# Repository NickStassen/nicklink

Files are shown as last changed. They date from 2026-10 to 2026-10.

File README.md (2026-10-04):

# NickLink v1.3

NickLink is a compact STM32F103C8T6 development and breakout board. Version 1.3 is a **34.0 × 25.5 mm, two-layer PCB** with an on-board **6-axis IMU (ST LSM6DSV)** for motion tracking, robotics and tap-to-wake projects. It also has two **2×10, 2.54 mm headers**, **four M2 mounting holes**, USB-C, RESET and BOOT buttons, a user LED, and **every header pin labelled on the front silkscreen**.

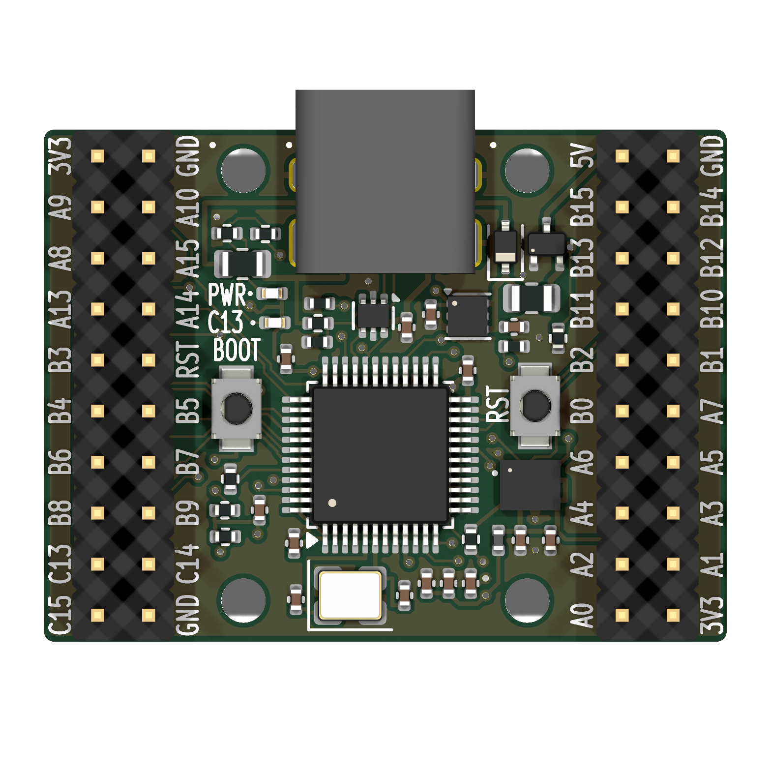
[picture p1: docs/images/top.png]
NickLink v1.3 — component side


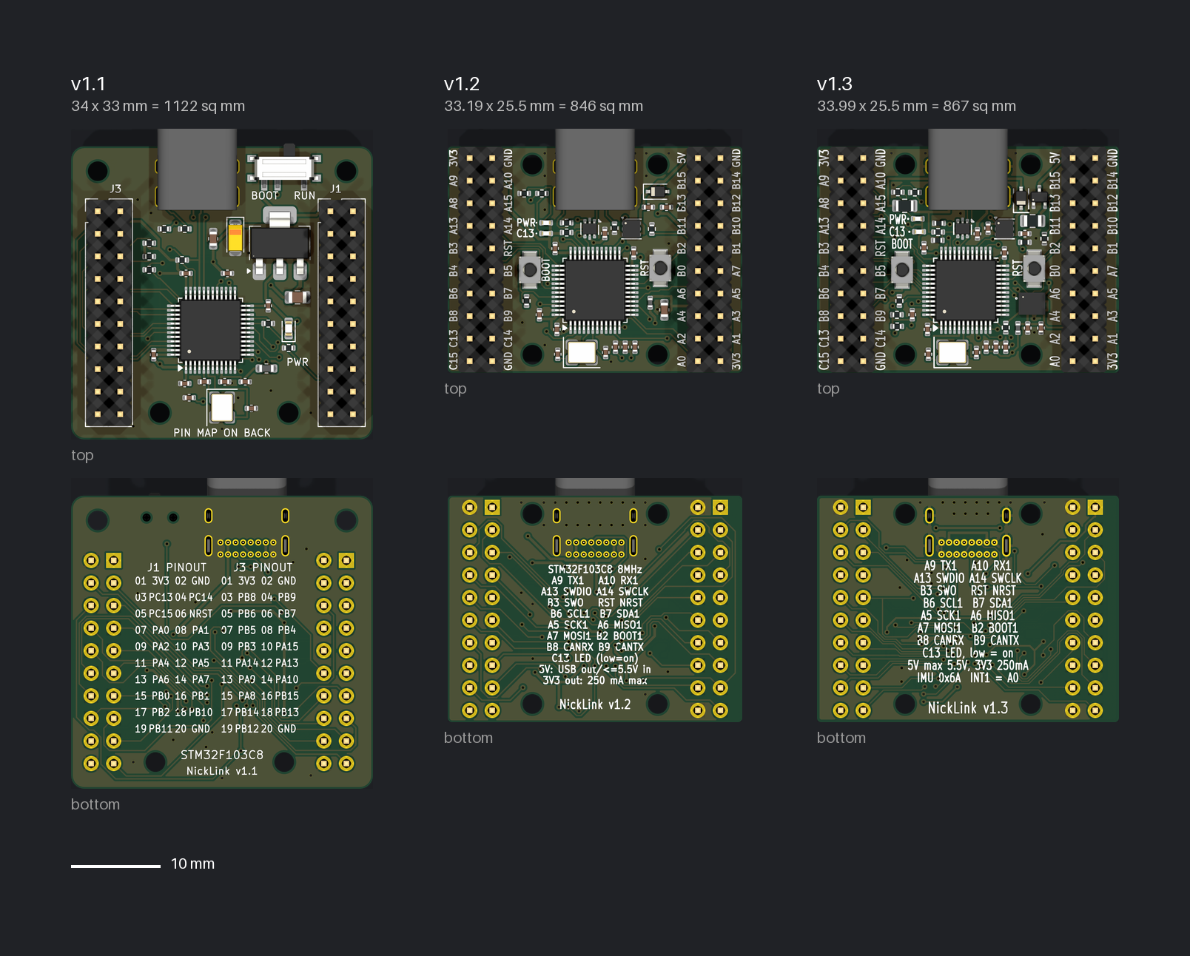
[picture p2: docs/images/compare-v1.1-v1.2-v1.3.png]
v1.1, v1.2 and v1.3 at the same scale


<details><summary>True size on a 27-inch 1440p monitor (view at 100% zoom)</summary>

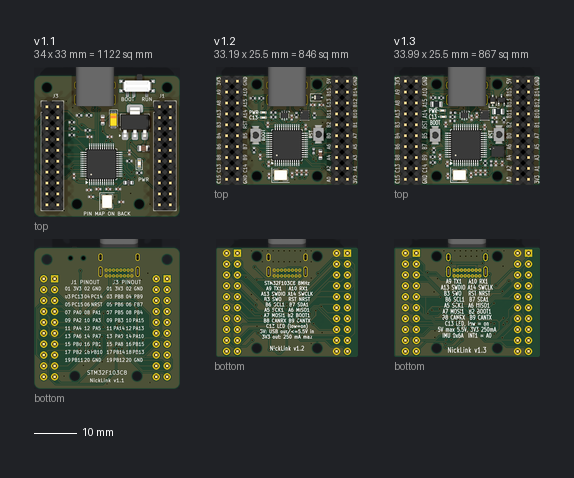
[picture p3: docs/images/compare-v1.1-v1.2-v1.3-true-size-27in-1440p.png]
v1.1, v1.2 and v1.3 at true size on a 27-inch 1440p monitor


</details>

**New board?** Follow the [bring-up guide](docs/BRINGUP.md): wiring for an STLINK-V3MINIE, a prebuilt test firmware and a checklist for every part.

## What changed

**v1.3** adds the IMU on I2C1. It fits into existing gaps beside the MCU, on the top side with single-sided assembly. The board is 0.8 mm wider than v1.2 only because the pin labels grew to JLC's 1.0 mm minimum text height (see [JLCPCB design rules](#jlcpcb-design-rules)). PB6/PB7 get 4.7 kΩ pull-ups again, because the bus now has an on-board device. The IMU's INT1 drives PA0. The 3V3 budget drops by about 1 mA for the IMU. Everything else is as in v1.2.

**v1.3 reliability pass** (from a five-reviewer audit, the SPICE benches in [`sim/`](sim/) and ST's AN2586/AN4879 checklists):

- **Hot-plug damping:** R12, 1 Ω in series with VBUS, holds the USB hot-plug peak to 5.38 V and inrush under 50 µC. A ring on the 5V pin can still go higher. The regulator survives that because it is the 18 V TLV76733, not because every peak stays under 6 V.
- **Protected 5V pin:** J1.1 now has a 0.5 A polyfuse (F1) and a reverse-polarity P-MOSFET (Q1), so a short or a reversed supply no longer reaches VSYS unprotected.
- **D+ pull-up from VBUS** (AN4879 §3.1.1): it is present only while USB is plugged in. Powering from J1.1 no longer back-feeds the host.
- **Decoupling:** C4 at VDD3 is now 4.7 µF, as DS5319 requires. C12 (LDO input) is 4.7 µF, to keep inrush down.
- **User LED:** R6 is 330 Ω: about 1.3 mA instead of 0.4 mA, still within PC13's 3 mA sink limit.
- **Routing:** locked tracks for the USB-C orientation ties and the IMU's 3V3 feed. Every GND pad and pour island is checked for connection.

**Revision comparison:**

| | v1.1 | v1.2 | v1.3 |
|---|---|---|---|
| Outline | 34 × 33 mm (1122 mm²) | **33.19 × 25.5 mm** (846 mm², −25%) | **33.99 × 25.5 mm** (867 mm², −23%) |
| Pin labels | Numbered table on the back | **Name beside every pin on the front**; cheat sheet on the back | Same; 1.0 mm text (JLC minimum) |
| 5 V on the headers | None | **J1.1 = 5 V** (USB VBUS through a Schottky; also a 5 V input) | Same, plus a **0.5 A polyfuse and reverse-polarity protection** |
| USB power path | VBUS straight to the regulator | Schottky | **1 Ω hot-plug damping** + Schottky |
| Regulator | AMS1117-3.3 (SOT-223) + 22 µF tantalum | **TLV75533** (2×2 mm WSON) + ceramics | **TLV76733**, same package, input rated to 18 V |
| Reset | Header pin only | **RESET button** + NRST on J3 next to SWD | Same |
| Boot | BOOT0 slide switch | **BOOT button** (hold BOOT, tap RESET) | Same |
| SWD | Split across J1 and J3 | **All on J3**: 3V3, GND, SWDIO, SWCLK, SWO, NRST | Same |
| HSE crystal | 16 MHz | **8 MHz** (matches Blue Pill / STM32duino / CubeMX defaults) | Same |
| USB D+ pull-up | 1.5 kΩ to 3V3 | 1.5 kΩ to 3V3 | **From VBUS** (2.2k/4.7k), so no back-feed when powered from J1.1 |
| USB ESD | None | **USBLC6-2P6** on D+/D− and VBUS | Same |
| I2C pull-ups | 1.5 kΩ fitted on PB6/PB7 | Removed | **4.7 kΩ** (needed by the on-board IMU) |
| LEDs | Power | Power + **user LED on PC13** (low = on) | Same, brighter (330 Ω, about 1.3 mA) |
| IMU | — | — | **LSM6DSV** 6-axis accel + gyro with on-chip sensor fusion |
| Verification | — | DRC/ERC | DRC/ERC, SPICE benches ([`sim/`](sim/)), emulated test firmware ([`firmware/`](firmware/)) |

## Hardware

- STM32F103C8T6 (LQFP-48) with an 8 MHz crystal (12 pF load, 15 pF C0G caps): PLL ×9 = 72 MHz, USB clock 72 / 1.5 = 48 MHz.
- USB-C (GCT USB4085, through-hole) for power and USB full speed; 5.1 kΩ CC pull-downs for either orientation; D+ pull-up from VBUS (2.2 kΩ / 4.7 kΩ divider, 1.5 kΩ to 3.4 V, so it is present only while USB is plugged in); USBLC6-2P6 ESD array.
- Power path: USB VBUS → R12 1 Ω (hot-plug damping) → 1N5819WS Schottky → **VSYS** → TLV76733 LDO → **3V3** (J3.1, J1.20). VSYS also reaches the **5V pin** (J1.1) through a 0.5 A polyfuse (F1) and a reverse-polarity P-MOSFET (Q1). The Schottky stops a supply on the 5V pin from back-feeding the USB host.
- RESET button (NRST to GND, 100 nF), BOOT button (BOOT0 to 3V3, 10 kΩ pull-down), 10 kΩ pull-down on PB2/BOOT1.
- Red power LED, green user LED on PC13 (active low).
- **IMU:** ST LSM6DSV 6-axis accelerometer and gyroscope on I2C1 (PB6 SCL / PB7 SDA, address **0x6A**), INT1 to PA0.
- 33 GPIO + NRST on the headers. Only PA11/PA12 (USB) and PD0/PD1 (crystal) are not broken out.
- GND pours on both layers, stitched with vias.

## Header pinout

**Top view, USB at the top: J3 is left, J1 is right.** Pin 1 is the square pad at the upper left of each header; odd pins are the left column. The front silkscreen prints each pin's name right beside it (`A9` = PA9, `B12` = PB12, `RST` = NRST).

| Pin | J3 (left) | J1 (right) |
|---:|---|---|
| 1 | `3V3` 3V3 regulated output | `5V` 5 V (USB VBUS through Schottky + 0.5 A polyfuse; 4.5–5.5 V input, reverse-polarity protected) |
| 2 | `GND` | `GND` |
| 3 | `A9` PA9 / UART1 TX | `B15` PB15 / SPI2 MOSI |
| 4 | `A10` PA10 / UART1 RX | `B14` PB14 / SPI2 MISO |
| 5 | `A8` PA8 | `B13` PB13 / SPI2 SCK |
| 6 | `A15` PA15 | `B12` PB12 |
| 7 | `A13` PA13 / SWDIO | `B11` PB11 / I2C2 SDA / UART3 RX |
| 8 | `A14` PA14 / SWCLK | `B10` PB10 / I2C2 SCL / UART3 TX |
| 9 | `B3` PB3 / SWO | `B2` PB2 / BOOT1, 10k pull-down |
| 10 | `RST` NRST (reset, active low; 3.3 V only) | `B1` PB1 (3.3 V only) |
| 11 | `B4` PB4 | `B0` PB0 (3.3 V only) |
| 12 | `B5` PB5 (3.3 V only) | `A7` PA7 / SPI1 MOSI (3.3 V only) |
| 13 | `B6` PB6 / I2C1 SCL (4.7k pull-up, IMU; 3.3 V only) | `A6` PA6 / SPI1 MISO (3.3 V only) |
| 14 | `B7` PB7 / I2C1 SDA (4.7k pull-up, IMU; 3.3 V only) | `A5` PA5 / SPI1 SCK (3.3 V only) |
| 15 | `B8` PB8 / CAN RX (remap) | `A4` PA4 (3.3 V only) |
| 16 | `B9` PB9 / CAN TX (remap) | `A3` PA3 / UART2 RX (3.3 V only) |
| 17 | `C13` PC13 / user LED (3.3 V only) | `A2` PA2 / UART2 TX (3.3 V only) |
| 18 | `C14` PC14 (3.3 V only) | `A1` PA1 (3.3 V only) |
| 19 | `C15` PC15 (3.3 V only) | `A0` PA0 / WKUP / IMU INT1 via 10k (3.3 V only) |
| 20 | `GND` | `3V3` 3V3 regulated output |

Pins not marked "3.3 V only" are 5 V tolerant (FT) while the board is powered. B6/B7 are FT on the MCU but not at board level, because the IMU on that bus is limited to 3.6 V. PA1–PA7, PB0 and PB1 are also ADC inputs. PA0 is too, but it has the IMU interrupt on it (below). [`docs/pinout.csv`](docs/pinout.csv) has the same table in machine-readable form.

- **SWD:** J3.1 3V3 (target voltage sense), J3.2 GND, J3.7 SWDIO, J3.8 SWCLK, J3.10 NRST, optional J3.9 SWO.
- **Serial bootloader:** hold BOOT, tap RESET, release BOOT, then use USART1 on J3.3 (TX) / J3.4 (RX). This is ST's factory USART bootloader; the F103 has no factory USB DFU bootloader.
- **I2C1 / IMU:** I2C1 has on-board 4.7 kΩ pull-ups. External I2C modules can share the bus as long as they avoid address 0x6A and **pull up to 3.3 V only**. A 5 V module needs a level shifter, because the IMU's SCL/SDA limit is 3.6 V. If modules bring their own pull-ups, keep the combined value above about 1.5 kΩ. The 4.7 kΩ pull-ups meet the 400 kHz rise-time limit up to about 75 pF of bus capacitance (roughly 30 cm of wiring plus a few modules); for longer runs, use 100 kHz.
- **A0 has the IMU's INT1 on it through 10 kΩ.** INT1 drives low whenever no interrupt is asserted, so A0 always sees a 10 kΩ pull-down (also with INT1 set to open-drain, which only releases the pin while active-high). The interrupt is active high, matching WKUP's rising edge. You can still drive A0 from outside, or use it as an ADC input from a low-impedance source. Making A0 truly high-impedance needs INT1 set active-low open-drain (`H_LACTIVE` + `PP_OD`, IF_CFG 03h), which inverts the interrupt and stops it from waking the MCU through WKUP.
- **J3.6/J3.9/J3.11 (PA15/PB3/PB4) are JTAG pins at reset:** PA15 and PB4 have internal pull-ups and PB3 (JTDO/SWO) has none, until firmware frees them (`__HAL_AFIO_REMAP_SWJ_NOJTAG()` keeps SWD and releases them). PA13/PA14 stay SWD unless you disable SWJ completely, after which the debugger has to connect under reset (NRST is on J3.10).
- **User LED:** PC13 low turns it on. PC13–PC15 are low-drive pins (≤2 MHz) and must not source current. Their 3 mA sink limit is shared by all three pins (DS5319 Table 5), and the LED already takes about 1.3–1.8 mA of it. J3.17 carries the LED load, so an undriven PC13 floats around 1–1.5 V.

## IMU

The LSM6DSV is a 6-axis IMU: accelerometer up to ±16 g, gyroscope up to ±4000 dps.
- **Address:** I2C1 at 0x6A (SA0 tied low); CS is tied high for I2C mode.
- **Interrupt:** INT1 goes to PA0. PA0 is also the STM32's WKUP pin, so a tap or motion interrupt (rising edge) can wake the MCU from Standby.

Features useful here:
- **On-chip sensor fusion (SFLP):** outputs a game rotation vector (quaternion) at 15–480 Hz through the FIFO. The F103 has no hardware floating point, so this saves it doing the orientation math.
- **Hardware event detection:** tap, double-tap, wake-up, free-fall and 6D-orientation events, routable to INT1 (MD1_CFG 5Eh, with INTERRUPTS_ENABLE set in FUNCTIONS_ENABLE 50h). This covers tap-activated projects without polling.

Firmware starting points: ST's LSM6DSV platform-independent C driver, or the LSM6DSV16X one (`lsm6dsv16x-pid`) restricted to features the LSM6DSV has. Bring-up check: WHO_AM_I (0Fh) should read **0x70**.

**Why the LSM6DSV and not the LSM6DSV16X:** v1.3 was designed around the LSM6DSV16X (C5267406), but JLC lists that part as "Standard PCBA only" (X-ray inspection), and NickLink is an Economic PCBA board. The LSM6DSV (C41785564, which JLC lists as "LSM6DSVETR" and allows on Economic PCBA) is its sibling in the same LGA-14 package, with the same pinout, I2C-mode wiring, register map, WHO_AM_I and SFLP fusion. It lacks the LSM6DSV16X's machine-learning core, Qvar electrostatic sensing and analog hub. None of these is used here: Qvar and the analog hub need pins 2/3, which are tied to GND. The board and the test firmware are unchanged. ST's own store lists the part as LSM6DSV/LSM6DSVTR, so the "LSM6DSVETR" code is JLC's/LCSC's; confirm WHO_AM_I and SFLP output on the first boards.

Placement follows ST's LGA guidance: the IMU sits on the top side, with no ground pour or vias under the package, and only short pad-to-pad links at its edges. The local wiring is pre-routed; see docs/REVIEW.md. It sits in the right channel beside the MCU, below the RESET button, away from the regulator's heat and USB cable strain. ST's guidance of about 10 mm from screws (in its MEMS layout notes) can't be met on a board this small; H4 is about 2.4 mm from the IMU body. Mount on standoffs without over-tightening, since board flex shows up as accelerometer offset.

## Power

- **5V pin (J1.1), as an output:** VSYS through F1 (0.5 A hold, 1 A trip) and Q1. On USB that is VBUS minus the drop across R12, D2, F1 and Q1:
  - About 4.7 V at light load.
  - 4.2–4.4 V with 200 mA drawn from J1.1, from a 5.0 V port. From a 4.75 V port it is 4.0–4.1 V, so 5 V modules that need at least 4.5 V may not run.
  - A short from J1.1 to the adjacent GND pin trips F1 in about 0.1 s. VSYS collapses meanwhile, so the MCU resets once; the board recovers when the short is removed.
  - F1's hold current falls to about 0.33 A at 60 °C.
- **5V pin (J1.1), as an input:** apply 4.5–5.5 V and **do not exceed 5.5 V** in steady state. The parts behind it are rated higher (regulator 18 V, C12 and F1 16 V, Q1 gate ±12 V), so plug-in overshoot is survivable with normal leads. Q1 blocks a reversed supply, and F1 limits the current. D2 keeps J1.1 from back-feeding the USB host. With USB unplugged, the D+ pull-up is unpowered, so the host sees no device until USB is connected. Don't connect a battery to J1.1 while USB is plugged in: USB would charge it through F1 and Q1.
- **3V3 pins (J3.1, J1.20):** LDO outputs. Budget about **250 mA total including the MCU** when powered from USB. That figure is an estimate for this two-layer board (with two thermal vias under the LDO), not a measured limit. From a 5.5 V input on J1.1, keep below about 200 mA. **Do not feed 3V3 in from outside**: the regulator isn't specified for reverse current.
- **Hot-plug:** cables ring when plugged into a live supply. SPICE (`sim/` benches 11 and 12):
  - **USB:** with R12 fitted, the worst-case regulator input peak is 5.38 V for cables up to 1 µH (6.1–11.4 V without R12), and 7.3 V for an unusually long 3 µH cable. Inrush is 33 µC (USB limit 50 µC). R12 costs about 0.25 V of headroom at 250 mA.
  - **J1.1:** this path has no R12, so plugging a live supply onto J1.1 rings VSYS to about 5.4–9 V. That is why the regulator is the 18 V TLV76733.
  - **Bench leads over about 1 µH:** with these on J1.1, connect first and then switch the supply on. The most pessimistic capacitor model puts the ring past Q1's 12 V gate rating.

## Mounting

Four 2.2 mm holes for M2 screws. The keep-out is sized for **button-head (ISO 7380, 3.5 mm head)** screws and standoffs up to 4 mm across. Coordinates are measured from the board's upper-left corner, top view, X right, Y down.

| Hole | X (mm) | Y (mm) |
|---|---:|---:|
| H1 | 9.93 | 2.05 |
| H2 | 24.06 | 2.05 |
| H3 | 9.93 | 23.45 |
| H4 | 24.06 | 23.45 |

The USB-C receptacle overhangs the top edge by about 2 mm, as in v1.1.

## Open and edit

Open [`nicklink.kicad_pro`](nicklink.kicad_pro) in **KiCad 10**. The schematic, PCB, rules and project-local footprints (`nicklink.pretty/`) are included.

NickLink is generated by scripts in [`tools/`](tools/README.md). [`tools/spec.py`](tools/spec.py) is the single source of truth for parts, nets and header pinout, and [`tools/placement.py`](tools/placement.py) holds component positions. `tools/build_all.sh` regenerates the schematic, places parts, autoroutes with Freerouting, stitches the GND pours and runs DRC. It writes `nicklink.kicad_pcb` only if everything is clean. Everything runs in Docker (`kicad/kicad:10.0`); no local KiCad install is needed.

| Location | Contents |
|---|---|
| `nicklink.kicad_sch` / `.kicad_pcb` / `.kicad_pro` | Generated schematic, routed board, design rules |
| `nicklink.pretty/` | Project footprints: USB4085, plus header and button copies without silkscreen (the board draws its own labels) |
| `tools/` | Build pipeline, see [tools/README.md](tools/README.md) |
| `docs/` | [Design review](docs/REVIEW.md), pinout CSV, schematic, assembly and copper PDFs, renders |
| `fabrication/v1.3/` | Gerbers, drills, JLC BOM and CPL |
| `fabrication/v1.1/`, `v1.2/` | Previous revisions' outputs, kept for reference |
| `checks/` | Saved DRC/ERC reports for v1.3 |

## JLCPCB design rules

The board is checked against JLCPCB's published 2-layer and assembly limits ([PCB capabilities](https://jlcpcb.com/capabilities/pcb-capabilities), [assembly capabilities](https://jlcpcb.com/capabilities/pcb-assembly-capabilities), checked 2026-10-01). The limits are encoded in the board setup and `nicklink.kicad_dru`, so every DRC run enforces them.

| JLC limit | NickLink |
|---|---|
| Trace / space ≥ 0.10 / 0.10 mm | ≥ 0.10 mm tracks (0.127 mm signals, 0.2 mm GND and 3V3, 0.3 mm VBUS/5 V), 0.127 mm clearance |
| Via ≥ 0.15 mm drill / 0.25 mm diameter | 0.3 / 0.6 mm |
| Component PTH annular ring ≥ 0.18 mm | ≥ 0.18 mm. The USB4085 pads change from GCT's 0.40/0.65 mm (0.125 mm ring) to a 0.38 mm hole in a 0.74 mm pad, which stays within GCT's 0.40 ± 0.05 mm hole spec for the 0.22 × 0.15 mm pins. The pad gap is 0.11 mm, above JLC's 0.10 mm. The LDO's two thermal vias are 0.3 mm in 0.66 mm pads. |
| Pad hole-to-hole ≥ 0.45 mm; plated slot ≥ 0.5 mm | ≥ 0.47 mm (USB4085 0.85 mm pitch, 0.38 mm holes); 0.6 mm shield slots |
| SMD pad to pad ≥ 0.15 mm | ≥ 0.15 mm (the IMU's LGA is the tightest) |
| Copper to routed edge ≥ 0.2 mm (≥ 0.3 mm for Economic assembly) | 0.3 mm |
| Solder-mask web ≥ 0.10 mm | 0.10 mm minimum checked |
| Silkscreen line ≥ 0.15 mm, text ≥ 1.0 mm, silk to pad ≥ 0.15 mm | All silk ≥ 0.15 mm wide; labels 1.0 mm tall; labels 0.15 mm from pads and the edge. The library 0402 footprints' own silk sits about 0.09 mm from their pads; JLC clips it. |
| Component bodies ≥ 0.3 mm apart, IPC-7351B medium density | KiCad library courtyards (IPC nominal), none overlapping |
| Economic assembly: components ≥ 0.3 mm from edge, pitch ≥ 0.4 mm, passives ≥ 0201 | SMD bodies ≥ 1 mm from the edge; finest pitch 0.5 mm; 0402 passives |

**Ordering:**
- Under 70 × 70 mm, so order **Economic PCBA**. Economic needs no on-board fiducials or rails. JLC can add edge rails and fiducials if you choose Standard or panelize; on-board fiducials would need 3.85 mm from the edge.
- Choose an **ENIG** finish: the 0.5 mm-pitch LGA and LQFP solder more reliably on a flat pad than on HASL. On Economic PCBA, 1.6 mm ENIG comes only with **green** solder mask. Avoid black or white anyway: JLC only keeps a mask bridge between pads 0.13 mm or more apart on those colours (0.10 mm on green), and the USB-C pads are 0.11 mm apart.
- The CPL is in Gerber coordinates, so JLC aligns it to the board without an "offset" prompt. Its rotations and positions are corrected per LCSC part for JLC's own footprints (`JLC_ROT`/`JLC_OFS` in `tools/fab.sh`: LQFP-48 −90°; SOT-666 and SOT-323 +180°; the 2×10 headers −90° and centred; USB4085 origin offset). Still check the pin-1 marks in JLC's placement preview.
- JLC also assembles the through-hole parts (USB-C, headers; wave soldered), so the BOM has one line per LCSC part, THT included. The USB-C GND pins use thermal reliefs, which also helps if you ever hand-solder a replacement.
- Signal tracks, and VBUS_D (USB power) under H1, pass under the M2 screw heads (under solder mask, vias tented). Use plastic standoffs or washers if you clamp with metal hardware.

## Validation and fabrication

KiCad 10.0.6: **0 DRC violations, 0 unconnected items, 0 schematic-parity issues, 0 ERC errors or warnings** (reports in [`checks/`](checks/)). Every pin in the schematic netlist is checked against `tools/spec.py`. These checks cover connectivity and geometry. This revision has not been built yet; it needs a prototype and bench testing (see [`docs/BRINGUP.md`](docs/BRINGUP.md)).

The BOM carries verified LCSC part numbers for every part, through-hole included. To order, upload `fabrication/v1.3/nicklink_gerbers.zip`, then for assembly `nicklink_BOM_JLC.csv` and `nicklink_CPL.csv`. Several parts are JLC "Extended" parts, which add a per-part loading fee; see [`tools/parts_research.md`](tools/parts_research.md).

**Bring-up and board test:** [`docs/BRINGUP.md`](docs/BRINGUP.md) walks through the first power-up of a new board, wiring an STLINK-V3MINIE to J3, flashing the prebuilt test firmware ([`firmware/prebuilt/`](firmware/prebuilt/)) and a 14-step checklist. The checklist covers power, crystal, LEDs, buttons, IMU, every header GPIO, ADC and Standby wake.

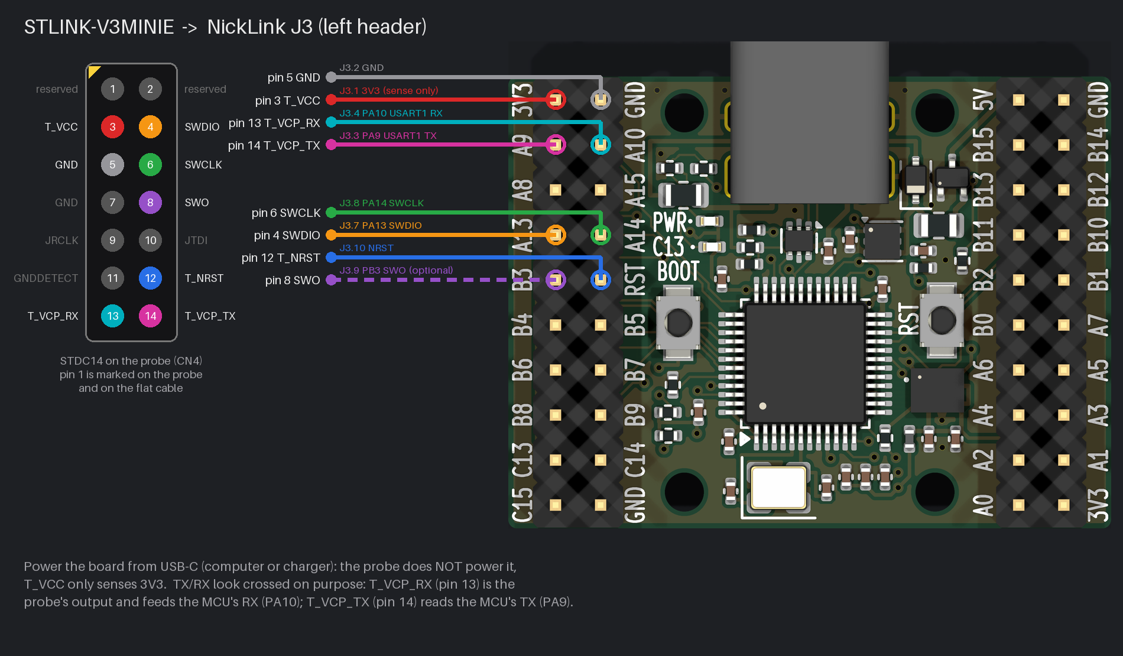
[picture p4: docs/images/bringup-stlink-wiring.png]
STLINK-V3MINIE to NickLink wiring


**Interface limits:**

- USB and CAN cannot run at the same time on the F103 (they share packet RAM).
- **I2C1 is always in use by the IMU (PB6/PB7).**
  - Remapping SPI1 to PA15/PB3/PB4/PB5 while I2C1 is clocked breaks MOSI on PB5 (erratum ES096). Gate the I2C1 clock off while SPI1 is remapped.
  - Using PB6/PB7 for USART1-remap or TIM4 disturbs the IMU's bus.
  - Remapping I2C1 to PB8/PB9 disconnects the IMU and takes the CAN pins.
- **Never set the IMU's `IF_CFG.I2C_I3C_disable` bit.** With CS tied high and no power switch on the IMU, only a full power cycle recovers it.
- CAN uses PB8/PB9 through the remap and needs an external transceiver.
- USB impedance and compliance are not qualified.

**Firmware notes for reliability:**

- The F103 has power-on/power-down reset but **no brown-out reset**. Enable the PVD (for example at 2.9 V) and stop flash writes when it trips.
- Enable the clock security system (CSS). If the HSE fails, the MCU falls back to HSI. USB cannot run from HSI, so treat that as a fault.
- Do not drive header pins while the board is unpowered. Keep injected current within ±5 mA per pin; PA4, PA5 and PC13–PC15 tolerate none.
- Set unused pins to analog input (the lowest-power, defined state) and free JTAG with `NOJTAG` if PA15/PB3/PB4 are used as GPIO.

**Simulation and test firmware:** [`sim/`](sim/) holds ngspice benches for hot-plug, LDO, brown-out, reset, LEDs, I2C, VDDA and the crystal, with results in `sim/results/summary.md`. [`firmware/`](firmware/) is a bring-up firmware for this pinout. It exercises the user LED, RESET, every header GPIO, the IMU (including tap wake on A0), USART1 and the HSE/PLL with HSI fallback, and runs under Renode emulation (`firmware/test.sh`) before you flash the real board.

## References

- [ST STM32F103x8/xB datasheet](https://www.st.com/resource/en/datasheet/stm32f103c8.pdf)
- [ST AN2586 — hardware design](https://www.st.com/resource/en/application_note/an2586-getting-started-with-stm32f10xxx-hardware-development-stmicroelectronics.pdf)
- [ST AN2867 — oscillator design](https://www.st.com/resource/en/application_note/an2867-guidelines-for-oscillator-design-on-stm8afals-and-stm32-mcusmpus-stmicroelectronics.pdf)
- [TI TLV767 datasheet](https://www.ti.com/lit/ds/symlink/tlv767.pdf) (U2 from v1.3); [TLV755P](https://www.ti.com/lit/ds/symlink/tlv755p.pdf) (v1.2)
- [ST LSM6DSV datasheet](https://www.st.com/resource/en/datasheet/lsm6dsv.pdf)
- [ST USBLC6-2 datasheet](https://www.st.com/resource/en/datasheet/usblc6-2.pdf)

Licensed under the [MIT License](LICENSE).

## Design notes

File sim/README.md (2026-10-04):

# NickLink v1.3 power and analog SPICE suite

ngspice testbenches for the power and analog parts of the board: USB hot-plug, the LDO, brown-out, NRST, the LEDs, I2C edges, the HSE crystal and the VDDA filter. Part values come from `tools/spec.py`.

## Run

```sh
sim/run.sh               # all testbenches, then plots + results/summary.md (~1 min)
sim/run.sh hotplug i2c   # only testbenches whose name contains one of the words
python3 sim/analyze.py   # rebuild plots/summary from existing results/*.dat
python3 sim/xtal.py      # crystal numbers only (with a self-check)
```

ngspice runs in a throwaway Docker image (`nicklink-ngspice`, Ubuntu 24.04 + ngspice 42). `run.sh` builds it from `sim/Dockerfile` the first time, so nothing is installed on the host. Plotting uses the host's python3 + numpy + matplotlib. `sim/.spiceinit` turns on PSpice compatibility (`ngbehavior=psa`), which the TI model needs.

Outputs go to `sim/results/`: `summary.md` (the full report, generated), `*.png` plots, and raw `*.dat` / `*.log` (ignored by git).

| File | |
|---|---|
| `tb/01_hotplug.cir` … `tb/12_j11_hotplug.cir` | Testbenches. Each header says what it checks and what counts as pass. |
| `models/TLV75533P_TRANS.lib` | **TI vendor model**, SBVM831 "TLV75533P Unencrypted PSpice Transient Model" (ti.com/lit/zip/SBVM831), unmodified |
| `models/parts.lib` | Fitted models: 1N5819WS, USBLC6 VBUS Zener, SMF5.0A, BLM15AG121 ferrite, Everlight LEDs, switch, DMP2165UW (Q1, gate at GND) |
| `models/caps.lib` | MLCCs with DC-bias derating |
| `models/board.lib` | The +5V → 3V3 / VDDA rail as one subcircuit (U2, C8, C5, C1–C4, C14, C15, FB1, C6, C7, D1+R3) |
| `analyze.py` | Metrics, verdicts, plots, `results/summary.md` |
| `xtal.py` | Test 7, AN2867 calculation |

## Models and assumptions

- **TLV75533P:** the TI transient model runs in ngspice unchanged. Testbenches add `.ic v(…u1_n08530)=0`, because ngspice ignores the soft-start capacitor's `IC=0` without UIC. Checked against datasheet Fig. 5-8 (1→500 mA, 1 µF): the model gives −64 / +41 mV, the datasheet shows about −60 / +70 mV. Limits of the model:
  - **No small-signal loop.** The output is a behavioural source behind 36 mΩ, so phase margin cannot be simulated. Its load-step dip also barely depends on COUT, so the step results are conservative for this board's 6.6 µF.
  - Dropout is a fixed 150 mV at any load. The datasheet gives 0.30 Ω typ / 0.43 Ω max at 500 mA. Test 3 reports both.
  - No VIN absolute-maximum behaviour. Test 1 compares the +5V peak against 6.0 V instead.
  - It has UVLO (1.3 V), foldback current limit and the 120 Ω discharge.
- **USBLC6-2P6:** ST's model could not be downloaded (st.com blocks scripted access). The VBUS–GND Zener is behavioural: BV ≥ 6 V (datasheet minimum only) with 1.25 Ω dynamic resistance, from VCL 12 V @ 1 A / 17 V @ 5 A. BV is swept over 6 V and 9 V (9 V is an assumed weak sample).
- **MLCC derating:** C(V) = C0 / (1 + (V/V0)²), roughly fitted to published Samsung/Murata DC-bias curves (±15 %, 25 °C, no ageing):

  | Part | At 3.3 V | At 5 V |
  |---|---:|---:|
  | 10 µF 0603 X5R 10 V | 55 % | 35 % |
  | 1 µF 0402 X5R 25 V | 60 % | 40 % |
  | 100 nF 0402 X7R 16 V | 80 % | 64 % |

  C12 and C13 use a voltage-dependent C in the hot-plug test. Everything else uses the linear value at its rail voltage, because ngspice's behavioural capacitor stalls when a node sits still next to the TI model.
- **DMP2165UW (Q1):** body diode drain → source (0.7 V at 1 A) plus a two-way channel switch, on while V(5V_F) > 1.2 V, 90 mΩ (the gate is tied to GND).
- **1N5819WS:** fitted to the Hottech typical curve (0.30 V @ 100 mA, 0.37 V @ 500 mA).
- **LEDs:** fitted through VF at 20 mA (datasheet min/typ/max bins) and the typical IV curve near 1 mA. The low-current end of the min/max bins is assumed.
- **Ferrite (BLM15AG121SN1D):** 0.10 Ω + (0.45 µH ∥ 150 Ω ∥ 1 pF), about 120 Ω at 100 MHz. This is approximate; Murata's netlist was not used.
- **STM32F103 limits** (DS5319):
  - VDD minimum 2.0 V.
  - PDR 1.80 / 1.88 / 1.96 V, tRSTTEMPO 1–4.5 ms.
  - NRST: RPU 30/40/50 kΩ, VIL 0.8 V, VIH 2.0 V, a pulse ≥ 300 ns is always recognised.
  - PC13 sinks ≤ 3 mA.
  - HSE gm ≥ 25 mA/V.
- **Hot-plug source:** an ideal 5.5 V step (USB-C vSafe5V maximum) with a 10 ns contact closure. This is the worst case: a real host adds its own bulk capacitance, ESR and contact bounce.

## What each test checks

1. **USB hot-plug.** Cable L 0.5/1 µH × R 0.1/0.3 Ω, USBLC6 BV 6/9 V, 8 circuit variants. Pass if the +5V peak is ≤ 5.75 V; 5.75–6.0 V is MARGIN; above 6.0 V (TLV755 VIN absolute maximum) is FAIL. Inrush charge must be ≤ 50 µC (USB 2.0 §7.2.4.1, equal to 10 µF at 5 V).
2. **LDO.** Start-up (monotonic, overshoot < 3 %) and load steps 0→50→250→50→0 mA with 1 µs edges, fed from VBUS = 5.0 V and 4.40 V through R12 and D2 (so each load step is also a line step on VSYS). Pass if 3V3 stays within 3.3 V ±3 % and settles within 10 mV in < 100 µs. Stability is checked against TI's capacitor condition, because the model has no loop.
3. **Brown-out.** VSYS (LDO IN) ramps down at 50 and 250 mA constant-current loads. Records the VSYS level (and the VBUS equivalent, VSYS + VF + I·R12) at which 3V3 crosses 3.2 V, 3.0 V, 2.0 V and PDR, plus the D2 drop at 100/250/500 mA.
4. **NRST.** Power-on RC delay over the RPU range, RESET press and release, the internal 20 µs reset pulse against 100 nF, and the BOOT0 levels.
5. **LEDs.** D1 and D3 current over the VF bins at the as-built R6 = 330 Ω, plus an R6 sweep, with ≤ 3 mA at the minimum-VF bin.
6. **I2C.** Rise and fall times with 4.7 kΩ and 20/40/100 pF at 400 kHz (tr ≤ 300 ns) and 100 kHz (tr ≤ 1000 ns).
7. **Crystal (analytic, `xtal.py`).** AN2867 gm_crit and gain margin, load capacitance and frequency pulling, drive level against the 100 µW rating.
8. **VDDA filter.** AC transfer from 3V3 to VDDA, as built and with a damping resistor.
9. **Hot-plug fix candidates** (`tb/09_hotplug_fixes.cir`). The power reviewer's topology and its variants (A–D), plus follow-up candidates E–E'', all at the same corners as test 1. Pass needs all three: LDO IN peak ≤ 5.8 V, inrush ≤ 50 µC (full-bias estimate), and 3V3 still regulating at 500 mA with USB at 4.40 V.
10. **C12 as an RC snubber** (`tb/10_snubber_hotplug.cir`, `tb/10_snubber_loadstep.cir`). Topology A with no series R in the main path; instead C12 4.7 µF 0402 sits behind Rs (0.5 / 1.0 / 2.2 Ω), optionally with a 100 nF or 1 µF 0402 directly on VSYS. Reports hot-plug peak, inrush, Rs pulse power and energy, and load steps through a 1 µH cable. Pass: VSYS peak ≤ 5.8 V and inrush ≤ 50 µC.
11. **Hot-plug, current spec.py power path** (`tb/11_hotplug_v13.cir`, `NL_RAIL_V13` in `models/board.lib`). R12 swept over 1.0 (as built) / 1.5 / 2.2 Ω, same 8 corners. Also reports the drop and LDO IN at 250 / 500 mA from 4.40 V and 4.75 V, and R12 power.
12. **Hot-plug into J1.1, and long USB cables** (`tb/12_j11_hotplug.cir`). R12 is not in the J1.1 path: J1.1 → Q1 → F1 → VSYS. A stiff 5.0 / 5.5 V supply is stepped onto J1.1 through 0.1 µH / 30 mΩ (short stiff link) to 2 µH / 0.1 Ω (long bench leads), with F1 at 0.1 Ω (minimum) and 0.3 Ω (typical), and C12 both bias-dependent and linear 1.3 µF. The same bench steps USB through 1.5 / 2 / 3 µH cables at 5.25 / 5.5 V. U2 is passive (Iq only), so one run was scored two ways and was not re-run. The 6.0 V rows are the old TLV755 VIN/EN limit (not fitted). The fitted part is the TLV76733DRVR (18 V abs max); the limit used for that score is Q1's ±12 V VGS, with C12 and F1 at 16 V. Those fitted-part rows are "U2 -> TLV76733" in `results/summary.md` (J1.1 hot-plug MARGIN, long-cable USB PASS). Do not read a 6.0 V FAIL as the current board.

## Results (`results/summary.md` is regenerated on every run)

The table below shows the **as-built v1.3 rail** (R12, C12 4.7 µF 0402, R6 330 Ω, from `tools/spec.py`). `analyze.py` regenerates it between the markers. Bench 12 rows that compare VSYS with 6.0 V are the **old TLV755** limit, not the fitted TLV76733DRVR. The fitted-part scores are the "U2 -> TLV76733" rows in `results/summary.md` (J1.1 MARGIN, long USB cables PASS). The peaks were not re-simulated.
- Benches 2–4 and 11 use the current rail: R12 1 Ω, C12 4.7 µF 0402, C4 4.7 µF 0402 at VDD3, no C5.
- Bench 5 reports R6 = 330 Ω.
- Benches 6–8 are unchanged parts.
- The v1.3-original rows (C12 10 µF, C5 10 µF, no R12) are kept only where they explain why R12 was added.
- Fix studies (benches 1, 9 and 10 variants, the VDDA damping option, other R6 values) are in the second table of `results/summary.md`.

<!-- results:start -->
| Test | Check | Result | Verdict |
|---|---|---|---|
| 1 Hot-plug | As built (bench 11): R12 1 ohm, C12 4.7u 0402, C4 4.7u; LDO IN peak <= 5.8 V, inrush <= 50 uC | LDO IN pk 5.38 V, VBUS pk 6.17 V, inrush 33 uC, LDO IN @4.40 V/500 mA 3.53 V | **PASS** |
| 1 Hot-plug | As built: 3V3 at 500 mA from USB 4.40 V (above the 250 mA thermal budget) | LDO IN 3.53 V vs 3.538 V needed (max dropout); 3V3 ~3.29 V | **MARGIN** |
| 1 Hot-plug | v1.3 original (no R12, C12 10u, C5 10u) - why R12 was added: peak +5V vs 6.0 V abs max | 6.13..11.42 V | **FAIL** |
| 1 Hot-plug | v1.3 original - inrush charge vs USB 50 uC | 63 uC (C12 + 3V3 caps via soft-start) | **FAIL** |
| 12 J1.1 hot-plug | Old TLV755 limit, not fitted: 5.0 / 5.5 V supply plugged onto J1.1 (leads 0.1-2 uH, F1 0.1 / 0.3 ohm); VSYS <= 6.0 V. Fitted part is the TLV76733 row in the second table (MARGIN) | VSYS pk 5.42..9.17 V (linear C12), up to 19.3 V (bias C12); 2 of 20 corners <= 6.0 V | **FAIL (against 6.0 V only)** |
| 12 J1.1 hot-plug | Old TLV755 limit, not fitted: USB hot-plug, 1.5-3 uH cables (2-4 m), 5.25 / 5.5 V; LDO IN <= 6.0 V. Fitted TLV76733 score for this peak is PASS (<= 12 V) | <= 2 uH at 5.25 V: 5.92 V; worst (3 uH, 5.5 V): 7.34 V | **MARGIN (against 6.0 V only)** |
| 2 LDO | Start-up: monotonic, overshoot < 3 % | 367 us to 90 %, overshoot 0.02 % | **PASS** |
| 2 LDO | Load steps 0/50/250 mA, 1 us edges: within 3.3 V +-3 %, settle < 100 us | worst deviation 31 mV, settle 28 us | **PASS** |
| 2 LDO | Stability: TI condition COUT_eff >= 0.47 uF, nominal 1..200 uF, ceramic ESR (vendor model has no loop, no phase margin) | COUT_eff 3.2 uF; C8 alone 0.60 uF | **PASS** |
| 3 Brown-out | Min VBUS for regulation at 250 mA (USB min 4.75 V, 4.40 V at a bus-powered hub) | VBUS >= 4.01 V (datasheet-max dropout + VF + 250 mA x R12) | **PASS** |
| 3 Brown-out | Window VDD < 2.0 V (spec min) before PDR (1.80..1.96 V) resets the MCU | VSYS 2.16 -> 1.96 V (200 mV of input sag, unprotected) | **MARGIN** |
| 3 Brown-out | Schottky D2 drop at 100 / 250 / 500 mA | 0.30 V / 0.34 V / 0.37 V | **PASS** |
| 4 NRST | Power-on: NRST to VIH 2.0 V after VDD = 2.0 V (RPU 30..50 k, C9 100 nF), budget 20 ms | <= 3.7 ms (on top of the chip's own 1..4.5 ms POR delay) | **PASS** |
| 4 NRST | RESET button: NRST < 0.8 V in < 1 us, held >= 300 ns; release time | release 3.7 ms | **PASS** |
| 4 NRST | Internal 20 us reset pulse pulls 100 nF below VIL (assumed 50 ohm driver) | yes | **PASS** |
| 4 NRST | BOOT0: 10 k pull-down, button to 3V3 | pressed 3.3 V / released 0 V, 0.33 mA while pressed | **PASS** |
| 5 LEDs | Red D1 with R3 1k5, all VF bins | 0.84..1.12 mA | **PASS** |
| 5 LEDs | Green D3 with R6 330 (as built): typ >= 1 mA, PC13 sink <= 3 mA at min VF | typ 1.32 mA, 0.95..1.79 mA over VF bins | **PASS** |
| 6 I2C | 400 kHz, 4.7 k, 20 pF: tr <= 300 ns | tr 80 ns, tf 1 ns | **PASS** |
| 6 I2C | 400 kHz, 4.7 k, 40 pF: tr <= 300 ns | tr 160 ns, tf 2 ns | **PASS** |
| 6 I2C | 400 kHz, 4.7 k, 100 pF: tr <= 300 ns | tr 398 ns, tf 4 ns | **FAIL** |
| 6 I2C | 100 kHz, 4.7 k, 20 pF: tr <= 1000 ns | tr 80 ns, tf 1 ns | **PASS** |
| 6 I2C | 100 kHz, 4.7 k, 40 pF: tr <= 1000 ns | tr 160 ns, tf 2 ns | **PASS** |
| 6 I2C | 100 kHz, 4.7 k, 100 pF: tr <= 1000 ns | tr 398 ns, tf 5 ns | **PASS** |
| 7 Crystal | AN2867 gain margin >= 5 | 73 (gm_crit 0.34 mA/V) | **PASS** |
| 7 Crystal | Load capacitance / pulling | CL 10.5..12.5 pF, -5..+19 ppm | **PASS** |
| 7 Crystal | Drive level <= 100 uW (worst-case ESR, swing unknown) | 55 uW at 2 Vpp, 149 uW at 3.3 Vpp; limit at 2.7 Vpp | **MARGIN** |
| 8 VDDA filter | Attenuation above 10 MHz; LC resonance peak | -67 dB @10 MHz, -64 dB @100 MHz; peak +17.1 dB @ 288 kHz | **MARGIN** |
<!-- results:end -->

Plots:

| Plot | Shows |
|---|---|
| `results/hotplug_variants.png` | +5V at each variant's worst corner |
| `results/hotplug_base.png` | As-built VBUS, +5V, 3V3 and cable current |
| `results/ldo_steps.png` | LDO start-up and load steps |
| `results/brownout.png` | Brown-out ramp |
| `results/nrst.png` | NRST waveforms |
| `results/led_r6.png` | Green LED current vs R6 |
| `results/i2c.png` | I2C rise times |
| `results/vdda.png` | VDDA filter response |
| `results/hotplug_fixes.png` | Worst-case LDO IN peak for each test-9 candidate |
| `results/snubber.png` | Test 10: worst VSYS peak per snubber variant, and VSYS after the 250 mA step |

`results/summary.md` has the full numbers, including every hot-plug corner.

## Hot-plug fix candidates (test 9, run 2026-10-02)

Topology A: VBUS → U3/C13 → D2 → VSYS (C12 4.7 µF 0402, LDO IN) → F1 PTC → Q1 → J1.1 (open). VSYS and LDO IN are the same net.

- The inrush column adds the charge the fixed-value 3V3 capacitors undercount (+10.5 µC with C5 = 10 µF, +5.9 µC with 4.7 µF).
- The drop column is D2's typical VF plus I × R.
- Regulation at 500 mA needs LDO IN ≥ 3.3 V + 238 mV (TLV755 maximum dropout).

| Option | LDO IN peak (worst corner) | Inrush | Drop 250 / 500 mA | LDO IN at 500 mA, USB 4.40 V | Verdict |
|---|---:|---:|---:|---|---|
| A: C12 4.7 µF 0402, F1 on header side (F1 R makes no difference with the header open) | 12.71 V | 53 µC | 0.34 / 0.37 V | 4.03 V, regulates | FAIL |
| B: F1 between VBUS and D2, R = 0.1 / 0.3 / 0.6 Ω | 11.38 / 9.27 / 6.65 V | 52 / 51 / 50 µC | 0.36–0.49 / 0.42–0.67 V | 3.98–3.73 V, regulates | FAIL |
| C: A + 0.5 Ω in series | 7.35 V | 50 µC | 0.46 / 0.62 V | 3.78 V, regulates | FAIL |
| C: A + 1.0 Ω in series | 5.38 V | 48 µC | 0.59 / 0.87 V | 3.53 V, **dropout** (8 mV short) | FAIL |
| D: A with C12 2.2 µF 0402 | 11.76 V | 45 µC | 0.34 / 0.37 V | 4.03 V, regulates | FAIL |
| **E: C12 4.7 µF 0603 + 0.75 Ω (1206) in series + C5 4.7 µF 0603** | **5.45 V** | **37 µC** | 0.52 / 0.75 V | 3.65 V, regulates | **PASS** |
| E': as E, but C12 4.7 µF 0402 | 5.95 V | 35 µC | 0.52 / 0.75 V | 3.65 V, regulates | FAIL |
| E'': C12 10 µF 0603 + 0.5 Ω in series + C5 4.7 µF | 5.49 V | 54 µC | 0.46 / 0.62 V | 3.78 V, regulates | FAIL |

Shrinking C12 without adding resistance makes the ring worse, not better. A smaller C raises the cable/C12 impedance, so a larger series resistance is needed to damp it. The PTC's 0.1–0.6 Ω spread is not a dependable damper.

**Not the fitted board.** This study recommended option E. v1.3 is built with R12 = 1 Ω 0805 and C12 = 4.7 µF 16 V **0402** (Samsung CL05A475MO5NUNC, C318563), not a 0603 and not an extra 0.75 Ω. The study's suggestion, left here as history, was:
- a 4.7 µF **0603** for C12 (it holds about 2 µF at 5 V, where a 0402 holds about 1.3 µF);
- a 0.75 Ω 1206 resistor between VBUS (after U3/C13) and D2 (188 mW at 500 mA);
- C5 reduced to 4.7 µF 0603. Effective COUT would have been about 3.7 µF, still well above TI's 0.47 µF minimum.

Minimum package rating at 500 mA for each series resistor:

| Resistor | Power at 500 mA | Minimum package |
|---|---:|---|
| 0.5 Ω | 125 mW | 0805 (no margin; 1206 preferred) |
| 0.75 Ω | 188 mW | 1206 |
| 1.0 Ω | 250 mW | 1206 at its rating (1210/2010 preferred) |

The pass depends on the 0603 4.7 µF derating, which is an assumed curve (43 % at 5 V). Check the chosen part's DC-bias curve: it needs about 2 µF or more at 5.3 V.

500 mA is an electrical check only. At 500 mA the LDO dissipates about 0.18 W at USB 4.40 V, 0.47 W at 5.0 V and 0.72 W at 5.5 V, so most of that range is beyond the 250 mA thermal budget in the main README.

## C12 as an RC snubber (test 10, run 2026-10-02)

Topology A: VBUS → U3/C13 → D2 → VSYS (= LDO IN), with J1.1 open and no series R in the main path. C12 4.7 µF 0402 sits behind Rs; Cd is an optional extra cap directly on VSYS. The peak is the worst of the 8 corners from test 1. Inrush includes the charge the fixed-value 3V3 capacitors undercount. Rs energy is per plug-in; steady-state Rs power is about zero because no DC flows.

| Rs | Cd on VSYS | VSYS peak | Inrush | Rs peak power / energy | Verdict |
|---:|---|---:|---:|---|---|
| 0.5 Ω | none / 100 nF / 1 µF | 7.59 / 7.65 / 8.15 V | 50 / 51 / 54 µC | 17–22 W / 36–39 µJ | FAIL |
| 1.0 Ω | none | 5.74 V | 48 µC | 15 W / 41 µJ | PASS (no local CIN) |
| 1.0 Ω | 100 nF | 5.75 V | 49 µC | 17 W / 42 µJ | PASS |
| 1.0 Ω | 1 µF | 6.21 V | 53 µC | 27 W / 47 µJ | FAIL |
| 2.2 Ω | none | 5.67 V | 48 µC | 14 W / 45 µJ | PASS (no local CIN) |
| 2.2 Ω | 100 nF / 1 µF | 6.39 / 8.36 V | 49 / 53 µC | 17–28 W / 46–52 µJ | FAIL |
| **1.0 Ω** | **100 nF, plus C5 → 4.7 µF** | **5.75 V** | **35 µC** | 17 W / 42 µJ (≈2.5 µs equivalent pulse) | **PASS** |

**Load steps (0/50/250 mA through a 1 µH cable).** 3V3 stays at 3.287–3.330 V in every variant, the same as with C12 directly on VSYS: the vendor model's line rejection hides input-side differences. VSYS rings 103–122 mV peak-to-peak with the snubber, against 143 mV with C12 4.7 µF directly on VSYS. The snubber damps the cable/CIN resonance (`results/snubber.png`). Phase margin still can't be simulated, because the vendor model has no loop.

**CIN rule.** TI asks for ≥ 1 µF nominal (≥ 0.47 µF effective) at IN. The snubbed C12 holds 1.31 µF at 5 V, but it only acts as a capacitor below about 1/(2π·Rs·C) = 120 kHz at 1 Ω; above that the LDO sees Rs. So it meets the rule at DC and low frequency, not at high frequency. Directly at the pin there is only Cd: 100 nF gives about 0.06 µF effective, and 1 µF gives about 0.39 µF. **None of the passing snubber variants meets TI's rule with a capacitor directly at the pin.** A 1 µF there would, but it undoes the damping (6.21 V peak).

**Best snubber: Rs = 1.0 Ω, C12 4.7 µF 0402, 100 nF 0402 directly at LDO IN, and C5 reduced to 4.7 µF.** That gives 5.75 V and 35 µC. Keeping C5 at 10 µF works too, at 49 µC.
- The peak margin is thin, only 50 mV under 5.8 V. Rs = 2.2 Ω with the 100 nF fails.
- Rs carries no DC, so the 0402's 62.5 mW continuous rating doesn't apply. What matters is about 42 µJ in a pulse of a few µs (17 W peak) on every plug-in. Use a pulse-rated (anti-surge) 0603 or 0805 thick-film resistor, or check the 0402's single-pulse curve.

**Compared with option E** (test 9, 0.75 Ω in series in the main path):

| | Snubber | Option E |
|---|---|---|
| Peak margin | 50 mV | 0.35 V (5.45 V peak) |
| DC drop | none (LDO IN 4.03 V at 500 mA, USB 4.40 V) | 0.37 V more |
| C12 | behind Rs | directly at the LDO pin |

**Option E was this study's recommendation, and it is not what was built.** The fitted path is R12 = 1 Ω with C12 4.7 µF 16 V 0402 (test 11), not the 0603 in option E.

## Hot-plug, current spec.py power path (test 11, run 2026-10-02)

Path: VBUS (C13, U3, R2 + R11 bleed) → R12 → D2 → VSYS = LDO IN (C12 4.7 µF 0402, F1 → Q1 → J1.1 open). The 3V3 bank is C4 4.7 µF 0402, C8 1 µF and five 100 nF, with no C5. Effective COUT is about 3.2 µF, still above TI's 0.47 µF minimum.

- Peaks are the worst of the 8 corners from test 1.
- Inrush includes the 6.5 µC the fixed-value 3V3 capacitors undercount.
- The drop is I·R12 plus D2's typical VF.
- "Regulates" means LDO IN ≥ 3.3 V + 0.476 Ω × I (TLV755 maximum dropout).

| R12 | LDO IN peak | VBUS peak | Inrush | Drop 250 / 500 mA | LDO IN from 4.40 V, 250 / 500 mA | LDO IN from 4.75 V, 250 / 500 mA | R12 power at 300 / 500 mA |
|---:|---:|---:|---:|---:|---|---|---|
| **1.0 Ω (as built)** | **5.38 V** | 6.17 V | **33 µC** | 0.59 / 0.87 V | 3.81 / 3.53 V (8 mV into dropout) | 4.16 / 3.88 V | 90 / 250 mW |
| 1.5 Ω | 5.26 V | 5.74 V | 33 µC | 0.71 / 1.12 V | 3.69 / 3.28 V, dropout | 4.04 / 3.63 V | 135 / 375 mW |
| 2.2 Ω | 5.25 V | 6.21 V | 33 µC | 0.89 / 1.47 V | 3.51 / 2.93 V, dropout | 3.86 / 3.28 V, dropout | 198 / 550 mW |

**Keep R12 = 1.0 Ω.** It passes hot-plug with 0.42 V margin under 5.8 V, and inrush is 33 µC against the 50 µC limit. Going to 1.5 Ω or 2.2 Ω buys only 0.12–0.13 V of peak, but costs 0.25–0.6 V of headroom at 500 mA.

At 500 mA from 4.40 V, the 1 Ω case is 8 mV into worst-case dropout, so 3V3 sits at about 3.29 V instead of 3.30 V. That is harmless, and 500 mA is beyond the 250 mA thermal budget anyway. At ≤ 250 mA every option regulates from 4.40 V.

R12 dissipates 250 mW at 500 mA, half the 500 mW stated in spec.py's note. Check that rating in the Yageo SR0805 datasheet: a standard 0805 is 125 mW. The hot-plug pulse it absorbs is a few µs at about 4 A.

## Design recommendations

1. **Hot-plug: done in spec.py.** R12 = 1 Ω was added (test 11: 5.38 V peak, 33 µC). The rest of this item is the original analysis of the v1.3 original power path. A ceramic-only input rings. 10 µF ceramic (about 3.5 µF at 5 V) with 0.5–1 µH of cable gives Z0 ≈ 0.4–0.5 Ω, and with only 0.1–0.3 Ω of damping, D2 then latches the ring peak onto C12. The +5V rail reaches 6.1–11.4 V, above the then-fitted TLV755's 6 V absolute maximum and above that original C12's 10 V rating. The fitted regulator is the 18 V TLV76733, and C12 is the 16 V 4.7 µF 0402.
   - A TVS does not fix it: VBR ≥ 6.4 V plus the clamp slope is still above 6 V on +5V.
   - Bulk capacitance only works at ≥ 47 µF with ESR, which breaks the USB inrush limit.
   - **Recommended:** add a 1 Ω resistor (0805, ≥ 0.125 W) in series between VBUS (after U3/C13) and D2. Peak becomes 5.26 V and peak current falls from 14 A to 4 A. The cost is about 0.25 V more drop at 250 mA. Regulation still holds down to VBUS ≈ 4.0 V, inside USB's 4.40 V minimum.
   - 0.5 Ω also passes (5.51 V), with less margin.
   - A PTC with its own hold resistance would also add a fuse. Use one only if its minimum resistance is ≥ 0.5 Ω.
2. **Inrush: done in spec.py.** As built it is 33 µC. Original analysis (63–70 µC vs 50 µC): The charge comes from C12 plus the 3V3 bank, which soft-start fills within 0.4 ms. Reduce **C12 and C5 to 4.7 µF**: that gives 30 µC simulated (about 36 µC with full bias dependence), and with the series resistor the peak is still 5.26 V. COUT stays above TI's minimum (about 4 µF effective). This matters only for strict USB-IF compliance; hosts tolerate it in practice.
3. **Green LED: done in spec.py**, with R6 = 330 Ω (1.32 mA typical, 0.95–1.79 mA). The original suggestion was 220 Ω: 1.67 mA typical, 2.36 mA at the minimum-VF bin (PC13 sink ≤ 3 mA). No single value holds 1.5–2 mA across the whole 2.7–3.7 V VF bin range from 3.3 V. The maximum-VF bin gets 1.17 mA.
4. **I2C (FAIL at 100 pF).** 4.7 kΩ is fine up to about 75 pF at 400 kHz. If off-board modules push the bus near 100 pF, use 400 kHz only with ≤ 3.3 kΩ total pull-up (limit 3.54 kΩ at 100 pF), or run at 100 kHz. Document this beside the "keep combined pull-up above 1.5 kΩ" note in the README. The driver model's fall time (≈5 ns) is faster than UM10204's 12 ns Fm minimum; on the real part, select the slower GPIO speed setting.
5. **Brown-out (MARGIN).** The F103 has no BOR, only a PDR at 1.8–1.96 V. Between VDD = 2.0 V and PDR the MCU runs out of spec without being reset. Enable the **PVD** (for example 2.9 V) in firmware if flash writes or a sagging 5V-pin supply are possible.
6. **Crystal drive level (MARGIN).** Gain margin is ample. Drive level exceeds 100 µW only if OSC_IN swings more than 2.7 Vpp with a worst-case-ESR crystal. Measure OSC_IN at bring-up with a ≤ 1 pF probe. If it is above about 2.7 Vpp, add Rext (start at about 1.3 kΩ, then re-check the gain margin).
7. **VDDA (MARGIN).** FB1 resonates with C6/C7 at about 290 kHz (+17 dB). There is no known source on 3V3 at that frequency, so this is informational. A 1 Ω resistor in series with C7 (or a 1 µF part with higher ESR) damps the peak to +2.8 dB.

## Limitations

These benches cover the circuit, not the layout: there is no trace inductance, no thermal model and no temperature corners. MLCC derating, the USBLC6 breakdown voltage and the LED low-current bins are estimates. A first article should confirm the hot-plug result with a scope on +5V while plugging in a short cable from a stiff 5 V supply.

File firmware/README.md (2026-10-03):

# NickLink v1.3 board-test firmware

Bare-metal bring-up firmware for the STM32F103C8 on NickLink, plus a Renode model of the board that runs it headlessly. There are no vendor libraries: `src/regs.h` defines the registers it uses, and newlib-nano supplies `printf`. It builds to about 19 KB of flash.

`build/pins.h` is generated from `../tools/spec.py` by `gen_pins.py` on every build, so the `pins` table and the GPIO walk always match the hardware. `gen_pins.py` also checks every GPIO net in spec.py against the STM32F103 LQFP-48 datasheet pinout, so the build fails if spec.py has a wrong pin.

## Build

```sh
make            # uses a host arm-none-eabi-gcc if there is one, otherwise docker
make DOCKER=1   # always build in docker (image nicklink-fw-build from ./Dockerfile: Ubuntu 24.04 gcc-arm-none-eabi 13.2)
```

The outputs are `build/nicklink-test.elf`, `.bin` and `.map`. The first docker build needs network access for apt. After that, builds work offline.

## Flash

`prebuilt/nicklink-test.hex` / `.bin` is this firmware prebuilt (refresh it with `make` and copy from `build/` after changing the source). [`docs/BRINGUP.md`](../docs/BRINGUP.md) has the STLINK-V3MINIE wiring and a step-by-step board test using it.

**SWD (ST-Link):** connect J3.1 3V3 (target sense), J3.2 GND, J3.7 SWDIO, J3.8 SWCLK and J3.10 NRST.

```sh
make flash                                   # st-flash --reset write build/nicklink-test.bin 0x08000000
openocd -f interface/stlink.cfg -f target/stm32f1x.cfg -c "program build/nicklink-test.elf verify reset exit"
```

Many "STM32F103C8" parts report a 128 KB flash or are clones with a different IDCODE. If OpenOCD refuses the chip, add `-c "set CPUTAPID 0"` before the target `-f`.

**USART1 ROM bootloader:** use a 3.3 V USB-serial adapter. Connect its RX to J3.3 (PA9, TX) and its TX to J3.4 (PA10, RX). Hold **BOOT**, tap **RESET**, then release BOOT.

```sh
make flash-uart PORT=/dev/ttyUSB0            # stm32flash -w build/nicklink-test.bin -v -g 0x08000000 /dev/ttyUSB0
```

The F103 has no USB DFU bootloader. USB is not used by this firmware (see below).

## Console

USART1 at 115200 8N1 on J3.3/J3.4, the same adapter as the bootloader. At boot the firmware prints a banner: clock source, reset cause, boot mode and IMU status. Then it gives a `>` prompt.

| Command | What it does |
|---|---|
| `info` | Prints the banner again: SYSCLK, clock source (HSE+PLL 72 MHz, or HSI fallback 64 MHz if the crystal doesn't start), reset cause from RCC_CSR, boot mode, PB2/BOOT1 level, flash-size register and UID. |
| `pins` | Lists all 48 MCU pins: function, net, header position, alias and on-board loads. Generated from spec.py. |
| `walk [ms] [all]` | Walks the header GPIOs one at a time. Each pin is driven high, then low, for `ms` per level (default 500), while the other header pins are pulled down. Probe each one with a meter or LED as it goes. It also checks that the pin reads back and that no other header pin follows it (solder bridge), and prints `FAIL ...` lines and a fault count. PA9/PA10 (console) are always skipped. PA13/PA14 (SWD) are skipped unless you add `all`, which turns SWD off until the next reset. Any key aborts. |
| `mon` | Loopback/monitor. All header GPIOs become pulled-down inputs, and every level change is printed. Jumper a pin to 3V3, or to another pin you drive, to test it. PB6/PB7 read 1 because of their 4.7k pull-ups. Any key exits. |
| `imu` | Reads accel (mg), gyro (dps) and temperature once. |
| `i2cscan` | Scans I2C1. Expect `0x6A`. |
| `mco [hse\|pll\|hsi\|off]` | Clock output on PA8 (J3.5). Default HSE (expect 8.000 MHz). `pll` = PLL/2 = 36 MHz. Use it to check the crystal frequency without loading the crystal with a probe (README bring-up step 3). |
| `clock` | Same as `info`. |
| `adc` | ADC1 single conversions (ADC clock 12 MHz, 239.5-cycle sample, calibrated first): PA0-PA7 (ch0-7), PB0/PB1 (ch8/9) in raw counts and mV, plus VREFINT (ch17) to estimate VDDA (VREFINT 1.20 V typ, so +-3 % at best). The pins are analog only while the command runs and are restored afterwards. |
| `standby` | Enters Standby (PWR_CR PDDS, SLEEPDEEP, WFI) with PA0/WKUP armed. It first reads the IMU's ALL_INT_SRC so INT1 is low, and PA0 is a floating input (A0 already has 10k to INT1). A rising edge on PA0 (a tap/wake event from the IMU, or a jumper to 3V3) wakes the MCU, which resets; the banner then says `woke from Standby` (PWR_CSR.SBF, cleared with CSBF). RESET also wakes it. |
| `reset` | Software reset (SYSRESETREQ). |

The firmware also does these at boot:

- **Vector table:** `Reset_Handler` writes SCB->VTOR = 0x08000000 first. After a USART bootloader GO (`stm32flash -g`) VTOR still points at the ROM, and without this the first SysTick interrupt hangs.
- **Clocks:** `clock_init` does not assume a fresh reset: it switches SYSCLK to HSI, turns the PLL (and CSS) off, then sets HSE 8 MHz → PLL ×9 = 72 MHz, APB1 36 MHz, ADC /6 = 12 MHz (limit 14), USB prescaler /1.5 = 48 MHz, 2 flash wait states. The banner prints RCC_CFGR (expect `0x001D840A` on the HSE path).
- **Clock Security System:** CSSON is set once HSE is ready. If the crystal fails later, hardware drops SYSCLK to HSI and raises NMI; `NMI_Handler` clears CSSF, retunes SysTick and the UART baud for 8 MHz, and records the failure (`info`/`clock` then says `HSE FAILED at runtime`). The MCU keeps running on HSI.
- **PVD:** enabled at 2.9 V (PWR_CR PLS=111). It is polled, not interrupt driven: the banner shows `VDD ok` or `VDD BELOW threshold` (PWR_CSR.PVDO) as of boot, and `info` re-reads it. If HSERDY doesn't come up within about 100 ms, it falls back to HSI/2 ×16 = 64 MHz and says so. USB cannot run on HSI. Every wait has a timeout, so a dead crystal never hangs the board.
- **Reset cause:** the RCC_CSR flags are read and then cleared with RMVF. Power-on shows as `power-on`. Pressing **RESET** shows as `NRST pin (RESET button)`, which is how you check that the button works.
- **BOOT0** is not a GPIO on the F103, and it is only sampled at reset. The firmware infers it instead. If the word at 0x0 equals the flash vector table, flash was aliased, so BOOT0 was low. If you see `0x0 is NOT flash`, the chip started from the bootloader (for example via `stm32flash -g`). PB2/BOOT1 is a normal GPIO, so its 10k pull-down is read directly and should read 0.
- **User LED:** PC13, push-pull, low = on. It blinks at 1 Hz from SysTick. If the board hard-faults, the LED stays solid on.
- **JTAG:** AFIO SWJ_CFG is set to "SWD only". This frees PA15, PB3 and PB4, which are JTDI, JTDO and NJTRST at reset and can't be used as GPIO until this is done.
- **USB:** no stack. PA12 (D+) is held low, so the host sees nothing attached rather than a device that never answers. A USB build should release PA12 at least 10 ms after boot; that forces re-enumeration against the fixed D+ pull-up (R2 2k2 from VBUS with R11 4k7 to GND).
- **IMU (LSM6DSV @ 0x6A):** the firmware runs I2C bus recovery (9 SCL clocks if SDA is stuck low, then a STOP), sets I2C1 to 100 kHz, and checks that WHO_AM_I = 0x70. It then does SW_RESET and configures the IMU:
  - INT1 push-pull, active high (IF_CFG PP_OD = 0, H_LACTIVE = 0).
  - Accel 480 Hz ±2 g; gyro 120 Hz ±2000 dps.
  - Tap on X/Y/Z, latched; single and double tap enabled.
  - Wake-up threshold 0.25 g.
  - FUNCTIONS_ENABLE.INTERRUPTS_ENABLE set; MD1_CFG = single tap | double tap | wake-up → INT1.
  - MD1_CFG is read back to confirm the write.
  - PA0 is a pulled-down input on EXTI0 (rising edge). Each event prints `tap`, `double-tap` or `wake`. The firmware reads WAKE_UP_SRC/TAP_SRC, then ALL_INT_SRC to release the latch.
  - The thresholds (`TAP_THS`, `WAKE_THS`, `TAP_DUR`) are `#define`s at the top of `main.c` and need tuning on real hardware.

Not included: USB CDC, which needs a USB device stack of about 1–2 KB plus descriptors, and which Renode can't model on the F1 anyway. SFLP game-rotation-vector FIFO output is also left out; it needs embedded-function-bank access and half-float decoding. Add either when a project needs it.

## Emulation (Renode)

```sh
./test.sh       # make, then renode-test in the antmicro/renode docker image; prints PASS/FAIL per test
```

The first run downloads the STM32F103 SVD that Renode's platform file references. It is cached in `build/home`. The test results go to `build/robot/` (`log.html`, `console.txt`, and snapshots and logs of failed tests). For interactive use, run `cd renode && renode nicklink.resc`, then `start`.

`renode/nicklink.repl` is Renode's `platforms/cpus/stm32f103.repl` plus:

- `rcc` (`NickLinkRCC.cs`): the stock platform has no RCC, only an SVD tag. In this minimal model, the RDY bits follow their ON bits and SWS follows SW. RCC_CSR reset flags start as POR+PIN at power-on, become PIN after each machine reset, and are cleared by RMVF. Setting `HseBroken true` makes the crystal fail.
- `imu` (`LSM6DSV16X.cs`): Renode has no LSM6DSV-family model, so this is a minimal one. It was written from the LSM6DSV16X datasheet; every register it models has the same address and bits on the board's LSM6DSV:
  - WHO_AM_I = 0x70, a register file, SW_RESET (IF_CFG survives it), IF_INC.
  - The output registers come from settable `AccX/Y/Z`, `GyroX/Y/Z` and `Temp`.
  - `Tap`, `DoubleTap` and `WakeUp` drive INT1 → PA0 **only if the firmware routed the event**, i.e. INTERRUPTS_ENABLE and the matching MD1_CFG bit are set. They honour H_LACTIVE and LIR, and the ALL_INT_SRC read releases the latch.
- `led`: a Renode LED on PC13, inverted (active low).

Tests in `renode/test.robot`:

| Test | Checks |
|---|---|
| Banner Reports 72 MHz From HSE And Power-On Reset | SYSCLK 72 MHz, RCC_CFGR readback 0x001D840A (PLL x9 from HSE, APB1 /2, ADC /6), HSE→PLL message, `power-on` reset cause, BOOT0-low detection, PB2 = 0 |
| HSE Failure Falls Back To HSI | With `HseBroken`, the firmware reports the HSE failure and runs at 64 MHz without hanging |
| User LED Blinks At 1 Hz | LED model state toggles at 0.5 s on / 0.5 s off |
| IMU WHO_AM_I And Sample | WHO_AM_I = 0x70, config readback OK, `imu` scales the values the model was set to (−1 g, 1 g, 70 dps, 25.0 C), `i2cscan` finds only 0x6A |
| Tap Double-Tap And Wake On INT1 | Each event arrives through INT1 → PA0 → EXTI0 and prints `tap` / `double-tap` / `wake`; PA0 is low again afterwards (latch released) |
| Pins Command Lists Generated Map | `pins` output matches spec.py rows |
| GPIO Walk Drives Each Header Pin Alone | For every walked header pin (list parsed from the generated `pins.h`): the pin is high in the GPIO model, it is the **only** pin set on ports A/B/C, then it goes low; `0 faults` |
| Monitor Mode Sees Header Inputs | Driving PB12 and PC15 inputs from the test prints their level changes |
| NRST Reset Reports Pin Reset | After `machine Reset`, the reset cause is `NRST pin (RESET button)` |
| Software Reset Command Reboots | `reset` reboots the firmware to the prompt |

**What the emulation does not verify:**

- **Real clock behaviour:** the RCC is my own model, which makes PLL/HSE ready instantly. FLASH_ACR is not modelled, and SysTick runs at a fixed 72 MHz in Renode even in HSI fallback. Check the clocks on hardware with `mco`.
- **I2C electrical/timing and the exact F1 receive sequence:** Renode 1.16's `STM32F4_I2C` (reused for the F1) ignores ACK/NACK and fetches one byte per address phase, so the IMU model returns 16-byte bursts. The firmware's N-byte read follows the usual "NACK+STOP after byte N−2" pattern, but the RM0008 errata-safe sequences can only be proven on hardware. Pull-ups are not modelled: SDA reads 0 in recovery, so the 9-clock recovery always runs (harmless).
- **AFIO:** SWJ_CFG and EXTICR are not modelled, because Renode wires every port's pin 0 to EXTI0 directly. So JTAG release of PA15/PB3/PB4 and the "PA0 not PB0" EXTI selection are untested.
- **Pull resistors:** pull-up/pull-down and the ODR-before-mode-switch latching on inputs are not modelled. Renode ignores ODR writes to input pins. The short/bridge detection in `walk` therefore only ran fault-free; in emulation a real short can't be injected.
- **Reset types:** software reset reports `NRST pin` in Renode. Real F1 silicon reports `software` (SFTRSTF, with PINRSTF also set).
- **ADC, PWR, Standby, CSS/PVD:** Renode's ADC does not convert (the `adc` command prints `timeout` per channel and returns, so it is untested), PWR is unmapped (PVD reads ok, SBF reads 0, `standby` is not testable), and the RCC model never raises CSSF/NMI. The new clock sequence needed no RCC model change: ready bits already follow HSION/HSEON/PLLON, so HSI switch and PLL off work as is, and a written CSSON bit simply reads back.
- **Not modelled at all:** USB, MCO, real tap detection from accelerometer data, the IMU FIFO/SFLP.
- **Peripherals only used as GPIO:** USART2/3, SPI1/2 and I2C2 are not exercised as peripherals; the `walk` only drives their pins as plain GPIO.

## Hardware notes found while writing this

1. **Open-drain INT1 doesn't make A0 high-Z by itself.** The main README suggests setting INT1 to open-drain (`PP_OD`) for a high-impedance A0. With the default active-high polarity, the idle (inactive) level is logic 0, which an open-drain output still drives low, so A0 keeps its 10k pull-down. To release A0 when idle you also need `H_LACTIVE = 1` (active low). The interrupt then becomes a falling edge that needs the PA0 internal pull-up, and it can no longer wake the MCU from Standby, because the WKUP pin is rising-edge only. The datasheet (DS13510 Table 30) doesn't spell out the OD + active-high combination, so this needs checking on hardware.
2. **PA0 is never a free input once the IMU is configured.** Push-pull INT1 drives A0 through 10k both ways (low idle, high on events). An external driver on A0 fights it with about 0.33 mA, which is harmless but corrupts ADC readings and lets taps glitch an external signal. The firmware disables EXTI0 during `walk`/`mon` for this reason.
3. **PA15, PB3 and PB4 are JTAG pins at reset:** JTDI (pull-up), JTDO/SWO and NJTRST (pull-up). Firmware must set AFIO SWJ_CFG = 010 before using them, and until then they are not GPIO. The header table lists them as plain GPIO, so a note there would help.
4. **PB2/BOOT1 has a 10k pull-down,** so as an input it reads 0 unless driven, and driving it high costs 0.33 mA. If something external pulls PB2 high while BOOT is held, the chip boots from SRAM instead of the bootloader.
5. **USB with no firmware stack:** the fixed D+ pull-up (R2 2k2 from VBUS, R11 4k7 to GND) means a host sees a device attach whenever the board is powered, including in the bootloader or under a non-USB firmware. The host then logs enumeration errors. This firmware avoids that by holding PA12 low. A USB application must release PA12 (drive it low for ≥10 ms first) to force re-enumeration.
6. **PB6/PB7 are shared between header and IMU:** driving them as GPIO (`walk`) can generate START/STOP conditions on the IMU's bus. Firmware that reuses them must re-run bus recovery before using I2C again; this firmware does.
7. **The green user LED is modest** (R6 is 330 ohm, about 1.3 mA, brighter than the original 1.5k, but still modest). It is visible next to the red power LED.
8. **MCO on PA8 (J3.5)** is the right way to check the 8 MHz crystal (bring-up step 3), but it is limited to 50 MHz. Use HSE or PLL/2, never SYSCLK at 72 MHz.

There are no pin conflicts: `gen_pins.py` confirms spec.py matches the LQFP-48 pinout, and all 33 header GPIOs are distinct.

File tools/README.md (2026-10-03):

# NickLink build tools

NickLink is generated, not hand-edited. Change the inputs below, then rebuild. Everything runs in the `kicad/kicad:10.0` Docker image, so no local KiCad install is needed. Freerouting runs in `eclipse-temurin:25-jre`.

## Inputs

| File | What it holds |
|---|---|
| `spec.py` | Parts, values, footprints, pin→net map, header pinout, LCSC numbers. Single source of truth. |
| `placement.py` | Board size, label-strip geometry, every part's position/rotation, front part labels. |
| `board_template.kicad_pcb` | Board setup only (stackup, solder-mask web, plot settings) for `build_pcb.py`. |
| `gen_sch.py` | Schematic layout (block positions in its `LAYOUT` table). |

## Pipeline

```sh
tools/build_all.sh   # sch -> place -> autoroute -> stitch -> DRC -> nicklink.kicad_pcb
tools/fab.sh         # gerbers, drills, BOM/CPL, PDFs, renders, checks/
```

| Script | Step |
|---|---|
| `sch.sh` | Runs `gen_sch.py`, ERC (must be 0/0), exports the netlist and checks it against `spec.py` (`check_netlist.py`); refreshes `docs/schematic.pdf` and `docs/images/schematic.png`. |
| `place.sh` | Runs `build_pcb.py`: footprints, nets and symbol links from the netlist, outline, GND pours, silkscreen (front pin labels, back cheat sheet). Also writes `_work/placed.png`, a placement preview with courtyard-overlap check and ratsnest length (`preview.py`). |
| `autoroute.sh` | Exports a Specctra DSN, runs Freerouting headless, imports the SES and refills the pours. Existing tracks are kept as fixed. With `RIPUP=1`, only locked pre-routes stay fixed, so a second pass may rip up and redo the first pass's tracks. |
| `stitch.py` | Adds GND stitching vias wherever both pours have room, then drops any via that ends up on isolated copper. |
| `drc.sh` | `kicad-cli pcb drc` with schematic parity; exits nonzero on any violation. JLCPCB limits come from the board setup plus `nicklink.kicad_dru`. |
| `route_try.sh` | One placement variant end to end (place, route, stitch, DRC) for the seed search. |
| `render.sh` | 3D top/bottom renders plus 2D layer plots (`svg2png.py`). |
| `compare.py` | Any number of boards side by side at a fixed physical scale (px/mm), e.g. `docs/images/compare-v1.1-v1.2-v1.3.png`. Outline-only entries are allowed for boards without files. |
| `pinout.py` | Writes `docs/pinout.csv` from `spec.py` and prints the README pinout table. |
| `netreport.py` | Per-net length per layer and via count (check USB/HSE routing). |
| `build_pcb.py --resilk` | Redraws only the silkscreen on an already-routed board. Use it for label tweaks without re-routing. |
| `fixroute.sh` | Finishes a connection Freerouting left open: a small two-layer grid router (`fixroute.py`) joins the copper cluster holding one pad to the cluster holding another, e.g. `tools/fixroute.sh in.kicad_pcb out.kicad_pcb GND R5.1 U1.23 0.25`. Run `drc.sh` afterwards. |
| `gndnet.py` | GND connectivity per pour island (KiCad treats a whole zone as one item), so floating island pairs show up. `stitch.py` uses the same idea. |
| `swapfp.py` | Swaps a placed footprint for a same-pad variant (e.g. NoSilk) on a routed board, keeping nets and the symbol link. |
| `bringup_img.sh` | Renders the board and draws the bring-up pictures (`docs/images/bringup-*.png`: ST-Link wiring, check points) from the real pad positions (`bringup_img.py`). |
| `nosilk.py` | Copies a library footprint into `nicklink.pretty` without its silkscreen. |
| `kdock` | Runs a command in the KiCad container with the repo and 3D models mounted. |

`_work/`, `3dmodels/` and the Freerouting jar are local caches, ignored by git. `get3d.sh` and `autoroute.sh` download them on first use.

## Routing notes

- `placement.py` `PREROUTE` holds locked tracks laid before autorouting (currently the crystal nets), so the critical nets don't depend on Freerouting.
- Freerouting's result is very sensitive to placement. If a placement change leaves nets unrouted, run a few `tools/route_try.sh s<n> "" <n>` in parallel (at most about 4, since each Freerouting JVM needs a few GB of RAM). Each one nudges small parts by up to ±0.1 mm (`NICKLINK_SEED`), then routes, stitches and runs DRC. Bake the offsets of a clean seed into `PLACE`. The current layout uses seed 3 (second review wave), which Freerouting routes fully on its own. If a seed leaves one or two items, `fixroute.sh` is usually faster than more seeds. Hand-routed nets live in `PREROUTE`, `PREROUTE_B` and `PREVIAS`: crystal, IMU fan-out and GND returns, the power path, the USB-C orientation ties, and GND vias for boxed-in pads.
- `build_all.sh` retries the route, stitch and DRC step (`TRIES`, default 3) because Freerouting's optimizer is time-limited.

## Typical edits

- **Swap a part or value:** edit `spec.py`, run `build_all.sh`.
- **Change only silkscreen text or labels:** edit `build_pcb.py` / `placement.py`, then run `tools/kdock python3 tools/build_pcb.py --resilk nicklink.kicad_pcb` and `tools/drc.sh nicklink.kicad_pcb`.
- **Move a part:** edit `placement.py`, run `place.sh` and look at `_work/placed.png` until there are no overlaps, then run `build_all.sh`.
- **Change the header pinout:** edit the `J1`/`J3` maps in `spec.py`. Labels, the schematic, `pinout.csv` and the routing all follow. Run `pinout.py` and update the README table.

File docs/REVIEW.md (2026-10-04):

# NickLink v1.3 design review — 2026-10-01

v1.3 adds an on-board 6-axis IMU for motion tracking, robotics and tap-activated projects. Everything else matches v1.2 (section below), apart from the items listed here. **Pinout is unchanged from v1.2.**

| | v1.2 | v1.3 |
|---|---:|---:|
| Outline | 33.19 × 25.5 mm (846 mm²) | **33.99 × 25.5 mm (867 mm²)** |
| vs v1.1 (1122 mm²) | −25% | **−23%** |
| Parts | 33 | 42 |

**IMU circuit** (designed as ST LSM6DSV16X, LCSC C5267406; built as the pin- and register-compatible **LSM6DSV, C41785564**, see [JLC order round](#jlc-order-round-2026-10-02); LGA-14 2.5 × 3 mm):

| Pin | Connection | Why |
|---|---|---|
| SCL / SDA | PB6 / PB7 (I2C1) | 4.7 kΩ pull-ups R7/R9 back on the bus |
| SDO/SA0 | GND | I2C address 0x6A |
| CS | 3V3 | I2C mode |
| INT1 | PA0 through R10 10 kΩ | WKUP pin: tap or motion can wake the MCU from Standby; R10 limits INT1's power-up low state to a weak pull-down |
| VDD, VDDIO | 3V3, each with its own 100 nF | datasheet recommendation |
| SDx, SCx | GND | datasheet: "connect to Vdd_IO or GND" (must not float) |
| INT2 | not connected | drives low by default; every interrupt source can route to INT1 |
| OCS_Aux, SDO_Aux | 3V3 | datasheet allows tying them to VDDIO; gives CS a short path to VDD |

The connections were checked against datasheet DS13510 (see `tools/imu_research.md`). The schematic uses a project symbol (`nicklink.kicad_sym`) with the LSM6DSM pinout, which is identical, and pin types set for I2C use.

**Placement and routing**
- The IMU sits on the top side, in the right channel between the MCU and J1, below the RESET button. Its caps and the ferrite go in a row underneath. R10 (INT1) sits in the MCU's bottom-right courtyard notch, and the I2C pull-ups sit beside PB6/PB7. An earlier draft added a 3.3 mm bottom row for the IMU; this layout fits it into existing gaps instead, so the board stays at v1.2's height.
- The position is away from the LDO's heat (gyro bias drift) and from USB cable strain.
- Orientation: pin 1 (SA0) is top-left. The VDDIO/GND row faces its caps below, and all SMD bodies stay ≥ 1 mm from the board edge.
- A top-copper keep-out covers the area inside the IMU's pad ring, per ST's LGA guidance: no tracks, vias or pour under the package.
- **Deviation:** ST suggests about 10 mm from screws. Here the H4 screw keep-out is 2.4 mm from the IMU body (5.7 mm centre to centre), because the board is only 25.5 mm tall. Mount without over-tightening.
- **Crystal nets are now pre-routed** as locked top-layer tracks (HSE_IN 8.1 mm, HSE_OUT 5.1 mm, no vias), so autoroute variation can't push them onto vias.
- **ESD channels swapped:** USB D+ uses the USBLC6's I/O2 channel and D− uses I/O1. The two channels are identical, and this order means D+ and D− no longer cross at the MCU. USB D+ is 11.8 mm with no vias and D− is 10.9 mm with one via, including the A/B row ties and the pull-up branch (second-wave layout).
- **Minimum track width lowered from 0.13 mm to 0.10 mm.** This covers Freerouting's 0.112 mm neck-downs at fine-pitch pads, which are within JLC's standard 2-layer capability. The default 0.15 mm signal width is unchanged.
- Sixteen small parts (passives near USB, the I2C pull-ups, the IMU, its caps and RESET) carry ≤ 0.1 mm offsets, found by a seeded search (`NICKLINK_SEED=13`; the post-review layout uses seed 3). Freerouting's result is very sensitive to placement, and these offsets give 100% routing with short crystal and USB nets.

**JLCPCB rules** (README, "JLCPCB design rules"): v1.3 is checked against JLC's published limits via the board setup and `nicklink.kicad_dru`. Changes made to comply:
- USB4085 pads enlarged to a 0.18 mm annular ring.
- Edge clearance raised to 0.3 mm (Economic PCBA).
- Silkscreen text 1.0 mm tall and lines 0.15 mm wide. The label strips grew from 1.2 to 1.4 mm, which adds 0.8 mm of board width.
- Silk-to-pad clearance 0.15 mm and a 0.10 mm minimum solder-mask web.

## Five-reviewer audit (2026-10-01) and fixes

Five independent reviewers checked v1.3 at commit a913740, one area each. They checked against datasheets, the GCT drawing, JLC's own EasyEDA footprints and the board data. I re-verified the key claims (INT1 default state in DS13510; the EasyEDA pin-1 positions) before changing anything.

| Area | Grade | Must-fix findings |
|---|---|---|
| Power / protection | C | U3 CPL rotation would short VBUS; LDO output cap 19 mm from OUT |
| MCU core / clock | B | U1 CPL rotation 90° off; weak VDD/VDDA decoupling layout |
| USB-C / data | B | 0.36 mm holes too tight for the receptacle tails |
| IMU / headers / labels | B | INT1 holds A0 low from power-up; PB6/PB7 and NRST mislabelled 5 V tolerant |
| Fab / BOM / CPL / mechanics | C+ | CPL rotations for U1/U3/U4 wrong vs JLC's footprints; USB hole fit |

**Fixed:**
- **CPL rotations:** `tools/fab.sh` adds per-footprint JLC corrections (LQFP-48 −90°, SOT-666 +180°, LGA-14 +180°), checked against JLC's EasyEDA footprints. U1 = 0, U3 = 90, U4 = 180.
- **LDO:** output cap C8 sits next to U2 OUT (0.95 mm, top layer). C12 becomes 10 µF 0603 for input decoupling and USB hot-plug damping. *(Superseded: the reliability pass changed C12 to 4.7 µF, and the second wave fitted the 16 V 0402 Samsung CL05A475MO5NUNC, C318563. Not 10 µF 0603.)* Two 0.3 mm thermal vias go under the exposed pad (project footprint `WSON-6-…_ThermalVias03`).
- **IMU INT1:** goes to A0 through a new 10 kΩ resistor, R10. INT1's power-up "forced to ground" state is now only a weak pull-down on A0.
- **USB4085:** 0.38 mm holes in 0.74 mm pads. That is inside GCT's 0.40 ± 0.05 mm spec and keeps JLC's 0.18 mm ring. The 0.11 mm pad gap is covered by a footprint-scoped DRC rule; JLC's minimum is 0.10 mm. The GND pins use thermal reliefs for hand soldering.
- **IMU layout:**
  - No pour under the package body; the GND pads are reached by traces (TN0018).
  - The local fan-out is pre-routed: GND vias above and below the package, a 3V3 rail under it joining VDDIO, VDD and the 3V3 pads of FB1, C14 and C15. The bottom-layer GND link runs in under the MCU.
  - OCS_Aux/SDO_Aux are tied to VDDIO (the datasheet allows this) to give CS a short path to VDD.
- **VDDA:** C6 and C7 are next to the VDDA pin; C9 (NRST) is after them.
- **Stitching:** vias now respect the long axis of the USB shell slots.
- **Docs:** PB6/PB7 (IMU 3.6 V limit) and NRST are marked 3.3 V only. I2C pull-ups must go to 3.3 V only. Also added: ENIG finish, plastic hardware under the screw heads, and the D+ back-feed behaviour when powered from J1.1.
- **Layout:** the MCU and its clock/decoupling group sit 0.25 mm left of centre, so fan-out vias fit between the MCU's right pads and the IMU/RESET column.

**Known limitations, not changed:**
- C13 (the USBLC6 VBUS decoupler) can't sit at U3's VBUS pin, because D+/D− box that pin in. The internal Zener still clamps.
- The C2 (VDD pin 24) ground return is long.
- No reverse-polarity protection or fuse on J1.1.
- The green user LED (InGaN at about 0.4 mA) is dim; R6 could drop to about 680 Ω.

**Verification** (KiCad 10.0.6): ERC 0 errors / 0 warnings; DRC 0 violations, 0 unconnected, 0 schematic-parity issues (`checks/`).

**Bring-up additions:** scan I2C1 (expect 0x6A); read WHO_AM_I (0Fh) and expect 0x70; enable tap detection on INT1 and check that A0 pulses; confirm that A0 is not driven from outside while INT1 is push-pull.

**Cost:** the LSM6DSV16X is a JLC Extended part, about $3.44 each or $2.47 each at 100, plus a loading fee. The other new parts are Basic: 4.7 kΩ (C25900), 100 nF (C1525).

## Reliability pass (2026-10-02)

This pass follows up the audit's known limitations and an STM32 best-practice audit (AN2586, AN4879, AN2867, DS5319; `tools/_work/audit_stm32/`). It adds a SPICE suite (`sim/`) and an emulated test firmware (`firmware/`).

**Power path**, now VBUS → R12 → D2 → VSYS → LDO, plus VSYS → F1 → Q1 → J1.1:

| Change | Why | Evidence |
|---|---|---|
| **R12 1 Ω 0805 anti-surge** (Yageo SR0805, 0.5 W) in series with VBUS | USB hot-plug ringing reached 6.1–11.4 V at LDO IN without it (abs max 6.0 V on the TLV755 then fitted) | SPICE bench 11: 5.38 V worst case over 8 cable/clamp corners; R12 pulse 13 W / 44 µJ, about 100 W rated. *(The fitted regulator is the TLV76733, 18 V; see the second review wave.)* |
| **C12 10 µF → 4.7 µF**; the 10 µF 3V3 bulk (C5) removed | USB inrush ≤ 50 µC | 33 µC as built |
| **F1 0.5 A PPTC (16 V) + Q1 DMP2165UW** on the J1.1 branch only | 5V-pin short (J1.1 is next to GND) or reversed supply | A short trips F1 while the MCU keeps running; Q1 blocks a reversed supply. *(Superseded: VSYS collapses during the trip and the MCU resets once. See the second-wave notes and the README.)* |
| **C4 (VDD3) 100 nF → 4.7 µF** | DS5319 Fig. 14: the 4.7 µF must be on VDD3 | — |
| **D+ pull-up from VBUS**: R2 2.2 kΩ + R11 4.7 kΩ (1.5 kΩ Thevenin to 3.4 V) | AN4879 §3.1.1: the pull-up must only be present with VBUS. This removes the J1.1 back-feed into the host. | — |
| **R6 1k5 → 330 Ω** | The user LED was dim at 0.4 mA | 1.32 mA typical, 0.95–1.79 mA across bins, PC13 limit 3 mA |

R12 costs headroom: LDO IN is 3.81 V at 250 mA from a 4.40 V hub port. 500 mA from 4.40 V is 8 mV into worst-case dropout, but that is beyond the 250 mA thermal budget anyway.

**Layout and routing**

- **Locked tracks:**
  - C13 now faces J2, with VBUS locked from U3 pin 5 through C13 to J2.A4.
  - The USB-C orientation ties are locked: VBUS B4–A9 and B9–A4, plus a B.Cu cross-link above the B row; D+ B6–A6 on B.Cu; D− A7–B7 on F.Cu.
  - The D+ pull-up's VBUS feed is locked.
  - The C2/IMU 3V3 feed is locked: from the LDO output cap down to C2, then on to the IMU's VDD loop.
  - The IMU's bottom GND pads have a short return to its decoupling caps.
- **GND vias** for R3 and VSS_2 (pin 35), which the new parts had boxed in.
- **`tools/stitch.py`:** stitching vias are now checked per fill island, and a via survives only if it joins islands anchored to real GND copper. KiCad treats a zone as a single item, so its own connectivity can't see a floating island pair. `tools/gndnet.py` reports GND clusters the same way.

**STM32 checklist** (no hardware change needed, documented in the README):
- PVD in firmware, since there is no BOR. Bench 3 shows a 200 mV window where VDD is below 2.0 V but not yet reset.
- CSS/HSE fallback.
- JTAG reset state of PA15/PB3/PB4.
- Injection limits: none allowed on PA4/PA5/PC13–15.
- A0's permanent 10 kΩ pull-down from INT1.
- I2C at 400 kHz is good up to about 75 pF.

**Simulation** (`sim/`, ngspice): every check passes except:
- **Margin:** 500 mA from 4.40 V; the PVD window above; crystal drive level, which depends on the OSC_IN swing (measure at bring-up); and a +17 dB VDDA LC peak at 288 kHz (a 1 Ω in series with C7 would fix it, but it is left as is).
- **Fail:** I2C at 400 kHz with 100 pF of bus capacitance.

**Firmware** (`firmware/`): bare-metal bring-up firmware, with its pin table generated from `spec.py`. A Renode model of the board (custom RCC and LSM6DSV16X peripherals) runs 10 Robot Framework tests:
- 72 MHz from HSE, and the HSI fallback when the HSE fails;
- the user LED;
- IMU WHO_AM_I, samples, tap/double-tap, and wake on INT1 → PA0;
- the generated pin map;
- a walk of every header GPIO, driven one at a time;
- input monitoring;
- NRST and software reset.

All 10 pass. Emulation proves the firmware and the pin map, not the silicon.

**Superseded "known limitations":**
- C13 now sits on the locked VBUS path.
- J1.1 has a fuse and reverse protection.
- The user LED is brighter.
- The C2 GND return was shortened in the audit round.

## Second review wave (2026-10-02)

Five independent reviewers re-checked the reliability-pass board (commit d48be23), one area each. They used the datasheets, the GCT drawing, JLC/LCSC data, the board's copper (traced with the pcbnew API), new SPICE benches and the firmware emulation.

| Area | Grade | Must-fix |
|---|---|---|
| Power / protection / SPICE | C+ | A live supply plugged onto J1.1 rings VSYS past the TLV755's 6.0 V absolute maximum (R12 isn't in that path) |
| MCU core / firmware | B | Emulation suite failing on a stale pin-map expectation; no VTOR, so `stm32flash -g` hangs |
| USB-C / ESD | B | VBUS_D runs under the shell's GND standoff dimples |
| IMU / GPIO / full use | B+ | The stale pin-map test above; nothing else |
| Fab / DFM / CPL | B+ | None. CPL, BOM and JLC limits verified, gerbers reproduce. |

**Fixed:**
- **U2: TLV75533 → TLV76733DRVR** (C2848334). It uses the same DRV0006A land pattern, and the CPL correction stays 0.
  - VIN and EN are rated to 18 V.
  - SNS is tied to OUT and pin 5 to GND (TLV767 Table 5-1).
  - It still regulates at 250 mA from a 4.40 V port.
  - New SPICE bench 12 covers J1.1 hot-plug and 1.5–3 µH USB cables.
- **C12** is now a 16 V X5R part (CL05A475MO5NUNC, C318563).
- **VBUS_D** hops to B.Cu between the shell legs. An F.Cu keep-out covers the dimples, so nothing else routes there.
- **IMU:** the pour keep-out grows to 3.5 × 3.0 mm, so the pour stays clear of the GND pads. The bottom GND via moves outside the package body, and the 3V3 rail moves 0.07 mm.
- **Stitching and repair vias** now keep off SMD pads (`stitch.py`, `fixroute.py`). This removes the via found in Y1's pad.
- **The router keeps out of the screw-head areas** (r 2 mm) and straightens its paths.
- **Firmware:**
  - VTOR is set first in `Reset_Handler`.
  - The clock comes up from HSI with the PLL off, then the PLL, flash wait states and ADC /6.
  - CSS has an NMI fallback to HSI, and PVD is set to 2.9 V.
  - New `standby` (WKUP on A0) and `adc` commands.
  - Pin-map test fixed; 10/10 pass.
- **Re-route:**
  - Net classes: signals are 0.127 mm with 0.127 mm clearance, GND and the 3V3 rails 0.2 mm (3V3 was 0.3 mm), and VBUS/VSYS/5 V stay 0.3 mm.
  - Seed 3 then routes 100% with Freerouting alone, so no hand-finished copper remains.
  - DRC 0/0/0 and ERC 0/0. One GND cluster; no via within 0.1 mm of any SMD pad.
  - Crystal nets unchanged (top layer, no vias).
- **Docs:**
  - The 5V-pin output is 4.2–4.4 V at 200 mA, and a J1.1 short resets the MCU once.
  - No battery on J1.1 while USB is plugged in.
  - The PC13–15 3 mA limit is a shared total.
  - I2C1/SPI1-remap (ES096), TIM4/USART1-remap and I2C1-remap conflicts.
  - Never set the IMU's `I2C_I3C_disable` bit.
  - The OCS_Aux/SDO_Aux ties and H4 distance corrected; pinout.csv regenerated.

**Not changed (accepted):**
- **USBLC6 on stubs, not flow-through.** ST's Fig. 7 calls this layout unsuitable. The stubs are about 1.5–2 mm, which adds tens of volts at IEC 8 kV edges. Flow-through needs D+ to swap layers next to U3, and there is no room for that via.
- **VDDA caps:** C6/C7's copper path is 8–9 mm with two vias, and the FB1/C7 LC filter has a +17 dB peak at 288 kHz. Rotating the caps would force PA1/PA2 onto vias at the 0.5 mm pin pitch.
- **J1.1 hot-plug with leads over 1 µH:** the most pessimistic capacitor model puts the ring past Q1's ±12 V gate rating. Documented: connect first, then switch the supply on. An extra series resistor would clear every corner, but there is no room for it.
- **R12 in a J1.1 short while on USB:** 7–13 W for about 0.1 s until F1 trips. That is probably survivable once (Yageo's 5 s overload qualification), but not verified for the ½ W part. Test at first article.
- **D+ during hot-plug:** the VBUS-derived pull-up can briefly put up to 4.2 V on D+ while the MCU is still unpowered (FT limit 4.0 V at VDD = 0) for a few µs, in 2 of 8 corners.
- **VTERM:** 3.0–3.6 V holds only for VBUS 4.40–5.28 V; at 5.5 V it reaches 3.75 V (PA12 is FT).
- **Hard-wired D+ pull-up:** firmware that doesn't use USB still shows a device at the host. Drive PA12 low to hide it.

## JLC order round (2026-10-02)

Uploading the v1.3 files to a real JLCPCB Economic PCBA order turned up five problems that no DRC or review had caught. All are fixed in the fab outputs; the copper is unchanged.

| JLC said | Cause | Fix |
|---|---|---|
| U4 "Standard Only" (unselectable on Economic PCBA) | JLC flags the LSM6DSV16X, C5267406, as "PCBA Type: Standard Only, X-ray Inspection Required". Almost every ST IMU it stocks has the same flag. | U4 is now the **LSM6DSV, C41785564** ("Economic and Standard"). See below. |
| "Multiple lines in the BOM have been matched to the same part" on R1/R8/R10, R4/R5, R7/R9/R11, SW1/SW2 | `fab.sh` grouped the BOM by value + footprint, so one LCSC part ended up on two lines (`_NoSilk` footprint variants; RESET/BOOT0 values) and JLC unselected both | The BOM is grouped by LCSC number: 26 lines, one per part |
| Headers and USB-C not assembled | The BOM left THT parts out for hand soldering | JLC assembles them (Economic PCBA includes wave-soldered THT). J1/J3 are HanElectricity 2541WV-2x10P, C5383109. |
| "Component may be offset from the PCB" | The CPL used the board's lower-left corner as its origin, while the Gerbers use KiCad's page coordinates, so every part sat 100 / 125.5 mm off the board | The CPL is written in the Gerber frame (kicad pos coordinates as exported). `fab.sh` asserts that every part lands inside the outline. |
| (preview) THT parts misplaced | JLC's footprints for the header (drawn horizontal, origin at the pad-array centre) and USB4085 (origin 2.975 / 2.180 mm from A1) differ from KiCad's | Per-LCSC rotation and origin corrections (`JLC_ROT`, `JLC_OFS`), read from the EasyEDA footprints |

**IMU swap.** LCSC's datasheet for C41785564 is ST's DS13476 (LSM6DSV). Checked against the board and firmware:
- **Pins:** all 14 have the same functions and mode-1 (I2C) connections as the LSM6DSV16X. SDx/SCx go to Vdd_IO or GND (tied to GND), OCS_Aux/SDO_Aux to Vdd_IO or unconnected (Vdd_IO), CS is high and SA0 low.
- **Registers:** every register the test firmware touches has the same address and bits, and WHO_AM_I is 0x70. That covers IF_CFG, CTRL1/2/3/6/8, ALL_INT_SRC, WAKE_UP_SRC, TAP_SRC, FUNCTIONS_ENABLE, TAP_CFG0–2, TAP_THS_6D, TAP_DUR, WAKE_UP_THS/DUR and MD1_CFG. The tap and wake LSB scaling is identical too.
- **SFLP:** game rotation vector in the FIFO (tag 0x13), SFLP_GAME_EN in EMB_FUNC_EN_A (04h) and SFLP_ODR (5Eh). Same as the LSM6DSV16X.
- **Lost:** the machine-learning core, Qvar and the analog hub. None is used: Qvar and the analog hub need pins 2/3, which are grounded.
- **JLC footprint:** "LGA-14 ...-TL", pin 1 top-left like KiCad's, so its CPL correction is 0°. The LSM6DSV16X's was "-BR", +180°.
- **Unverified:** ST's store lists only LSM6DSV and LSM6DSVTR as order codes. "LSM6DSVETR" is the JLC/LCSC code, so confirm WHO_AM_I and SFLP output on the first boards.
- **Cost:** about $6.14 each at JLC for 5, against about $3 for the LSM6DSV16X.

**Order settings used:** 5 boards, all 5 assembled, Economic PCBA top side, 1.6 mm, **ENIG with green mask**.
- On Economic PCBA, 1.6 mm ENIG is offered only with green.
- Black and white mask need 0.13 mm between pads to keep a mask bridge (0.10 mm for green), and the USB-C pads are 0.11 mm apart.
- JLC's quote was $134.47 before shipping.

---

# NickLink v1.2 design review — 2026-10-01

v1.2 has two goals: a smaller board, and the quality-of-life fixes found when reviewing v1.1 (no 5 V pin, undocumented fixed I2C pull-ups, no reset button, SWD split across headers, a non-standard 16 MHz crystal, no user LED, no USB ESD protection). The pinout changes along the way, so v1.2 is **not** pin-compatible with v1.1.

## Result

| | v1.1 | v1.2 |
|---|---:|---:|
| Outline | 34 × 33 mm | **33.19 × 25.5 mm** |
| Area | 1122 mm² | **846 mm² (−24.6%)** |
| Headers | 2 × 2×10, 2.54 mm | same |
| M2 mounting holes | 4 | 4 |
| Front pin labels | none | all 40 pins |
| Parts (excl. holes) | 30 | 33 |

The board is now exactly as tall as the headers (25.4 mm body + edge clearance). Its width comes from the top row: hole, USB-C, hole, plus the two headers and their label strips.

## Changes and rationale

**Size**
- The board height equals the header length. Previously 6 mm sat above the headers for the USB connector, switch and holes. All four holes moved into the middle column: the top pair flank the USB connector, the bottom pair flank the crystal.
- Hole footprints use ISO 7380 button-head keep-outs (3.5 mm head, 4.1 mm courtyard) instead of the generic 5 mm.
- AMS1117 (SOT-223) plus a 22 µF tantalum became a TLV75533 (2×2 mm WSON) with 1 µF ceramics. This saves about 45 mm² and removes the open question about tantalum ESR.
- USBLC6 in SOT-666, LEDs in 0402, ferrite bead in 0402.
- The 3.0 × 2.5 mm Omron B3U buttons sit in the side channels between the MCU and the headers. Traces pass between their pads and underneath on the bottom layer.
- The project-local USB4085 courtyard is now the shield pads + 0.25 mm. Before, it was about 0.3 mm wider per side than the copper.

**Front labels** (requested): the header plastic covers its whole footprint, so labels sit in strips beside each pin column (v1.2: 1.2 mm strips, 0.8 mm text; v1.3: 1.4 mm strips, 1.0 mm text for JLC). The text is rotated, in short form (`A9`, `B12`, `RST`). This costs about 3.2 mm of width compared with a label-free layout and is the main reason v1.2 isn't narrower. The project copies of the header and button footprints have no silkscreen so the labels fit; their copper is unchanged from KiCad's library.

**Quality-of-life fixes**
- **5 V on J1.1:** USB VBUS → 1N5819WS → 5V rail. The diode lets the 5V pin act as an input without back-feeding the USB host. Input must stay ≤ 5.5 V (TLV755 maximum).
- **RESET button** on NRST. NRST now sits on J3.10, beside SWDIO/SWCLK/SWO, so a debugger connects to one header.
- **BOOT button** replaces the BOOT0 slide switch: hold BOOT, tap RESET. 10 kΩ pull-down on BOOT0; the 10 kΩ PB2/BOOT1 pull-down is kept.
- **8 MHz crystal** (YXC X32258MOB4SI, 12 pF load, 15 pF C0G caps). 16 MHz worked electrically, but 8 MHz matches the clock trees that Blue Pill, STM32duino and CubeMX assume, and sits mid-range of the 4–16 MHz HSE spec. Gain margin is about 73 by AN2867 (requirement ≥ 5).
- **I2C pull-ups removed** from PB6/PB7. They were fixed, undocumented and stiff (1.5 kΩ), and most I2C modules bring their own.
- **User LED** on PC13, active low (sink only).
- **ESD:** USBLC6-2P6 on D+/D− with 100 nF on its VBUS pin, per ST's layout guidance.

**Pinout:** header pins follow the MCU's package order, so the fanout is nearly planar. Function pairs share a row: UART1, SWDIO/SWCLK, SWO/NRST, I2C1, CAN, UART2, SPI2. Both headers have 3V3 and GND; J1 adds 5V.

## Routing

The board is autorouted with Freerouting after placement, on two layers with GND pours on both. Stitching vias are added afterwards and kept clear of silkscreen text. The design rules are unchanged from v1.1:

- Tracks: 0.15 mm signal, 0.30 mm power, 0.25 mm ground.
- Clearance: 0.13 mm.
- Vias: 0.6 / 0.3 mm.
- Copper to edge: 0.2 mm.

Critical nets, from `tools/netreport.py`:

| Net | Routing |
|---|---|
| HSE_IN / HSE_OUT | 6.0 / 4.2 mm, top layer only, no vias |
| USB_D+ / USB_D− | v1.2 numbers; see the v1.3 section for the current board. Fine for 12 Mbit/s full speed; not an impedance-controlled pair. |
| VDDA | through the 0402 ferrite to 100 nF + 1 µF (v1.3 moves both next to the VDDA pin) |

## Verification

KiCad 10.0.6 (Docker `kicad/kicad:10.0`):

- ERC: **0 errors, 0 warnings** (`checks/final-erc.rpt`). The v1.1 ignored-check set is unchanged.
- The netlist exported from the schematic is checked pin-by-pin against `tools/spec.py` (`tools/check_netlist.py`).
- DRC with schematic parity and all track errors: **0 violations, 0 unconnected, 0 parity issues** (`checks/final-drc.json`). No DRC exclusions.
- Front/back renders and copper plots inspected.

These checks establish connectivity and geometry. They do not establish signal integrity, ESD performance, regulator thermals or a working prototype.

## Open items / bring-up risks

1. **Regulator thermals.** The 250 mA 3V3 budget assumes about 150 °C/W on this two-layer board, an estimate scaled from TI's 100 °C/W four-layer figure. Measure the temperature at the intended load.
2. **Crystal load.** 15 pF assumes 3–5 pF stray. If the HSE measures fast, use 18 pF (LCSC C1549).
3. **JLC Extended parts** (each adds a loading fee): TLV75533, USBLC6-2P6 (genuine ST stock is limited; a TECH PUBLIC alternative exists), B3U buttons, the 8 MHz crystal, the 0402 ferrite, and possibly the LEDs. See `tools/parts_research.md`.
4. **The USB-C connector and headers are hand-soldered** (through-hole). *(Superseded: JLC assembles them since the 2026-10-02 order round.)*
5. **First article:** short check; current-limited 5 V; measure 5V/3V3/VDDA; SWD attach and RESET button; HSE startup; USB enumeration in both orientations; BOOT+RESET into the USART1 bootloader; user LED; then the peripherals you need.

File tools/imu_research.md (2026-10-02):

# LSM6DSV16X IMU: parts research for NickLink (STM32F103, 3.3 V, I2C1)

> **Update 2026-10-02, as built:** the board ships with the **LSM6DSV** (C41785564), not the LSM6DSV16X. JLC lists C5267406 as "Standard PCBA only", and NickLink is an Economic PCBA board. The LSM6DSV's datasheet (DS13476) gives the same 14-pin assignment and mode-1 connections as section 1 below, the same registers for everything in section 9, and WHO_AM_I 0x70. It lacks the MLC, Qvar and analog hub. Everything below still applies, except the C5267406 part number and its +180° JLC rotation (C41785564's JLC footprint needs 0°). See docs/REVIEW.md, "JLC order round".

Main source: ST datasheet **DS13510 Rev 4 (May 2023)**. I pulled it from LCSC's mirror because st.com timed out from this machine:
https://datasheet.lcsc.com/datasheet/pdf/7d66556bb254f99e058243c7371e051d.pdf?productCode=C5267406
(the canonical copy is https://www.st.com/resource/en/datasheet/lsm6dsv16x.pdf). Page numbers below refer to DS13510.

The datasheet gives the package as **2.5 x 3.0 x 0.86 mm** (Figure 33, p.172). That is 0.86 mm, not the 0.83 mm in the brief.

## 1. Pinout (Table 2, p.11; Figure 5, p.9)

| Pin | Name | Mode 1 function (no aux sensors) |
|---|---|---|
| 1 | SDO/SA0 | I2C address LSB (SA0) / SPI SDO |
| 2 | SDx/AH1/Qvar1 | "Connect to Vdd_IO or GND if the analog hub and Qvar are disabled." |
| 3 | SCx/AH2/Qvar2 | "Connect to Vdd_IO or GND if the analog hub and Qvar are disabled." |
| 4 | INT1 | Programmable interrupt |
| 5 | Vdd_IO | I/O supply, footnote: "Recommended 100 nF filter capacitor." |
| 6 | GND | 0 V |
| 7 | GND | 0 V |
| 8 | Vdd | Core supply, footnote: "Recommended 100 nF filter capacitor." |
| 9 | INT2 | Programmable interrupt 2 / DEN |
| 10 | OCS_Aux | "Connect to Vdd_IO or leave unconnected" (footnote: "Leave pin electrically unconnected and soldered to PCB.") |
| 11 | SDO_Aux | "Connect to Vdd_IO or leave unconnected" (same footnote) |
| 12 | CS | "1: SPI idle mode / I2C / MIPI I3C communication enabled; 0: SPI communication mode / I2C / MIPI I3C disabled" |
| 13 | SCL | I2C SCL / SPI SPC |
| 14 | SDA | I2C SDA / SPI SDI / 3-wire SDO |

**The KiCad `Sensor_Motion:LSM6DSM` symbol can be reused.** I read its pins in the KiCad 10 docker image: 1 SDO/SA0, 2 SDX, 3 SCX, 4 INT1, 5 VDDIO, 6 GND, 7 GND, 8 VDD, 9 INT2, 10 OCS_Aux, 11 SDO_Aux, 12 CS, 13 SCL, 14 SDA. Every number matches Table 2 above. The names differ only cosmetically (SDX for SDx/AH1/Qvar1, SCX for SCx/AH2/Qvar2). Its default footprint is `Package_LGA:LGA-14_3x2.5mm_P0.5mm_LayoutBorder3x4y`.

One electrical difference: the LSM6DSM symbol types pin 7 GND as `passive`, while pin 6 is `power_in`. This only affects ERC.

## 2. I2C-mode connections

- **CS (pin 12): tie to Vdd_IO (+3.3V).** CS = 1 enables I2C. CS does have a default internal pull-up (Table 23, p.50: "Default: input with pull-up", which is disabled only when I2C_I3C_disable = 1). I still recommend a hard tie, because a floating CS could drop the part into SPI mode. Figure 28 (p.47) shows the mode-1 I2C hookup.
- **SDO/SA0 (pin 1): address select.** Confirmed (sec. 5.1.2, p.22): "If the SDO/SA0 pin is connected to the supply voltage, LSb is 1 (address 1101011b); else if the SDO/SA0 pin is connected to ground, the LSb value is 0 (address 1101010b)."
  - SA0 = GND gives **0x6A**; SA0 = Vdd_IO gives **0x6B**. In 8-bit form these are D4h/D5h and D6h/D7h (Table 12).
  - SA0 has **no** pull-up by default (SDO_PU_EN = 0), so it must be strapped. **Recommendation: SA0 to GND (0x6A).**
- **SDx / SCx (pins 2, 3): tie to GND or Vdd_IO. Do not leave them floating.** This differs from the LSM6DSM/DSOX habit of floating them. **Recommendation: GND.** This also suits the LSM6DSOX, whose datasheet says "Connect to VDDIO or GND".
- **OCS_Aux / SDO_Aux (pins 10, 11): leave unconnected (pads soldered).** In modes 1 and 2 both have internal pull-ups by default. Table 23 note: "Pull-up is disabled if bit OIS_PU_DIS = 1 in register PIN_CTRL (02h)". Figure 28 draws them as NC.
- **INT2 (pin 9): leave unconnected.** It is an output that is "forced to ground" by default (Table 23), so it never floats. Optionally route it to a spare GPIO or test pad.

## 3. Decoupling and supply

- Datasheet (p.47): "Power supply decoupling capacitors (C1, C2 = 100 nF ceramic) should be placed as near as possible to the supply pin of the device."
  - Fit **one 100 nF on Vdd (pin 8) and one 100 nF on Vdd_IO (pin 5)**.
  - Place each right at its pin and return it to pins 6/7 GND by the shortest path.
  - Part: JLC Basic **C1525** (Samsung CL05B104KO5NNNC, 100 nF 16 V X7R 0402), https://jlcpcb.com/partdetail/C1525
- **Sharing one 3.3 V rail is fine.** Table 4 (p.14) gives Vdd 1.71 to 3.6 V and Vdd_IO 1.08 to 3.6 V. Searching the datasheet turned up no sequencing or "Vdd_IO ≤ Vdd" rule. Keep the two separate 100 nF caps anyway.
- Optional: many boards add 1 µF bulk on the shared rail. ST does not require it. This is my suggestion only.

## 4. I2C pull-ups

- Datasheet (p.21): "Both the lines must be connected to Vdd_IO through external pull-up resistors."
  - Figure 28 shows "Pull-up to be added, Rpu=10kOhm".
  - The I2C interface supports fast mode (400 kHz) and fast mode plus (1 MHz).
- **4.7 kΩ is confirmed as a good choice.** My arithmetic, not from ST:
  - Fast-mode rise time is ≤ 300 ns, and t_r ≈ 0.85·R·C. With 4.7 kΩ that allows about **75 pF** of bus capacitance.
  - A short on-board bus is about 10 to 30 pF, so there is room for 1 or 2 short-lead modules.
  - Minimum R for 3 mA at V_OL 0.4 V: (3.3 − 0.4)/3 mA ≈ **1 kΩ**.
  - Most breakout modules carry their own 4.7k or 10k pull-ups, which sit in parallel and lower the total. Check that the parallel total stays ≥ about 1.5 kΩ.
  - Drop to 2.2 kΩ only if the bus capacitance exceeds about 75 pF, for example long cables.
- Part: JLC **Basic C25900** (UNI-ROYAL 0402WGF4701TCE, 4.7 kΩ ±1%, 0402, 62.5 mW). LCSC shows 10.1 M in stock at about $0.002 each. https://jlcpcb.com/partdetail/C25900
- **Internal pull-ups on the IMU** (Table 23 p.50, Tables 28/30 p.57-58; internal value 30 to 50 kΩ):

  | Pin | Default | Control |
  |---|---|---|
  | SDA | off | SDA_PU_EN, IF_CFG (03h) bit 7, default 0 |
  | SCL | none | not configurable |
  | SA0 | off | SDO_PU_EN, PIN_CTRL (02h), default 0 |
  | CS | on | removed only by I2C_I3C_disable = 1 |
  | OCS_Aux, SDO_Aux | on | OIS_PU_DIS = 1 in PIN_CTRL (02h) disables them |
  | SDx, SCx | off | SHUB_PU_EN, IF_CFG |

  Nothing needs changing for this design.

## 5. INT1 output

- From IF_CFG (03h), Table 30 p.58:
  - **PP_OD (bit 3): 0 = push-pull (default), 1 = open-drain.** Applies to INT1 and INT2.
  - **H_LACTIVE (bit 4): 0 = active high (default), 1 = active low.**
- Before configuration INT1 is "output forced to ground" (Table 23).
- So the default is **push-pull, active-high**: no pull-up needed, and the MCU uses a rising-edge EXTI.
- IF_CFG is not reset by a software reset.
- PA0 is also the STM32F103 WKUP pin (rising edge). It pairs naturally with an active-high INT1 for wake from Standby.

## 6. PCB layout (ST TN0018 and the ST community article)

I could not download TN0018 itself: st.com timed out and Mouser served a bot-check page. The rules below come from TN0018 excerpts quoted in search results and from ST's article https://community.st.com/t5/mems-and-sensors/how-to-optimize-your-pcb-design-for-mems-sensors/ta-p/605083. TN0018 links: https://www.st.com/resource/en/technical_note/tn0018-surface-mounting-guidelines-for-mems-sensors-in-an-lga-package-stmicroelectronics.pdf (Mouser mirror: https://www.mouser.com/pdfDocs/tn0018-surface-mounting-guidelines-for-mems-sensors-in-an-lga-package-stmicroelectronics.pdf).

Actionable rules:
- **Keep traces, vias and copper pours off the top layer under the package** (ST article: "Never place any routing or via on the top side under the device"; TN0018: "no vias or traces below the sensor footprint"). For accelerometers and gyros, ST allows a power plane or signal routing on the bottom side.
- **Route symmetrically.** Traces should leave each pad outward, parallel to the pad's long edge, all at the same width. Connect GND pads with normal traces, not by flooding pour into the pad.
- **All lands the same size.** TN0018 rule when the gap between pins is > 200 µm: land = package pin + 0.1 mm in each dimension. Package pins are 0.475 x 0.25 mm (Figure 33), so the target land is **0.575 x 0.35 mm**.
  - The KiCad footprint pads are 0.625 x 0.35 mm, 0.05 mm longer than the TN0018 figure. Fine for JLC; trim them if you want an exact TN0018 match.
- **Soldermask: NSMD.** The mask opening is the land + 0.1 mm, and ST recommends opening the mask outside the land. KiCad's default mask expansion is close to this; at JLC a 0.5 mm pitch can lose the web between pads, which is acceptable.
- **Keep away from mechanical stress and heat:**
  - Avoid screws, mounting holes, standoffs, connectors and push-buttons, and keep away from board protrusions and flex points. ST article: keep "at least 10 mm away from the source of the external force", and place the sensor between fasteners.
  - Keep away from heat sources: the LDO, MCU hot spots, any battery.
- **Do not let anything touch the package.** No epoxy, potting, heat sink or shield in contact. Side solder fillets are not allowed: LGA packages have metal traces on their sides.
- **Unverified, quoted from memory of TN0018 rather than read:** stencil about 100 to 127 µm with apertures 1:1 to the lands; no specific board-edge distance in mm. Get TN0018 manually if you need exact figures.

## 7. JLCPCB / LCSC

LCSC API figures were queried on 2026-10-01 (https://wmsc.lcsc.com/ftps/wm/product/detail?productCode=...). Library type comes from the jlcpcb.com part pages.

| Part | C-number | Package | LCSC stock | Price (1 / 10 / 100) | JLC type |
|---|---|---|---|---|---|
| **LSM6DSV16XTR** | **C5267406** | LGA-14 (2.5x3) | 6,187 | $3.44 / $2.99 / $2.47 | **Extended** (verified) |
| LSM6DSOXTR (fallback) | C481766 | LGA-14 (2.5x3) | 4,456 | $3.92 / $3.41 / $2.79 | page did not state the type; **Extended assumed (unverified)** |
| LSM6DSOTR (fallback) | C2655100 | LGA-14 (2.5x3) | 4,761 | $3.92 / $3.38 / $2.52 | **Extended** (verified) |
| 4.7 kΩ 1% 0402 | C25900 | 0402 | 10.1 M | about $0.002 | **Basic** (verified) |
| 100 nF X7R 0402 | C1525 | 0402 | (not shown) | | **Basic** (verified) |

The JLC pages for C481766 and C2655100 note MSL 3 and X-ray inspection. Extended parts add the usual per-unique-part setup fee.

Links: https://jlcpcb.com/partdetail/STMicroelectronics-LSM6DSV16XTR/C5267406 · https://www.lcsc.com/product-detail/C5267406.html · https://jlcpcb.com/partdetail/STMicroelectronics-LSM6DSOXTR/C481766 · https://jlcpcb.com/partdetail/STMicroelectronics-LSM6DSOTR/C2655100

**The fallbacks drop in with no netlist change.** I checked the LSM6DSOX datasheet (DS12814 Rev 3, from LCSC): it has the same 14-pin assignment, SDx/SCx "Connect to VDDIO or GND", and OCS_Aux "Leave unconnected". The DSOX/DSO register maps differ, though; for example their INT pin config bits live in CTRL3_C, not IF_CFG. They are therefore not a firmware drop-in.

## 8. KiCad 10 library

Checked in the `kicad/kicad:10.0` docker image.

- **There is no LSM6DSV16X symbol.** `Sensor_Motion` holds only LSM6DS3, LSM6DSL and LSM6DSM.
  - **Use `Sensor_Motion:LSM6DSM` with Value = LSM6DSV16X** (pin numbers verified in section 1).
  - Change its Datasheet field to the DS13510 URL.
- **Footprint: `Package_LGA:LGA-14_3x2.5mm_P0.5mm_LayoutBorder3x4y`**, the symbol's default.
  - Its 14 pads run 1–4 down the left (3 mm side), 5–7 along the bottom, 8–11 up the right, and 12–14 along the top, matching ST's numbering.
  - Do not use `Bosch_LGA-14_3x2.5mm_P0.5mm`, which has a different pin arrangement.
- A JLC 3D model or rotation check is still needed at CPL time. Not verified.

## 9. Firmware notes

- **SFLP game rotation vector:**
  - The on-chip sensor fusion low-power (SFLP) block produces a 6-axis game rotation vector (quaternion), plus gravity vector and gyro bias.
  - Enable it with SFLP_GAME_EN in EMB_FUNC_EN_A (04h, embedded-function bank).
  - Set the rate in SFLP_ODR (5Eh, embedded bank): 15/30/60/**120 (default)**/240/**480 Hz max** (Table 324).
  - The quaternion is delivered **only through the FIFO** ("The X, Y, Z quaternion components are stored in FIFO", p.2; FIFO tag 0x13). Enable SFLP_GAME_FIFO_EN, read X/Y/Z as half-floats, and compute W from them.
  - 480 Hz of FIFO words is easy at 400 kHz I2C.
- **Tap and wake-up on INT1:**
  - Single-tap, double-tap, wake-up, free-fall, 6D and activity/inactivity all route to INT1 through MD1_CFG (5Eh, main bank): INT1_SINGLE_TAP, INT1_DOUBLE_TAP, INT1_WU, INT1_FF, INT1_6D, INT1_SLEEP_CHANGE.
  - They require **INTERRUPTS_ENABLE = 1 in FUNCTIONS_ENABLE (50h)**.
  - INT1_CTRL (0Dh) covers data-ready and FIFO interrupts.
- **Driver:** ST's `lsm6dsv16x-pid` C driver (STMicroelectronics GitHub `STMems_Standard_C_drivers`) covers all of this. I am citing it from knowledge; I did not fetch it.
- **STM32F103 I2C:** the I2C peripheral has known errata (BUSY-flag lock-up after a reset mid-transfer). Add a bus-recovery routine that toggles SCL 9 times as GPIO.

## Recommended connection list

| Pin | Name | Net |
|---|---|---|
| 1 | SDO/SA0 | GND (address 0x6A) |
| 2 | SDx | GND |
| 3 | SCx | GND |
| 4 | INT1 | IMU_INT1 to PA0 (push-pull, active-high default; no pull-up) |
| 5 | Vdd_IO | +3.3V, with its own 100 nF (C1525) at the pin |
| 6 | GND | GND |
| 7 | GND | GND |
| 8 | Vdd | +3.3V, with its own 100 nF (C1525) at the pin |
| 9 | INT2 | NC (optional test pad or spare GPIO) |
| 10 | OCS_Aux | NC (pad soldered) |
| 11 | SDO_Aux | NC (pad soldered) |
| 12 | CS | +3.3V (hard tie, selects I2C) |
| 13 | SCL | I2C1_SCL to PB6, 4.7 kΩ (C25900) to +3.3V |
| 14 | SDA | I2C1_SDA to PB7, 4.7 kΩ (C25900) to +3.3V |

Fit one pull-up pair per bus, not per device.

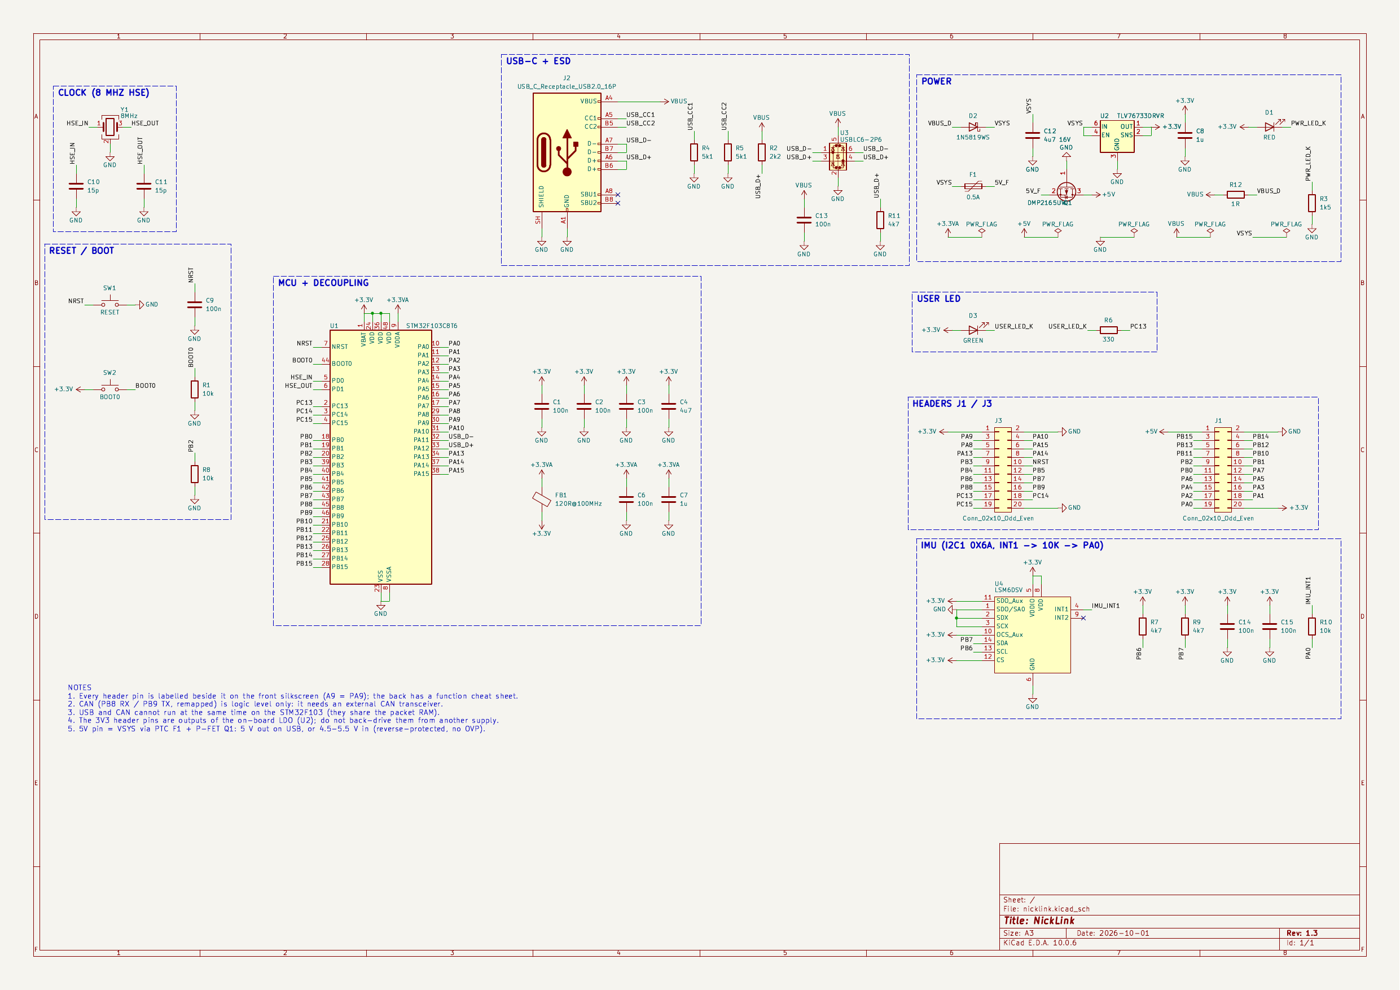
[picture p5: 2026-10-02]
docs/images/schematic.png

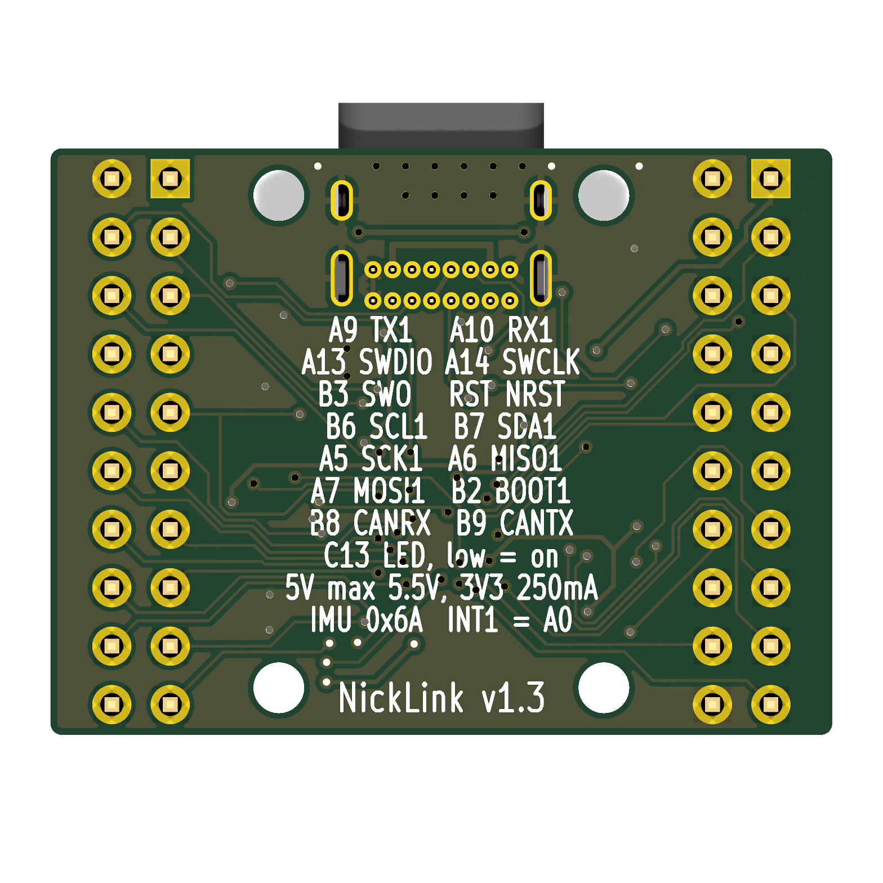
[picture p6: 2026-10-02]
docs/images/bottom.png

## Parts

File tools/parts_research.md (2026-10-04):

> **As built (v1.3). Order from `fabrication/v1.3/nicklink_BOM_JLC.csv`, not from the v1.2 study below.**
>
> - **U2:** TI TLV76733DRVR, LCSC **C2848334**. Same WSON-6 land as the TLV755 in section 1, but pin 2 is SNS (tied to OUT) and pin 5 is GND, not NC. VIN/EN absolute maximum is **18 V**, not 6.0 V. Do not order TLV75533PDRVR C2861750.
> - **C12:** 4.7 µF 16 V 0402, Samsung CL05A475MO5NUNC, LCSC **C318563**. Not 10 µF 0603 C19702.
> - **R6:** 330 Ω (C25104), about 1.3 mA. Not 1.5 kΩ and not 1 kΩ. The green LED is brighter than the 0.4 mA note this file used to give.
> - **U4:** ST LSM6DSV, C41785564, on I2C1 (PB6/PB7), address 0x6A. Not the LSM6DSV16X.
> - **J1, J3:** HanElectricity 2541WV-2x10P, C5383109. **J2:** GCT USB4085, C7095263. All three are in the CPL. JLC assembles them. Do not plan to hand-solder them.
> - **LEDs:** Everlight 16-213 red C264407 and green C74338, both 0402. The 0603 KENTO notes below are the v1.2 study.

# NickLink parts research

Researched 2026-10-01 for v1.2. The body still records that study. Where it names TLV75533PDRVR, a 10 µF 0603 input cap, or a 1.5 kΩ user-LED resistor as the part to fit, that choice was superseded by the list above.

**How LCSC numbers were checked:** each C-number was looked up in JLCPCB's own parts-search backend (the `selectSmtComponentList` API behind jlcpcb.com/parts). That lookup returns the MPN, manufacturer, package, library type (`base` = Basic, `expand` = Extended), the "preferred" flag and stock. Stock figures are from 2026-10-01. Spot checks on lcsc.com product pages (C51118, C82942, C7519, C191023, C231329) agreed. Datasheets came from LCSC's datasheet links or from the manufacturers.

Per-part pages: `https://jlcpcb.com/partdetail/<C-number>` and `https://www.lcsc.com/product-detail/<C-number>.html`.

**v1.2 change from the lead (superseded for the LDO):** v1.2 used **TI TLV75533PDRVR (WSON-6 2x2)**. The fitted v1.3 regulator is **TI TLV76733DRVR, C2848334** (see the banner). The ESD part **ST USBLC6-2P6 (SOT-666)** is still fitted. AP2112K and USBLC6-2SC6 were fallbacks only.

## Summary table

| # | Function | Chosen MPN | LCSC | JLC lib | Verified | Key datasheet facts |
|---|---|---|---|---|---|---|
| 1 | 3V3 LDO, as built | TI **TLV76733DRVR** (WSON-6-EP 2x2) | **C2848334** | Extended | Pinout checked on the v1.3 schematic | Pins: 1 OUT, 2 SNS (tied to OUT), 3 GND, 4 EN, 5 GND, 6 IN, pad = GND. VIN/EN absolute max **18 V**. Replaces TLV75533PDRVR C2861750 (6.0 V abs max), which section 1 studied for v1.2. Do not order C2861750. |
| 1b | LDO fallback | Diodes AP2112K-3.3TRG1 (SOT-25) | C51118 | Extended | Yes | Pins 1 VIN, 2 GND, 3 EN, 4 NC, 5 VOUT. 1 µF ceramic X5R/X7R in and out. Dropout at 600 mA: 250 typ / 400 max mV. θJA 184 °C/W. VIN up to 6.0 V recommended, 6.5 V absolute max. |
| 2 | USB ESD | ST **USBLC6-2P6** (SOT-666) | **C15999** (genuine ST, 2.9k stock). C2827693 is the TECH PUBLIC second source (46k stock). | Extended | Yes | Pins: 1 I/O1, 2 GND, 3 I/O2, 4 I/O2, 5 VBUS, 6 I/O1. Same pinout as SC6. 3.5 pF max line capacitance, VRM 5.25 V. |
| 2b | ESD fallback | ST USBLC6-2SC6 (SOT-23-6L) | C7519 | Extended | Yes | Same die and pinout. |
| 3 | VBUS→+5V Schottky | Hottech **1N5819WS** (SOD-323) | **C191023** | **Basic** | Yes (4.9M stock) | 40 V, 1 A rated. VF ≈ 0.30 V at 100 mA and ≈ 0.37 V at 500 mA (typ curve, 25 °C), 0.60 V max at 1 A. Pd 250 mW at 25 °C, derated to 0 at 125 °C. IR 0.5 mA max at 40 V. |
| 4 | Reset/boot switch | Omron **B3U-1000P** | **C231329** | Extended | Yes (142k stock, $0.19) | Omron PCB pads at ±1.7 mm centres, 0.8 x 1.7 mm. KiCad `SW_SPST_B3U-1000P` uses ±1.7 mm, 0.9 x 1.7 mm, so it matches. |
| 4b | Cheaper switch | hanxia HX-B3U-1000P-1.6N | C49234121 | Extended | MPN/stock yes; **footprint not verified (no datasheet on JLC/LCSC)** | $0.08 vs $0.19. Also extended, so it saves no setup fee. Not recommended. |
| 5 | 8 MHz crystal | YXC **X32258MOB4SI** (YSX321SL, SMD3225-4P) | **C2682775** | Extended | Yes (83k stock) | CL 12 pF, ESR 150 Ω max (datasheet; the JLC listing says 180 Ω), C0 ≤3 pF, C1 ≤5 fF, ±10/±20 ppm, drive level 100 µW. Crystal sits on pads 1–3, pads 2 and 4 are GND. |
| 5c | Crystal load caps | FH 0402CG150J500NT, **15 pF** C0G 50 V 0402 | **C1548** | **Basic** | Yes | Alternative: 18 pF C1549 (Basic). |
| 6r | Red LED, as built | Everlight 16-213/R6C-AQ2R2B/3T (0402) | **C264407** | Extended | On the v1.3 BOM | Power LED, with R3 1.5 kΩ. The KENTO 0603 C2286 notes in section 6 are the v1.2 study. |
| 6g | Green LED, as built | Everlight 16-213/GHC-YR1S1/3T (0402) | **C74338** | Extended | On the v1.3 BOM | User LED on PC13. R6 is **330 Ω (C25104)**, about 1.3 mA, not 1.5 kΩ or 1 kΩ. The KENTO 0603 C12624 notes in section 6 are the v1.2 study. |
| 7 | Ferrite bead | Murata **BLM15AG121SN1D** (0402) | **C85812** | Extended (no 0402 bead exists in JLC Basic) | Yes | 120 Ω ±25% at 100 MHz, 550 mA rated, 0.19 Ω max DCR. The Basic option is 0603 BLM18PG121SN1D **C14709** (120 Ω, 2 A, 0.05 Ω). |
| 8 | 100 nF 0402 X7R 16 V | Samsung CL05B104KO5NNNC | **C1525** | **Basic** | Yes | |
| 8 | 1 µF 0402 | Samsung CL05A105KA5NQNC (X5R **25 V**) | **C52923** | **Basic** | Yes | The 10 V version (CL05A105KP5NNNC, C14445) is Extended. 25 V is the better choice anyway. |
| 8 | 10 µF 0603 X5R 10 V | Samsung CL10A106KP8NNNC | **C19702** | **Basic** | Yes | **Not fitted.** v1.2 study only. C12 is 4.7 µF 16 V 0402, Samsung CL05A475MO5NUNC, **C318563**. |
| 8 | 10 kΩ 0402 1% | UNI-ROYAL 0402WGF1002TCE | **C25744** | **Basic** | Yes | |
| 8 | 5.1 kΩ 0402 1% | UNI-ROYAL 0402WGF5101TCE | **C25905** | **Basic** | Yes | |
| 8 | 1.5 kΩ 0402 1% | UNI-ROYAL 0402WGF1501TCE | **C25867** | **Basic** | Yes | |
| 9 | MCU | ST STM32F103C8T6 (LQFP-48) | C8734 | Extended, **Preferred** (no loading fee) | Yes (150k stock) | See section 9. |
| 10 | USB-C | GCT **USB4085-GF-A** | **C7095263** | Extended (JLC lists it as "Plugin", i.e. THT) | Yes (3.6k stock, $1.40) | Through-hole, right-angle USB 2.0 Type-C receptacle, 16 pins. JLC assembles it (Economic PCBA, wave soldered). Its EasyEDA footprint origin is 2.975 / 2.180 mm from pad A1 (`JLC_OFS` in `tools/fab.sh`). |
| 11 | 2x10 headers (J1, J3) | HanElectricity **2541WV-2x10P** | **C5383109** | Extended ("Plugin") | Yes (4.6k stock, $0.07) | Male, vertical, 2.54 mm, 6 mm pins, 3 mm tail, gold. JLC assembles them. Same EasyEDA footprint (horizontal, origin at the pad centre: -90° and a centring offset in the CPL) as hanxia HX PZ2.54-2x10P ZZ, C42372518 (10k stock), the second source. |
| 12 | IMU (U4), as built | ST **LSM6DSV** (JLC/LCSC code LSM6DSVETR) | **C41785564** | Extended, **Economic and Standard** | Yes (979 stock, ~$6.14 at qty 5) | Replaces the LSM6DSV16X C5267406, which JLC lists as Standard PCBA only. Same pinout, registers, WHO_AM_I and SFLP; see docs/REVIEW.md, JLC order round. EasyEDA footprint "-TL" (pin 1 top-left): CPL correction 0°. |

## Key numbers

- **3V3 load budget (v1.2 study of the TLV75533PDRVR, not the fitted TLV76733; 40 °C ambient, Tj ≤ 100 °C, so ΔT = 60 K):**
  - With TI's JEDEC 2s2p (4-layer) RθJA of 100.2 °C/W, the LDO can dissipate 0.60 W. That allows **428 mA at VIN = 4.7 V**, or 352 mA at VIN = 5.0 V (a hot VBUS).
  - A small 2-layer board will be worse. At an estimated ~150 °C/W (**my estimate, not verified**) the limits are 286 mA at 4.7 V and 235 mA at 5.0 V.
  - **Recommended continuous 3V3 budget: 250 mA total**, including the MCU (~50 mA at 72 MHz with peripherals on). Up to ~400 mA is reasonable if the EP has vias into solid GND copper on both layers.
  - The AP2112K fallback (184 °C/W) allows 233 mA at 4.7 V and 192 mA at 5.0 V, so its budget is **~200 mA**.
- **Crystal:** X32258MOB4SI (C2682775), CL = 12 pF.
  - C = 2·(12 − Cs) gives 18/16/14 pF for Cs = 3/4/5 pF. **Use 15 pF C0G (C1548, Basic).** That gives an effective CL of 10.5–12.5 pF. Pulling is about 11 ppm/pF (C1 = 5 fF), so the error is ≤ ~15 ppm. USB full speed tolerates ±2500 ppm.
  - Gain margin: gm_crit = 4·ESR·(2πf)²·(C0+CL)² = 4·150·(2π·8 MHz)²·(15 pF)² = **0.34 mA/V**. The F103 HSE gm is **25 mA/V min**, so the **gain margin is ≈73**, far above AN2867's minimum of 5. Using the JLC-listed 180 Ω ESR still gives 61.
  - A 20 pF crystal (X32258MSB4SI, C2682774) would need 30–34 pF caps and has a margin of ≈31. The 12 pF part is better.
  - Note: DS5319 suggests "10 pF … rough estimate of combined pin and board capacitance". Taken literally, that would mean ~4 pF caps. I followed your 3–5 pF stray (per-pin Cin(HSE) is 5 pF, so the lumped value across the crystal is ~3–4 pF). If a measured HSE runs fast, go to 18 pF (C1549).
- **LEDs at 1.5 kΩ from 3.3 V (v1.2 resistor value; fitted R6 is 330 Ω):**
  - Red: (3.3 − 1.85)/1.5k = **0.97 mA**, roughly 7–15 mcd.
  - Green: (3.3 − 2.4)/1.5k = **0.60 mA** (0.47 mA in the highest VF bin). Scaling the 210–430 mcd at 5 mA rating gives roughly 25–50 mcd. That is clearly visible, and in fact **brighter than the red**. No resistor change is needed for visibility.
  - If you want the two to look equally bright, use 5.1 kΩ on the green (≈0.2 mA, and it reuses an existing BOM line).
- **5 V-tolerant (FT) pins on LQFP-48 (DS5319 Rev 18, Table 5):**
  - **FT:** PA8, PA9, PA10, PA11, PA12, PA13, PA14, PA15, PB2, PB3, PB4, PB6, PB7, PB8, PB9, PB10, PB11, PB12, PB13, PB14, PB15.
  - **Not FT:** PA0–PA7, PB0, PB1, **PB5**, PC13, PC14, PC15.

## 1. LDO: TLV75533PDRVR (v1.2 study, not fitted)

**TLV75533PDRVR, C2861750** (TI, WSON-6-EP(2x2), Extended, 16,284 in stock, $0.28).
Source: https://www.ti.com/lit/ds/symlink/tlv755p.pdf (SBVS320D, Sept 2024)

- **Pinout (Table 4-1, DRV column):** OUT = 1, NC = 2 and 5, GND = 3, EN = 4, IN = 6, thermal pad internally connected to GND ("connect to a large-area ground plane"). This matches the lead's mapping.
  - The KiCad `Package_SON:WSON-6-1EP_2x2mm_P0.65mm_EP1x1.6mm` footprint numbers pads 1–3 down the left side, 4–6 up the right side, and pad 7 is the 1.0 x 1.6 mm EP. Its description references the same TI DRV package.
  - Watch out: the KiCad footprint also has two unnumbered paste-only pads on the EP. That is normal.
- **Capacitors:** CIN 1 µF min and COUT 1 µF min (Recommended Operating Conditions). The footnote requires >0.47 µF effective at the pin, assuming 50% derating. COUT max is 200 µF. Use X5R/X7R ceramic (7.1.1).
  - A 1 µF 0402 25 V X5R (C52923) at 3.3 V keeps roughly 0.5–0.7 µF after DC bias. That is borderline for this TLV755 study, which suggested **10 µF 0603 (C19702) or 2x 1 µF on OUT, and ≥1 µF on IN.** That 10 µF part is not on the v1.3 board. C12 is 4.7 µF 16 V 0402, C318563, and C8 (LDO output) is 1 µF, C52923.
- **Dropout (3.3 V ≤ VOUT < 5 V, 500 mA):** 150 typ / 215 max mV from −40 to 85 °C, 238 mV max from −40 to 125 °C. At 4.7 V in there is about 1.2 V of headroom.
- **Thermal (5.4):** DRV RθJA is **100.2 °C/W** (JEDEC high-K), RθJB 64.3, RθJC(bot) 34.7. Thermal shutdown trips at 165 °C. Recommended Tj is ≤125 °C.
- **Input voltage:** recommended **1.45–5.5 V**, absolute max **6.0 V**. EN has the same limits.
  - On USB VBUS (≤5.25 V, or ≤5.5 V for a USB-C source) behind the Schottky this is fine.
  - Anything fed to the 5 V header pin that bypasses the Schottky must stay ≤5.5 V. There is no margin for a 6 V wall-wart.
- **Other notes:**
  - EN high threshold is 1 V min, so tie EN to IN.
  - There is no reverse-current protection. VOUT > VIN + 0.3 V exceeds absolute max (7.1.4). Do not back-feed 3V3 from a header while 5 V is absent unless you add a diode.
  - Short-circuit limit is 355 mA (foldback).
- **Layout (7.4.1):** put the caps close to the part, use copper planes, add thermal vias around and under the EP, and the EP must be soldered.

**AP2112K-3.3TRG1, C51118** (Diodes, SOT-25, Extended, $0.17). Fallback only.
Source: https://www.diodes.com/assets/Datasheets/AP2112.pdf (DS39724 Rev 2-2)

- Pins 1 VIN, 2 GND, 3 EN, 4 NC, 5 VOUT. This matches your list.
- 1 µF in and out. Ceramic is fine and X5R/X7R is recommended (Note 4).
- Dropout at 600 mA: 250 typ / 400 max mV.
- θJA (SOT25) 184 °C/W, θJC 96 °C/W.
- VIN 2.5–6.0 V recommended, 6.5 V absolute max.
- The JLC stock under MPN "AP2112K-3.3TRG1" also includes TECH PUBLIC clones (C23380830, C3021085). **Use C51118** for the genuine Diodes part.

**SOT-23-5 alternatives** (all Extended at JLC; none of them is Basic):

| Part | LCSC | Iout | Thermal | Notes |
|---|---|---|---|---|
| TLV75533PDBVR (SOT-23-5) | C404027 | 500 mA | RθJA 231 °C/W JEDEC, 100.8 on TI EVM | Same die as the chosen part. The WSON is ~2.3x better. |
| ME6211C33M5G-N | C82942 | 500 mA | Pd 300 mW (no θJA given) | Cheapest ($0.06). Weakest thermals. |
| RT9013-33GB | C47773 | 500 mA | θJA 250 °C/W | 400 mV dropout at 500 mA. |
| XC6220B331MR-G (SOT-25) | C86534 | 1 A | 166.7 °C/W on Torex 40x40 mm 2-layer board | Best SOT-25 thermals, but $$ |

**Verdict (v1.2, superseded):** TLV75533PDRVR was the best of this set thermally (100 °C/W) and was in stock. Do not fit it on v1.3. The board uses TLV76733DRVR, C2848334.

## 2. ESD: USBLC6-2P6 (primary), with USBLC6-2SC6 as fallback

Source: ST USBLC6-2 datasheet, which covers both packages (Doc ID 11265; LCSC copy on the C7519 page). The current ST URL is https://www.st.com/resource/en/datasheet/usblc6-2.pdf.

- **Pinout (Fig. 1, identical for SOT23-6L "USBLC6-2SC6" and SOT-666 "USBLC6-2P6", top view):** 1 I/O1, 2 GND, 3 I/O2, 4 I/O2, 5 VBUS, 6 I/O1. This **matches** your list.
  - Pins 1 and 6 are the same internal node, and so are 3 and 4. The part is flow-through.
- **Layout:**
  - ST's Fig. 18 ("PCB layout considerations") shows **D+in on pin 1, GND on pin 2 and D−in on pin 3 on the connector side**. D+out (pin 6), VBUS (pin 5) and D−out (pin 4) are on the MCU side, with **CBUS = 100 nF at pin 5**.
  - The text says to "put the protection device as close as possible to the disturbance source (generally the connector)". Keep the I/O, VBUS and GND tracks as short as possible, because ~6 nH of track adds about 144 V of clamp overshoot in ST's example. Use a direct via to the GND plane at pin 2.
  - So: **pins 1–3 face the USB-C connector, pins 4–6 face the MCU, and put 100 nF from pin 5 to GND.**
- **Ratings:** VRM 5.25 V, Ci/o-GND 2.5 typ / 3.5 max pF, IEC 61000-4-2 ±8 kV contact / ±15 kV air.
- **LCSC:**
  - USBLC6-2P6 **C15999** is genuine ST, SOT-666-6, 2,924 in stock, $0.25. Low stock: check it before ordering.
  - C2827693 is a TECH PUBLIC "USBLC6-2P6" (SOT-666-6, 46k in stock, $0.15) and is a pin-compatible clone.
  - Several other "USBLC6-2P6" listings are actually **SOT-563** (e.g. C5199178, C21713974, C49451919). Do not pick those blindly. SOT-563 and SOT-666 are close but not the same land pattern.
  - SC6 fallback: C7519 (genuine ST).

## 3. Schottky: 1N5819WS, C191023 (Basic)

Source: Hottech datasheet via LCSC: https://www.lcsc.com/datasheet/lcsc_datasheet_2409300937_Guangdong-Hottech-1N5819WS_C191023.pdf

- 1N5819WS and B5819WS are the same device class (40 V / 1 A, SOD-323). B5819WS listings (C7420331, C64886) are Extended or Preferred. **C191023 is the only Basic one**, so it was chosen.
- **VF (typical curve, 25 °C):** ≈0.30 V at 100 mA, ≈0.37 V at 500 mA. The datasheet maximum is 0.60 V at 1 A.
- **Ratings:**
  - IF(AV) is 1 A on paper. In practice SOD-323 is thermally limited: Pd is 250 mW at 25 °C, derated linearly to 0 at 125 °C, which gives ~212 mW at 40 °C.
  - At 500 mA that is 0.37 × 0.5 = 0.185 W, which is marginal. **Keep the +5 V rail draw at ≤ ~400 mA through the diode.**
- **Leakage:** 0.5 mA max at 40 V and 25 °C (10 mA at 100 °C). At 5 V reverse it is roughly 5–10 µA (curve). That is fine for back-feed blocking. Expect VBUS to sit slightly above 0 V when the header supplies 5 V and no cable is attached.
- **Polarity:**
  - The datasheet outline shows the band on the "−" (cathode) end.
  - KiCad `Diode_SMD:D_SOD-323` puts pad 1 at x = −1.05, and the silkscreen bracket's closed end (x = −1.61) is on the pad 1 side. That follows the KiCad convention of **pad 1 = cathode = band**.
  - Symbol pin K → pad 1. Matches.

## 4. Tactile switch: B3U-1000P, C231329

Source: https://omronfs.omron.com/en_US/ecb/products/pdf/en-b3u.pdf

- B3U-1000P is the top-actuated version without a ground terminal or boss.
- **Omron PCB pad:** 4.2 mm outer and 2.6 mm inner, so 0.8 x 1.7 mm pads at ±1.7 mm.
- **KiCad `SW_SPST_B3U-1000P`:** pads 1/2 at ±1.7 mm, 0.9 x 1.7 mm. Its description is literally Omron's ("Ultra-small-sized Tactile Switch… without Ground Terminal, without Boss"). It matches.
- **LCSC/JLC:** C231329 is genuine Omron, SMD 3x2.5 mm, Extended, 142k in stock, $0.19. JLC has no Basic switch in this size.
- **Cheaper drop-ins:**
  - HX-B3U-1000P-1.6N (C49234121, hanxia, $0.08, 51k in stock) is named as a clone. **Its land pattern is unverified**, because neither JLC nor LCSC has a datasheet for it.
  - Other 3x2.5 mm parts (XKB TS-3025, Korean Hroparts K2-1822) are Extended too, and their footprints are unverified.
  - Since every candidate is Extended, the setup fee is the same. **Stay with genuine B3U-1000P.**

## 5. Crystal: X32258MOB4SI, C2682775

Source: https://www.lcsc.com/datasheet/lcsc_datasheet_2411121006_YXC-Crystal-Oscillators-X32258MOB4SI_C2682775.pdf

- YSX321SL, 8.000 MHz, fundamental AT-cut.
- **Specs:** CL 12 pF, ESR (R1) **150 Ω max**, C0 3 pF max, C1 5 fF max, ±10 ppm at 25 °C, ±20 ppm from −40 to 85 °C, drive level 100 µW.
- **Pads:** the YXC footprint diagram shows the crystal between **pads 1 and 3 (diagonal), with pads 2 and 4 = GND**. Numbering is counter-clockwise from the bottom-left in top view.
  - KiCad `Crystal_SMD_3225-4Pin_3.2x2.5mm` places pad 1 at (−1.1, +0.85) bottom-left, 2 bottom-right, 3 top-right, 4 top-left. It **matches**.
- **JLC Basic:** there is no 8 MHz 3225 crystal in JLC Basic. The Basic 8 MHz parts are C12674 (HC-49S-SMD) and C115962 (5032-2P), which are different footprints. Keep the Extended 3225.
- **gm check:**
  - DS5319 Table 22 gives HSE 4–16 MHz, RF = 200 kΩ, and **gm = 25 mA/V min** (startup).
  - The AN2867 criterion is gain margin = gm/gm_crit > 5, with gm_crit = 4·ESR·(2πF)²·(C0+CL)².
  - Result: 0.34 mA/V, so the **margin is 73. It passes easily.**
  - Sources: AN2867 Rev 15 copy at https://www.ecsxtal.com/store/pdf/stm32-microcontroller-application-note-092823.pdf, and https://ecsxtal.com/considerations-when-designing-crystals-into-stm32-microcontrollers/
- **Load caps: 15 pF C0G 0402, C1548 (Basic).**

## 6. LEDs

The 0603 KENTO parts in this section are the v1.2 study. The fitted LEDs are the 0402 Everlights in the banner (C264407, C74338), and the user-LED resistor is 330 Ω, not 1.5 kΩ.

- **Red:** KT-0603R **C2286** (Basic).
  - Datasheet: https://www.lcsc.com/datasheet/lcsc_datasheet_1810231112_Hubei-KENTO-Elec-KT-0603R_C2286.pdf
  - The I-V curve reaches ~1 mA at ≈1.85 V.
- **Green:** KT-0603G **C12624** (**Extended**). JLC Basic has 0603 red and white only, and green only in 0805: KT-0805G **C2297**, Basic.
  - Datasheet: https://www.lcsc.com/datasheet/lcsc_datasheet_1806151818_Hubei-KENTO-Elec-KT-0603G_C12624.pdf
  - It is InGaN emerald (λd 513–528 nm). The I-V curve starts at ~1 mA at ≈2.4 V, and VF bins at 5 mA run from 2.6 to 3.1 V.
- **At 1.5 kΩ (v1.2 study, not the fitted R6):** red ≈0.97 mA, green ≈0.47–0.60 mA. The green would be visibly bright (tens of mcd, brighter than the red). v1.3 fits R6 = 330 Ω instead. Do not change it to 1 kΩ or leave it at 1.5 kΩ.
- **v1.2 option, not done:** to avoid one Extended setup fee, the study suggested switching the green LED to 0805 (C2297). v1.3 keeps the 0402 Everlight.
- **MCU pin choice:** do not source LED current from PC13–PC15 (see section 9). Sinking ≤3 mA is allowed.

## 7. Ferrite bead

- JLC Basic has **no 0402 ferrite**. Its Basic beads are 0603 C1002 and C14709, and 0805 C1015 and C1017.
- **0402 choice:** Murata BLM15AG121SN1D **C85812** (Extended, $0.01, 387k in stock). It is 120 Ω ±25% at 100 MHz, **rated 550 mA**, with 0.19 Ω max DCR. That easily exceeds 50 mA, with a 10 mV drop at 50 mA.
  - Datasheet: https://www.lcsc.com/datasheet/lcsc_datasheet_2304140030_Murata-Electronics-BLM15AG121SN1D_C85812.pdf
- **If the layout can take 0603:** BLM18PG121SN1D **C14709** is Basic (120 Ω, 2 A, 0.05 Ω) and saves one Extended fee.
- Sunlord GZ1005 0402 parts are not Basic at JLC.

## 8. Passives (all Basic, all verified)

| Value | MPN | LCSC |
|---|---|---|
| 100 nF 0402 X7R 16 V | CL05B104KO5NNNC | C1525 |
| 1 µF 0402 X5R 25 V | CL05A105KA5NQNC | C52923 |
| 10 µF 0603 X5R 10 V (not fitted) | CL10A106KP8NNNC | C19702 |
| 10 kΩ 0402 1% | 0402WGF1002TCE | C25744 |
| 5.1 kΩ 0402 1% | 0402WGF5101TCE | C25905 |
| 1.5 kΩ 0402 1% | 0402WGF1501TCE | C25867 |
| 15 pF 0402 C0G 50 V (crystal) | 0402CG150J500NT | C1548 |
| 18 pF 0402 C0G 50 V (alt) | 0402CG180J500NT | C1549 |

There is no Basic 1 µF 0402 at 10 V (C14445 is Extended). The 25 V Basic part is better for DC bias anyway.

## 9. STM32F103C8 facts

Sources: DS5319 Rev 18 (https://www.st.com/resource/en/datasheet/stm32f103c8.pdf, LCSC copy on C8734), AN2606, RM0008.

- **FT pins (Table 5, LQFP48 column):**
  - **5 V tolerant:** PA8–PA15, PB2, PB3, PB4, PB6–PB15.
  - **Not tolerant:** PA0–PA7, PB0, PB1, PB5, PC13–PC15.
  - Caveats:
    - The FT absolute max is VDD + 4.0 V (Table 6). FT is not 5 V tolerant while VDD is unpowered: the limit is then 4.0 V.
    - The internal pull-up/pull-down must be disabled to hold more than VDD + 0.3 V (Table 35, note 3).
    - PA11/PA12 (USB) and PA9/PA10 (USART1) are FT.
- **PC13–PC15 (Table 5, note 5):** these pins are supplied through the backup power switch, which "only sinks a limited amount of current (3 mA)".
  - In output mode, speed must be ≤2 MHz with ≤30 pF load.
  - They "must not be used as a current source (e.g. to drive a LED)". So an LED on PC13 must be wired to sink current, at ≤3 mA.
- **HSE:** a 4–16 MHz crystal or ceramic resonator (Table 22: fOSC_IN 4 / 8 typ / 16 MHz). Confirmed.
- **Clock tree:**
  - 8 MHz HSE → PLL ×9 → 72 MHz SYSCLK, which is the maximum.
  - The USB prescaler (RCC_CFGR.USBPRE = 0) divides the PLL by 1.5, giving 48 MHz.
  - The DS5319 clock-tree note requires both HSE and PLL enabled, with USBCLK at 48 MHz.
  - Confirmed. RM0008 RCC_CFGR via https://community.st.com/t5/stm32-mcus-embedded-software/sysclk-and-usb-prescaler-confusion/td-p/547793 and https://github.com/zephyrproject-rtos/zephyr/issues/47146
- **System bootloader (AN2606):** BOOT0 = 1 and BOOT1 (PB2) = 0 select system memory. On F10xxx the bootloader uses USART1 with PA9 = TX and PA10 = RX, 8 data bits, even parity, 1 stop bit, and auto-baud on 0x7F.
  - Confirmed. https://wiki.cuvoodoo.info/lib/exe/fetch.php?media=stm32f1xx:an2606_boot_mode.pdf
  - Note: PB2/BOOT1 is FT.
  - On F103 there is no USB DFU in the system bootloader; that only exists on connectivity-line parts.
- **NRST:** "permanent pull-up resistor" RPU = 30/40/50 kΩ (Table 38, §5.3.14). Fig. 31 recommends **0.1 µF from NRST to GND**. So a 100 nF cap plus a button to GND is sufficient. Confirmed.

## 10. USB4085-GF-A, C7095263

- **JLC/LCSC:** GCT, packaging listed as "Plugin" (= THT). Extended, 3,640 in stock, $1.40.
- **Distributors** (DigiKey https://www.digikey.com/en/products/detail/gct/USB4085-GF-A/9859662, element14 https://my.element14.com/gct-global-connector-technology/usb4085-gf-a/usb-conn-2-0-type-c-r-a-rcpt-16pos/dp/2924867): "USB 2.0 Type C, Receptacle, 16 Position, Through Hole, Right Angle". Confirmed as **a THT USB-C 2.0 receptacle**.
- **GCT drawing (LCSC datasheet):**
  - Pins: A1/A12/B1/B12 GND, A4/A9/B4/B9 VBUS, A5 CC1, B5 CC2, A6 Dp1, A7 Dn1, B6 Dp2, B7 Dn2, A8 SBU1, B8 SBU2.
  - Ratings: VBUS 5 A combined, GND 6.25 A combined, other pins 0.25 A each, 48 V DC.
  - Use 5.1 kΩ (C25905) from each of CC1 and CC2 to GND, and tie Dp1 to Dp2 and Dn1 to Dn2.

## Not verified / caveats

- Real RθJA of the v1.2 TLV75533PDRVR study on this 2-layer board. The ~150 °C/W figure is an estimate; TI only gives the JEDEC 4-layer value of 100.2. It is not a measurement of the fitted TLV76733.
- Footprint compatibility of the HX-B3U-1000P-1.6N clone (no datasheet available).
- Crystal drive level with the F103 HSE was not computed. The YXC part is rated 100 µW and 8 MHz at CL = 12 pF is a normal operating point, but this is unverified.
- The 1N5819WS VF and leakage values at 100/500 mA are read from typical curves, not guaranteed maxima.
- The ST website timed out from here. The ST datasheets used were DS5319 Rev 18 (via LCSC) and USBLC6-2 Doc ID 11265 Rev 5 (via LCSC). The pinout and layout guidance have not changed between revisions as far as I know, but I did not diff against the latest ST revision.
- Stock and prices are from 2026-10-01. USBLC6-2P6 C15999 (2.9k) and USB4085 C7095263 (3.6k) have the thinnest stock.

**Extended-part count for JLC, v1.2 study** (each unique Extended part adds a loading fee; Preferred parts and Basic parts do not). The fitted LDO is TLV76733DRVR C2848334, not TLV75533PDRVR, and the LEDs are the 0402 Everlights, not KT-0603G. See the banner.

- In this v1.2 set, TLV75533PDRVR, USBLC6-2P6, X32258MOB4SI, B3U-1000P and KT-0603G are always Extended.
- BLM15AG121 is also Extended if you keep the 0402 ferrite.
- The STM32 is Preferred, so it adds no fee.
- The cheap reductions are the green LED to 0805 (C2297) and the ferrite to 0603 (C14709).
- Footprint references: https://gitlab.com/kicad/libraries/kicad-footprints

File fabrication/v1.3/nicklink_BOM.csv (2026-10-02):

Comment | Designator | Footprint | LCSC Part # | Notes | Assembly
100n | C1,C2,C3,C6,C9,C13,C14,C15 | C_0402_1005Metric | C1525 | C1: VDD pin 1/VBAT decoupling; C2: VDD pin 24 decoupling; C3: VDD pin 36 decoupling; C6: VDDA; C13: USBLC6 VBUS decoupling; C14,C15: IMU VDD/VDDIO | SMD
4u7 | C4 | C_0402_1005Metric | C23733 | VDD3 (pin 48) bulk: DS5319 Fig. 14 requires 4.7 uF on VDD3 | SMD
1u | C7,C8 | C_0402_1005Metric | C52923 | C7: VDDA; C8: LDO output | SMD
15p | C10,C11 | C_0402_1005Metric | C1548 | C0G; crystal CL 12 pF | SMD
4u7 16V | C12 | C_0402_1005Metric | C318563 | Samsung CL05A475MO5NUNC; LDO input, 16 V X5R (J1.1 hot-plug ring); USB allows <= 10 uF | SMD
RED | D1 | LED_0402_1005Metric | C264407 | Everlight 16-213/R6C-AQ2R2B/3T; Power | SMD
1N5819WS | D2 | D_SOD-323 | C191023 | Blocks back-feed from VSYS / the 5V pin into USB | SMD
GREEN | D3 | LED_0402_1005Metric | C74338 | Everlight 16-213/GHC-YR1S1/3T; User LED, PC13 low = on | SMD
0.5A | F1 | Fuse_0805_2012Metric | C22435898 | LUTE 0805L050/16XR; 5V pin short / reverse-supply limit: Ihold 0.5 A, Itrip 1 A, 16 V | SMD
120R@100MHz | FB1 | L_0402_1005Metric | C85812 |  | SMD
Conn_02x10_Odd_Even | J1,J3 | PinHeader_2x10_P2.54mm_Vertical_NoSilk | C5383109 | HanElectricity 2541WV-2x10P (male, 6 mm pins, 3 mm tail) | THT
USB_C_Receptacle_USB2.0_16P | J2 | USB_C_Receptacle_GCT_USB4085_EdgeSilk | C7095263 | GCT USB4085-GF-A | THT
DMP2165UW | Q1 | SOT-323_SC-70_NoSilk | C388477 | Diodes DMP2165UW-7; 5V pin reverse-polarity switch (gate to GND) | SMD
10k | R1,R8,R10 | R_0402_1005Metric | C25744 | R1: BOOT0 pull-down; R10: IMU INT1 isolation; R8: BOOT1 pull-down | SMD
2k2 | R2 | R_0402_1005Metric | C25879 | USB FS D+ pull-up (with R11: 1.5k to 3.4 V, VBUS-derived) | SMD
1k5 | R3 | R_0402_1005Metric | C25867 |  | SMD
5k1 | R4,R5 | R_0402_1005Metric | C25905 |  | SMD
330 | R6 | R_0402_1005Metric | C25104 | ~1.2-1.8 mA (PC13 sinks <= 3 mA) | SMD
4k7 | R7,R9,R11 | R_0402_1005Metric | C25900 | R7: I2C1 SCL pull-up; R9: I2C1 SDA pull-up; R11: D+ pull-up divider; VBUS bleed | SMD
1R | R12 | R_0805_2012Metric | C873764 | YAGEO SR0805FR-471RL; Hot-plug damping (anti-surge, 500 mW) | SMD
BOOT0/RESET | SW1,SW2 | SW_SPST_B3U-1000P_NoSilk | C231329 | SW2: Hold while resetting to enter the USART1 system bootloader | SMD
STM32F103C8T6 | U1 | LQFP-48_7x7mm_P0.5mm | C8734 |  | SMD
TLV76733DRVR | U2 | WSON-6-1EP_2x2mm_P0.65mm_EP1x1.6mm_ThermalVias03 | C2848334 | TI TLV76733DRVR | SMD
USBLC6-2P6 | U3 | SOT-666 | C15999 |  | SMD
LSM6DSV | U4 | LGA-14_3x2.5mm_P0.5mm_LayoutBorder3x4y_NoSilk | C41785564 | ST LSM6DSV (JLC: LSM6DSVETR) | SMD
8MHz | Y1 | Crystal_SMD_3225-4Pin_3.2x2.5mm | C2682775 | YXC X32258MOB4SI (CL 12 pF) | SMD

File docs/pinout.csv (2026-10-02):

Header | Pin | Net | Front label | Signal / function | 5 V tolerant
J3 | 1 | +3.3V | 3V3 | 3V3 regulated output
J3 | 2 | GND | GND | GND
J3 | 3 | PA9 | A9 | PA9 / UART1 TX | FT
J3 | 4 | PA10 | A10 | PA10 / UART1 RX | FT
J3 | 5 | PA8 | A8 | PA8 | FT
J3 | 6 | PA15 | A15 | PA15 | FT
J3 | 7 | PA13 | A13 | PA13 / SWDIO | FT
J3 | 8 | PA14 | A14 | PA14 / SWCLK | FT
J3 | 9 | PB3 | B3 | PB3 / SWO | FT
J3 | 10 | NRST | RST | NRST (reset, active low) | 3.3 V only
J3 | 11 | PB4 | B4 | PB4 | FT
J3 | 12 | PB5 | B5 | PB5 | 3.3 V only
J3 | 13 | PB6 | B6 | PB6 / I2C1 SCL (4.7k pull-up, IMU) | 3.3 V only
J3 | 14 | PB7 | B7 | PB7 / I2C1 SDA (4.7k pull-up, IMU) | 3.3 V only
J3 | 15 | PB8 | B8 | PB8 / CAN RX (remap) | FT
J3 | 16 | PB9 | B9 | PB9 / CAN TX (remap) | FT
J3 | 17 | PC13 | C13 | PC13 / user LED (active low) | 3.3 V only
J3 | 18 | PC14 | C14 | PC14 | 3.3 V only
J3 | 19 | PC15 | C15 | PC15 | 3.3 V only
J3 | 20 | GND | GND | GND
J1 | 1 | +5V | 5V | 5V (USB VBUS via Schottky + 0.5 A PTC; 4.5-5.5 V input, reverse-polarity protected)
J1 | 2 | GND | GND | GND
J1 | 3 | PB15 | B15 | PB15 / SPI2 MOSI | FT
J1 | 4 | PB14 | B14 | PB14 / SPI2 MISO | FT
J1 | 5 | PB13 | B13 | PB13 / SPI2 SCK | FT
J1 | 6 | PB12 | B12 | PB12 | FT
J1 | 7 | PB11 | B11 | PB11 / I2C2 SDA / UART3 RX | FT
J1 | 8 | PB10 | B10 | PB10 / I2C2 SCL / UART3 TX | FT
J1 | 9 | PB2 | B2 | PB2 / BOOT1, 10k pull-down | FT
J1 | 10 | PB1 | B1 | PB1 | 3.3 V only
J1 | 11 | PB0 | B0 | PB0 | 3.3 V only
J1 | 12 | PA7 | A7 | PA7 / SPI1 MOSI | 3.3 V only
J1 | 13 | PA6 | A6 | PA6 / SPI1 MISO | 3.3 V only
J1 | 14 | PA5 | A5 | PA5 / SPI1 SCK | 3.3 V only
J1 | 15 | PA4 | A4 | PA4 | 3.3 V only
J1 | 16 | PA3 | A3 | PA3 / UART2 RX | 3.3 V only
J1 | 17 | PA2 | A2 | PA2 / UART2 TX | 3.3 V only
J1 | 18 | PA1 | A1 | PA1 | 3.3 V only
J1 | 19 | PA0 | A0 | PA0 / WKUP / IMU INT1 via 10k | 3.3 V only
J1 | 20 | +3.3V | 3V3 | 3V3 regulated output

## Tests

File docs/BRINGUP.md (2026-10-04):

# NickLink v1.3 bring-up and board test

This takes a freshly assembled board from "just arrived" to "every part checked", in about 15 minutes. You need:

- The board, and a USB-C cable to a computer (or a USB charger) for power.
- An **STLINK-V3MINIE** with its STDC14 flat cable. The cable ends in a 1.27 mm socket, so you also need a way onto the board's 2.54 mm header: an STDC14-to-2.54 mm adapter board (Waveshare sells one with the probe), or 1.27-to-2.54 mm jumper wires.
- A serial terminal: PuTTY, the Arduino serial monitor, `screen`, or `python -m serial.tools.miniterm`.
- Optional: a multimeter, a few jumper wires, and an LED with a 1 kΩ resistor for probing pins.

The test program is [`firmware/`](../firmware/): a bare-metal bring-up firmware for this exact pinout. A prebuilt image is in [`firmware/prebuilt/`](../firmware/prebuilt/), so no toolchain is needed. It talks over USART1, which reaches your computer through the ST-Link's built-in virtual COM port, so one probe both flashes the board and shows the console.

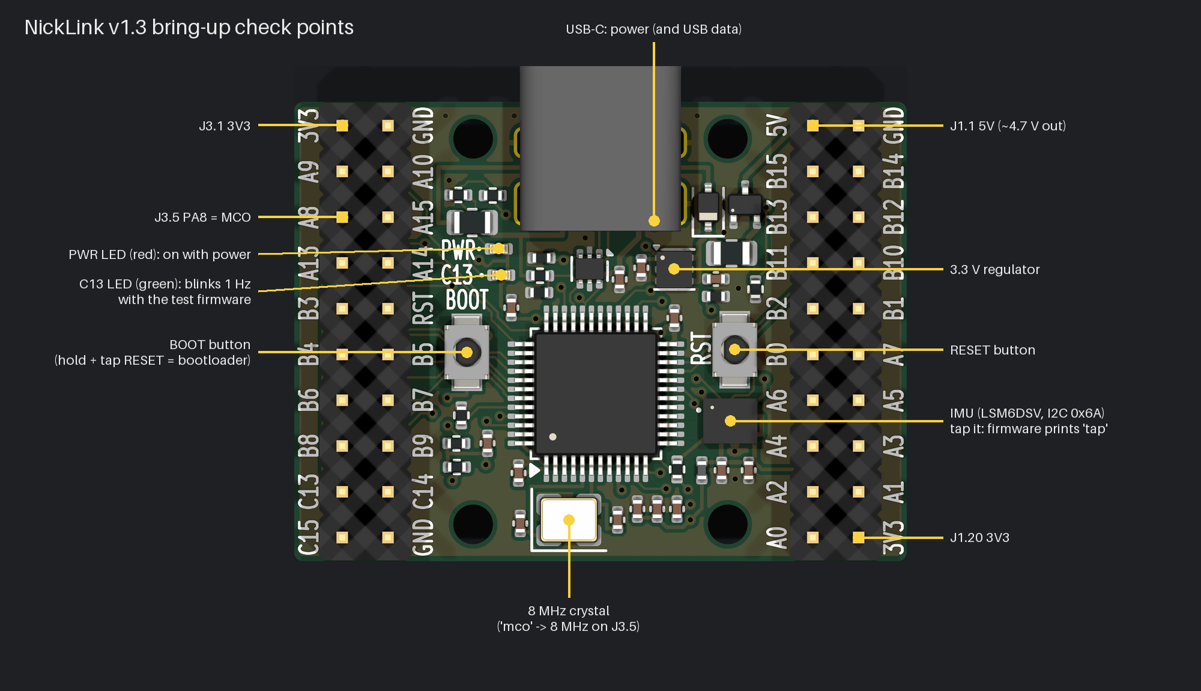
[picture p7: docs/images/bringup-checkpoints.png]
Bring-up check points


## 1. Before power

Look the board over for solder bridges, especially at the USB-C pins, the IMU (the small square chip right of the MCU) and the MCU's pins.

With a meter on resistance, check that none of these pairs is a dead short (under 10 Ω):

| Between | Expect |
|---|---|
| J3.1 (3V3) and J3.2 (GND) | Not a short. It reads low at first while the capacitors charge, then rises. |
| J1.1 (5V) and J1.2 (GND) | Not a short |

## 2. First power

Plug USB-C into a computer.

- The **red PWR LED** comes on.
- **J3.1 / J1.20 (3V3)** reads 3.23–3.37 V.
- **J1.1 (5V)** reads about 4.6–4.8 V.
- Unplug, flip the USB-C plug over and plug in again. The LED should light in both orientations.

A brand-new STM32 has no program, so it will not enumerate. The D+ pull-up is hard-wired from VBUS (R2 2.2 kΩ and R11 4.7 kΩ), so the computer still sees a USB device as soon as the cable is plugged in. USB data needs firmware that speaks USB. The test firmware in this guide holds D+ low and keeps USB off.

## 3. Wire the ST-Link

STLINK-V3MINIE to NickLink wiring

| Wire | STLINK-V3MINIE (STDC14 / CN4) | NickLink | Signal |
|---|---|---|---|
| Red | pin 3 T_VCC | J3.1 | 3V3 (the probe only *senses* it) |
| Grey | pin 5 GND | J3.2 | GND |
| Orange | pin 4 T_SWDIO | J3.7 | PA13 SWDIO |
| Green | pin 6 T_SWCLK | J3.8 | PA14 SWCLK |
| Blue | pin 12 T_NRST | J3.10 | NRST |
| Cyan | pin 13 T_VCP_RX | J3.4 | PA10, USART1 RX |
| Magenta | pin 14 T_VCP_TX | J3.3 | PA9, USART1 TX |
| Purple, optional | pin 8 T_SWO | J3.9 | PB3 SWO, for SWV trace only |

- **The probe does not power the board.** Keep the board on USB-C (or 5 V on J1.1) the whole time. T_VCC tells the probe the target's voltage; it supplies nothing.
- **TX and RX are not a mistake.** ST names the VCP pins from the target's side. In UM2910, pin 13 T_VCP_RX is a probe *output* that drives the MCU's RX (PA10), and pin 14 T_VCP_TX is a probe *input* that reads the MCU's TX (PA9).
- **STDC14 pin 1** is marked on the probe and on the cable. Odd pins are in one row and even pins in the other.
- J3 pin 1 is the top-left pin, labelled `3V3`, with the USB-C connector at the top. Odd pins are the outer column, along the board edge.

All the SWD, serial and reset signals are on J3, so one header does everything.

## 4. Flash the test firmware

Use any one of these, with the board powered and the ST-Link plugged into your computer.

**STM32CubeProgrammer (GUI, Windows/macOS/Linux):**
1. Select ST-LINK, port SWD, mode **Under reset**, then **Connect**. "Under reset" uses the NRST wire and works even if the chip is running something that disables SWD.
2. Open `firmware/prebuilt/nicklink-test.hex`, click **Download**, then **Disconnect**. The board starts on its own.

**STM32CubeProgrammer CLI:**
```sh
STM32_Programmer_CLI -c port=SWD mode=UR -w firmware/prebuilt/nicklink-test.hex -v -rst
```

**OpenOCD** (0.12 or newer):
```sh
openocd -f interface/stlink.cfg -f target/stm32f1x.cfg \
  -c "program firmware/prebuilt/nicklink-test.hex verify reset exit"
```

**stlink tools** (1.8 or newer):
```sh
st-flash --reset write firmware/prebuilt/nicklink-test.bin 0x08000000
```

**To build it yourself:** `cd firmware && make` (or `make DOCKER=1` without an ARM toolchain). Then flash `firmware/build/nicklink-test.hex`.

If the tool reports an unknown device ID or refuses the chip, the STM32 may be a clone. For OpenOCD, add `-c "set CPUTAPID 0"` before the target `-f`. CubeProgrammer may also ask to update the ST-Link's own firmware first; let it.

## 5. Open the console

The ST-Link shows up as a serial port: **"STMicroelectronics STLink Virtual COM Port"** on Windows (a `COMx` port), `/dev/ttyACM0` on Linux, or `/dev/cu.usbmodem*` on macOS. Open it at **115200 baud, 8N1**, then press the board's **RESET** button. You should see lines like these:

```
NickLink v1.3 board test, SYSCLK 72000000 Hz
clock: HSE 8 MHz -> PLL x9 = 72 MHz (APB1 36 MHz, ADC 12 MHz, USB 48 MHz), CSS on
RCC_CFGR 0x001D840A, PVD 2.9 V: VDD ok, not from Standby
reset cause: NRST pin (RESET button) (RCC_CSR 0x...)
boot: flash aliased at 0x0 (BOOT0 was low); BOOT1/PB2 reads 0 (10k pull-down, want 0)
flash size reg 64 KB, UID ...        (many chips report 128 KB)
IMU: WHO_AM_I = 0x70 OK (LSM6DSV family)
IMU: 480 Hz, +-2 g, +-2000 dps; tap/double-tap/wake-up -> INT1 -> PA0 (EXTI0 rising)
type 'help'
>
```

Type `help` to list the commands. [`firmware/README.md`](../firmware/README.md) documents each one.

## 6. Test checklist

Work down the list; each line tests one part of the board.

| # | Part | Do this | Pass when |
|---|---|---|---|
| 1 | Power, 3V3 regulator | Steps 2 and 5 | PWR LED on, 3V3 in range, `VDD ok` in the banner |
| 2 | MCU + SWD | Step 4 | Flash and verify succeed |
| 3 | 8 MHz crystal | Read the banner `clock:` line | `HSE 8 MHz -> PLL x9 = 72 MHz` and `SYSCLK 72000000`. A dead crystal shows `64 MHz` / HSI instead. |
| 3b | Crystal accuracy (optional) | `mco`, then put a frequency counter or scope on **J3.5** | 8.000 MHz within about ±30 ppm (±240 Hz). `mco off` stops it. |
| 4 | User LED (green, PC13) | Watch it | Blinks once a second |
| 5 | RESET button | Press it | The banner reprints with `reset cause: NRST pin (RESET button)` |
| 6 | BOOT button | Hold **BOOT**, tap **RESET**, release BOOT | The LED stops blinking and the console goes quiet: the ROM bootloader is running. Tap RESET again and the test firmware comes back. |
| 7 | IMU on I2C | `i2cscan` | Only `0x6A` is found. The banner showed `WHO_AM_I = 0x70`. |
| 8 | IMU data | Lay the board flat, run `imu` | Accel about `0 0 1000` mg (±60), gyro within a few dps of 0, temperature near room temperature. Flip it upside down: Z reads about −1000. |
| 9 | IMU interrupt, INT1 → A0 | Tap the board near the IMU, double-tap it, give it a shake | Prints `tap`, `double-tap` and `wake`. Thresholds are `#define`s at the top of `firmware/src/main.c` if it is too eager or too deaf. |
| 10 | Every header GPIO (outputs, shorts) | Unplug anything else from the headers, run `walk`. Optionally follow along with an LED + 1 kΩ to GND on each pin as it is named. | Ends with `walk done: N pins, 0 faults`. Any `FAIL` names the pin and whether it looks shorted to GND, 3V3 or another pin. |
| 11 | Every header GPIO (inputs) | `mon`, then touch a jumper from 3V3 (J3.1) to each pin in turn | Each touch prints `mon: J1.x PAy=1`, then `=0` on release. B6/B7 sit at 1 (I2C pull-ups). |
| 12 | ADC | `adc`, then jumper A1 (J1.18) to 3V3 and run `adc` again | VDDA about 3300 mV. A1 reads about 3300 mV with the jumper. A0 reads about 0 (it has 10 kΩ to the IMU's INT1). |
| 13 | Standby + wake on A0 | `standby`, wait a second, then tap the board | The board restarts, and the banner says `woke from Standby`. RESET also wakes it. |
| 14 | USB-C, both orientations | Done in step 2 | LED on both ways. A USB data test needs firmware with USB support; this test firmware deliberately keeps USB off (D+ held low). |

Two pin groups are never walked:
- **J3.3/J3.4 (USART1):** the console runs over them, so working output already proves them.
- **J3.7/J3.8 (SWD):** flashing proves them. `walk all` includes them, but disables the debugger until the next reset.

Record anything odd, especially the crystal frequency, any `FAIL` line, and IMU readings that look wrong. Those are the open items in [`REVIEW.md`](REVIEW.md).

## Troubleshooting

| Symptom | Check |
|---|---|
| Programmer can't connect | Board powered from USB-C? GND wired? T_VCC to J3.1 (the probe reads the target voltage from it; 0 V there blocks the connection)? Try mode **Under reset**, or lower the SWD speed to 1 MHz. |
| Programs fine but the console is silent | Right COM port and 115200 baud? Press RESET. Check that the cyan wire goes to J3.4 and the magenta to J3.3. If they were swapped, swap them (harmless). |
| Banner says HSI / 64 MHz | Crystal Y1 or its 15 pF caps (C10/C11) are not oscillating. Check their soldering. The board still works on the internal oscillator, but USB needs the crystal. |
| `IMU: no ACK at 0x6A` | IMU solder joints (an LGA, inspect under magnification). Check that R7/R9 (I2C pull-ups) are fitted. Also check that nothing on J3.13/J3.14 (B6/B7) is pulling the bus low. |
| `walk` reports `FAIL ... follows ...` | Solder bridge between the two named pins, at the header or at the MCU |
| Green LED solid on, no console | The firmware hard-faulted. Re-flash, then press RESET. |

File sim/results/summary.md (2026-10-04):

# NickLink v1.3 SPICE results

Generated by `sim/run.sh` (ngspice 42 in Docker + analyze.py). Do not edit by hand.

## As-built v1.3 board (current tools/spec.py)

The rail in this table (R12 1 ohm, C12 4.7 µF 0402, R6 330 ohm) is the fitted board. Bench 12 rows that score VSYS against 6.0 V are the old TLV755 limit, not the fitted TLV76733DRVR (18 V). The fitted-part scores are in the second table: "U2 -> TLV76733" (J1.1 hot-plug **MARGIN**, long USB cables **PASS**). Peaks were not re-run.

| Test | Check | Result | Verdict |
|---|---|---|---|
| 1 Hot-plug | As built (bench 11): R12 1 ohm, C12 4.7u 0402, C4 4.7u; LDO IN peak <= 5.8 V, inrush <= 50 uC | LDO IN pk 5.38 V, VBUS pk 6.17 V, inrush 33 uC, LDO IN @4.40 V/500 mA 3.53 V | **PASS** |
| 1 Hot-plug | As built: 3V3 at 500 mA from USB 4.40 V (above the 250 mA thermal budget) | LDO IN 3.53 V vs 3.538 V needed (max dropout); 3V3 ~3.29 V | **MARGIN** |
| 1 Hot-plug | v1.3 original (no R12, C12 10u, C5 10u) - why R12 was added: peak +5V vs 6.0 V abs max | 6.13..11.42 V | **FAIL** |
| 1 Hot-plug | v1.3 original - inrush charge vs USB 50 uC | 63 uC (C12 + 3V3 caps via soft-start) | **FAIL** |
| 12 J1.1 hot-plug | Old TLV755 limit, not fitted: 5.0 / 5.5 V supply plugged onto J1.1 (leads 0.1-2 uH, F1 0.1 / 0.3 ohm); VSYS <= 6.0 V. Fitted part is the TLV76733 row in the second table (MARGIN) | VSYS pk 5.42..9.17 V (linear C12), up to 19.3 V (bias C12); 2 of 20 corners <= 6.0 V | **FAIL (against 6.0 V only)** |
| 12 J1.1 hot-plug | Old TLV755 limit, not fitted: USB hot-plug, 1.5-3 uH cables (2-4 m), 5.25 / 5.5 V; LDO IN <= 6.0 V. Fitted TLV76733 score for this peak is PASS (<= 12 V) | <= 2 uH at 5.25 V: 5.92 V; worst (3 uH, 5.5 V): 7.34 V | **MARGIN (against 6.0 V only)** |
| 2 LDO | Start-up: monotonic, overshoot < 3 % | 367 us to 90 %, overshoot 0.02 % | **PASS** |
| 2 LDO | Load steps 0/50/250 mA, 1 us edges: within 3.3 V +-3 %, settle < 100 us | worst deviation 31 mV, settle 28 us | **PASS** |
| 2 LDO | Stability: TI condition COUT_eff >= 0.47 uF, nominal 1..200 uF, ceramic ESR (vendor model has no loop, no phase margin) | COUT_eff 3.2 uF; C8 alone 0.60 uF | **PASS** |
| 3 Brown-out | Min VBUS for regulation at 250 mA (USB min 4.75 V, 4.40 V at a bus-powered hub) | VBUS >= 4.01 V (datasheet-max dropout + VF + 250 mA x R12) | **PASS** |
| 3 Brown-out | Window VDD < 2.0 V (spec min) before PDR (1.80..1.96 V) resets the MCU | VSYS 2.16 -> 1.96 V (200 mV of input sag, unprotected) | **MARGIN** |
| 3 Brown-out | Schottky D2 drop at 100 / 250 / 500 mA | 0.30 V / 0.34 V / 0.37 V | **PASS** |
| 4 NRST | Power-on: NRST to VIH 2.0 V after VDD = 2.0 V (RPU 30..50 k, C9 100 nF), budget 20 ms | <= 3.7 ms (on top of the chip's own 1..4.5 ms POR delay) | **PASS** |
| 4 NRST | RESET button: NRST < 0.8 V in < 1 us, held >= 300 ns; release time | release 3.7 ms | **PASS** |
| 4 NRST | Internal 20 us reset pulse pulls 100 nF below VIL (assumed 50 ohm driver) | yes | **PASS** |
| 4 NRST | BOOT0: 10 k pull-down, button to 3V3 | pressed 3.3 V / released 0 V, 0.33 mA while pressed | **PASS** |
| 5 LEDs | Red D1 with R3 1k5, all VF bins | 0.84..1.12 mA | **PASS** |
| 5 LEDs | Green D3 with R6 330 (as built): typ >= 1 mA, PC13 sink <= 3 mA at min VF | typ 1.32 mA, 0.95..1.79 mA over VF bins | **PASS** |
| 6 I2C | 400 kHz, 4.7 k, 20 pF: tr <= 300 ns | tr 80 ns, tf 1 ns | **PASS** |
| 6 I2C | 400 kHz, 4.7 k, 40 pF: tr <= 300 ns | tr 160 ns, tf 2 ns | **PASS** |
| 6 I2C | 400 kHz, 4.7 k, 100 pF: tr <= 300 ns | tr 398 ns, tf 4 ns | **FAIL** |
| 6 I2C | 100 kHz, 4.7 k, 20 pF: tr <= 1000 ns | tr 80 ns, tf 1 ns | **PASS** |
| 6 I2C | 100 kHz, 4.7 k, 40 pF: tr <= 1000 ns | tr 160 ns, tf 2 ns | **PASS** |
| 6 I2C | 100 kHz, 4.7 k, 100 pF: tr <= 1000 ns | tr 398 ns, tf 5 ns | **PASS** |
| 7 Crystal | AN2867 gain margin >= 5 | 73 (gm_crit 0.34 mA/V) | **PASS** |
| 7 Crystal | Load capacitance / pulling | CL 10.5..12.5 pF, -5..+19 ppm | **PASS** |
| 7 Crystal | Drive level <= 100 uW (worst-case ESR, swing unknown) | 55 uW at 2 Vpp, 149 uW at 3.3 Vpp; limit at 2.7 Vpp | **MARGIN** |
| 8 VDDA filter | Attenuation above 10 MHz; LC resonance peak | -67 dB @10 MHz, -64 dB @100 MHz; peak +17.1 dB @ 288 kHz | **MARGIN** |

## Fix studies and v1.3-original comparisons

| Test | Check | Result | Verdict |
|---|---|---|---|
| 1 Hot-plug | Fix option 1: +10 uF / 1 ohm ESR bulk on VBUS (tantalum/electrolytic) | +5V peak 7.75 V, inrush 115 uC | **FAIL** |
| 1 Hot-plug | Fix option 2: +22 uF / 0.5 ohm ESR bulk on VBUS | +5V peak 6.09 V, inrush 179 uC | **FAIL** |
| 1 Hot-plug | Fix option 3: +47 uF / 0.3 ohm ESR bulk on VBUS | +5V peak 5.27 V, inrush 316 uC | **PASS (peak) / FAIL (inrush)** |
| 1 Hot-plug | Fix option 4: +SMF5.0A TVS on VBUS | +5V peak 7.34 V, inrush 75 uC | **FAIL** |
| 1 Hot-plug | Fix option 5: 0.5 ohm series R (or PTC) between VBUS and D2 | +5V peak 5.51 V, inrush 58 uC | **PASS (peak) / MARGIN (inrush)** |
| 1 Hot-plug | Fix option 6: 1.0 ohm series R (or PTC) between VBUS and D2 | +5V peak 5.26 V, inrush 58 uC | **PASS (peak) / MARGIN (inrush)** |
| 1 Hot-plug | Fix option 7: 1.0 ohm series R + C12 and C5 reduced to 4.7 uF (inrush fix) | +5V peak 5.26 V, inrush 30 uC | **PASS** |
| 5 LEDs | Green D3 with R6 1k5 (v1.3 original, dim) | 0.35..0.52 mA (typ 0.43) | **MARGIN** |
| 5 LEDs | R6 = 220 ohm (centre of 1.5..2 mA typ): PC13 sink <= 3 mA at min VF | typ 1.67 mA, min-VF 2.36 mA, max-VF 1.17 mA | **PASS** |
| 8 VDDA filter | Fix option: 1 ohm in series with C7 | peak +2.8 dB, -44 dB @10 MHz | **PASS** |
| 9 Hot-plug fixes | A (F1 on header side, R 0.3 ohm; F1/Q1 carry no current with J1.1 open) | LDO IN pk 12.71 V, inrush 53 uC, drop@500mA 0.37 V, LDO IN 4.03 V @USB 4.40 V | **FAIL** |
| 9 Hot-plug fixes | B, F1 0.1 ohm between VBUS and D2 | LDO IN pk 11.38 V, inrush 52 uC, drop@500mA 0.42 V, LDO IN 3.98 V @USB 4.40 V | **FAIL** |
| 9 Hot-plug fixes | B, F1 0.3 ohm between VBUS and D2 | LDO IN pk 9.27 V, inrush 51 uC, drop@500mA 0.52 V, LDO IN 3.88 V @USB 4.40 V | **FAIL** |
| 9 Hot-plug fixes | B, F1 0.6 ohm between VBUS and D2 | LDO IN pk 6.65 V, inrush 50 uC, drop@500mA 0.67 V, LDO IN 3.73 V @USB 4.40 V | **FAIL** |
| 9 Hot-plug fixes | C, A + 0.5 ohm series R between VBUS and D2 | LDO IN pk 7.35 V, inrush 50 uC, drop@500mA 0.62 V, LDO IN 3.78 V @USB 4.40 V | **FAIL** |
| 9 Hot-plug fixes | C, A + 1.0 ohm series R between VBUS and D2 | LDO IN pk 5.38 V, inrush 48 uC, drop@500mA 0.87 V, LDO IN 3.53 V @USB 4.40 V | **FAIL** |
| 9 Hot-plug fixes | D, A with C12 = 2.2 uF 0402 | LDO IN pk 11.76 V, inrush 45 uC, drop@500mA 0.37 V, LDO IN 4.03 V @USB 4.40 V | **FAIL** |
| 9 Hot-plug fixes | E, C12 4.7 uF 0603 + 0.75 ohm series R + C5 4.7 uF 0603 | LDO IN pk 5.45 V, inrush 37 uC, drop@500mA 0.75 V, LDO IN 3.65 V @USB 4.40 V | **PASS** |
| 9 Hot-plug fixes | E', C12 4.7 uF 0402 + 0.75 ohm series R + C5 4.7 uF 0603 | LDO IN pk 5.95 V, inrush 35 uC, drop@500mA 0.75 V, LDO IN 3.65 V @USB 4.40 V | **FAIL** |
| 9 Hot-plug fixes | E'', C12 10 uF 0603 (v1.3 original) + 0.5 ohm series R + C5 4.7 uF 0603 | LDO IN pk 5.49 V, inrush 54 uC, drop@500mA 0.62 V, LDO IN 3.78 V @USB 4.40 V | **FAIL** |
| 10 RC snubber | Rs 0.5 ohm, no Cd | VSYS pk 7.59 V, inrush 50 uC, Rs 16.6 W pk / 36 uJ | **FAIL** |
| 10 RC snubber | Rs 0.5 ohm, Cd 100n | VSYS pk 7.65 V, inrush 51 uC, Rs 17.1 W pk / 36 uJ | **FAIL** |
| 10 RC snubber | Rs 0.5 ohm, Cd 1u | VSYS pk 8.15 V, inrush 54 uC, Rs 21.5 W pk / 39 uJ | **FAIL** |
| 10 RC snubber | Rs 1 ohm, no Cd | VSYS pk 5.74 V, inrush 48 uC, Rs 15.2 W pk / 41 uJ | **PASS** |
| 10 RC snubber | Rs 1 ohm, Cd 100n | VSYS pk 5.75 V, inrush 49 uC, Rs 17.0 W pk / 42 uJ | **PASS** |
| 10 RC snubber | Rs 1 ohm, Cd 1u | VSYS pk 6.21 V, inrush 53 uC, Rs 26.9 W pk / 47 uJ | **FAIL** |
| 10 RC snubber | Rs 2.2 ohm, no Cd | VSYS pk 5.67 V, inrush 48 uC, Rs 13.6 W pk / 45 uJ | **PASS** |
| 10 RC snubber | Rs 2.2 ohm, Cd 100n | VSYS pk 6.39 V, inrush 49 uC, Rs 16.9 W pk / 46 uJ | **FAIL** |
| 10 RC snubber | Rs 2.2 ohm, Cd 1u | VSYS pk 8.36 V, inrush 53 uC, Rs 27.8 W pk / 52 uJ | **FAIL** |
| 10 RC snubber | Rs 1 ohm, Cd 100n, C5 4.7u | VSYS pk 5.75 V, inrush 35 uC, Rs 17.0 W pk / 42 uJ | **PASS** |
| 11 Hot-plug v1.3 current | R12 = 1 ohm (as built): LDO IN peak <= 5.8 V, inrush <= 50 uC, 500 mA @4.40 V | LDO IN pk 5.38 V, VBUS pk 6.17 V, inrush 33 uC, LDO IN @4.40 V/500 mA 3.53 V | **PASS (hot-plug) / FAIL (500 mA @4.40 V)** |
| 11 Hot-plug v1.3 current | R12 = 1.5 ohm: LDO IN peak <= 5.8 V, inrush <= 50 uC, 500 mA @4.40 V | LDO IN pk 5.26 V, VBUS pk 5.74 V, inrush 33 uC, LDO IN @4.40 V/500 mA 3.28 V | **PASS (hot-plug) / FAIL (500 mA @4.40 V)** |
| 11 Hot-plug v1.3 current | R12 = 2.2 ohm: LDO IN peak <= 5.8 V, inrush <= 50 uC, 500 mA @4.40 V | LDO IN pk 5.25 V, VBUS pk 6.21 V, inrush 33 uC, LDO IN @4.40 V/500 mA 2.93 V | **PASS (hot-plug) / FAIL (500 mA @4.40 V)** |
| 12 J1.1 hot-plug | U2 -> TLV76733 (18 V) + C12 16 V: J1.1 hot-plug peak <= 12 V (Q1 VGS) | linear C12 max 9.17 V; bias C12 max 19.32 V (5 of 20 corners > 12 V, all 1-2 uH with F1 at 0.1-0.3 ohm) | **MARGIN** |
| 12 J1.1 hot-plug | U2 -> TLV76733: USB hot-plug with 1.5-3 uH cables <= 12 V | worst 7.34 V | **PASS** |

## 1 USB hot-plug (hotplug_variants.png, hotplug_base.png)

| Variant | worst +5V peak | worst VBUS peak | peak current | inrush charge | verdict |
|---|---|---|---|---|---|
| 0: v1.3 original (C13 100n, C12 10u, C5 10u, no R12) | 11.42 V (L 1.0 uH, R 0.1 ohm, BV 9) | 11.77 V | 14.07 A | 63 uC | FAIL |
| 1: +10 uF / 1 ohm ESR bulk on VBUS (tantalum/electrolytic) | 7.75 V (L 1.0 uH, R 0.1 ohm, BV 9) | 8.09 V | 15.23 A | 115 uC | FAIL |
| 2: +22 uF / 0.5 ohm ESR bulk on VBUS | 6.09 V (L 1.0 uH, R 0.1 ohm, BV 9) | 6.42 V | 16.39 A | 179 uC | FAIL |
| 3: +47 uF / 0.3 ohm ESR bulk on VBUS | 5.27 V (L 1.0 uH, R 0.1 ohm, BV 6) | 5.50 V | 18.00 A | 316 uC | PASS |
| 4: +SMF5.0A TVS on VBUS | 7.34 V (L 1.0 uH, R 0.1 ohm, BV 9) | 7.67 V | 14.07 A | 75 uC | FAIL |
| 5: 0.5 ohm series R (or PTC) between VBUS and D2 | 5.51 V (L 1.0 uH, R 0.1 ohm, BV 6) | 6.28 V | 6.47 A | 58 uC | PASS |
| 6: 1.0 ohm series R (or PTC) between VBUS and D2 | 5.26 V (L 1.0 uH, R 0.1 ohm, BV 6) | 5.63 V | 4.13 A | 58 uC | PASS |
| 7: 1.0 ohm series R + C12 and C5 reduced to 4.7 uF (inrush fix) | 5.26 V (L 1.0 uH, R 0.1 ohm, BV 6) | 6.03 V | 3.98 A | 30 uC | PASS |

## 2 LDO (ldo_steps.png)

- VBUS 5.0 V: start-up 367 us to 90 % (datasheet tSTR 550 us typ), overshoot 0.02 %, monotonic True, Vout 3.3148 V
-   0->50 mA: min 3.3072 V, max 3.3148 V, settles (10 mV) in 0 us
-   50->250 mA: min 3.2854 V, max 3.3126 V, settles (10 mV) in 28 us
-   250->50 mA: min 3.3043 V, max 3.3314 V, settles (10 mV) in 28 us
-   50->0 mA: min 3.3126 V, max 3.3197 V, settles (10 mV) in 0 us
- Model check vs datasheet Fig. 5-8 (1->500 mA, 1 uF): dip -64 mV / overshoot +41 mV (datasheet ~-60 / +70 mV)
- VBUS 4.4 V: start-up 368 us to 90 % (datasheet tSTR 550 us typ), overshoot 0.02 %, monotonic True, Vout 3.3145 V
-   0->50 mA: min 3.3069 V, max 3.3145 V, settles (10 mV) in 0 us
-   50->250 mA: min 3.2851 V, max 3.3123 V, settles (10 mV) in 28 us
-   250->50 mA: min 3.3040 V, max 3.3311 V, settles (10 mV) in 28 us
-   50->0 mA: min 3.3123 V, max 3.3194 V, settles (10 mV) in 0 us
- Effective COUT at 3.3 V: 3.20 uF (6.2 uF nominal, +1.08 uF VDDA behind FB1); C8 alone at OUT pin: 0.60 uF

## 3 Brown-out (brownout.png)

- D2 VF (fitted typ model): 100 mA 0.300 V, 250 mA 0.336 V, 500 mA 0.370 V (datasheet typ ~0.30 / 0.37 V at 100 / 500 mA)
- Load 50 mA: 3V3 < 3.2 V at +5V = 3.35 V, 3.0 V at +5V = 3.15 V, 2.0 V at +5V = 2.15 V, 1.88 V at +5V = 2.03 V, 1.8 V at +5V = 1.95 V; VBUS = VSYS + VF + I*R12 = VSYS + 0.33 V
-    datasheet-max estimate: regulation lost below VSYS = 3.33 V (VBUS 3.65 V); sim (fixed 150 mV model) 3.35 V
- Load 250 mA: 3V3 < 3.2 V at +5V = 3.36 V, 3.0 V at +5V = 3.16 V, 2.0 V at +5V = 2.16 V, 1.88 V at +5V = 2.04 V, 1.8 V at +5V = 1.96 V; VBUS = VSYS + VF + I*R12 = VSYS + 0.59 V
-    datasheet-max estimate: regulation lost below VSYS = 3.43 V (VBUS 4.01 V); sim (fixed 150 mV model) 3.36 V

## 4 NRST / BOOT0 (nrst.png)

- RPU 30k: VDD 2.0 V at 0.25 ms; NRST reaches 2.0 V 2.18 ms later (internal POR+tRSTTEMPO 1..4.5 ms after 0.24 ms); button: < 0.8 V in 51 ns, release to 2.0 V in 2.22 ms; 20 us internal pulse: NRST min 0.02 V, < 0.8 V for 24.1 us; BOOT0 pressed 3.31 V / released 0.000 V
- RPU 40k: VDD 2.0 V at 0.25 ms; NRST reaches 2.0 V 2.92 ms later (internal POR+tRSTTEMPO 1..4.5 ms after 0.24 ms); button: < 0.8 V in 51 ns, release to 2.0 V in 2.96 ms; 20 us internal pulse: NRST min 0.02 V, < 0.8 V for 24.1 us; BOOT0 pressed 3.31 V / released 0.000 V
- RPU 50k: VDD 2.0 V at 0.25 ms; NRST reaches 2.0 V 3.66 ms later (internal POR+tRSTTEMPO 1..4.5 ms after 0.24 ms); button: < 0.8 V in 51 ns, release to 2.0 V in 3.70 ms; 20 us internal pulse: NRST min 0.02 V, < 0.8 V for 24.1 us; BOOT0 pressed 3.31 V / released 0.000 V

## 5 LEDs (led_r6.png) - as built R6 = 330 ohm

- D1 red, R3 1k5: 1.12 / 1.00 / 0.84 mA (min-VF / typ / max-VF bin)
- D3 green, R6 330 (as built): 1.79 / 1.32 / 0.95 mA; R6 1k5 (v1.3 original): 0.52 / 0.43 / 0.35 mA

| R6 | green min-VF bin | typ | max-VF bin |
|---|---|---|---|
| 100 | 3.65 mA | 2.43 mA | 1.61 mA |
| 120 | 3.34 mA | 2.25 mA | 1.51 mA |
| 150 | 2.97 mA | 2.04 mA | 1.39 mA |
| 180 | 2.67 mA | 1.86 mA | 1.28 mA |
| 200 | 2.51 mA | 1.76 mA | 1.22 mA |
| 220 | 2.36 mA | 1.67 mA | 1.17 mA |
| 240 | 2.23 mA | 1.59 mA | 1.12 mA |
| 270 | 2.06 mA | 1.49 mA | 1.06 mA |
| 300 | 1.92 mA | 1.40 mA | 1.00 mA |
| 330 | 1.79 mA | 1.32 mA | 0.95 mA |
| 390 | 1.58 mA | 1.18 mA | 0.86 mA |
| 470 | 1.37 mA | 1.04 mA | 0.77 mA |
| 560 | 1.20 mA | 0.92 mA | 0.69 mA |
| 680 | 1.02 mA | 0.80 mA | 0.61 mA |
| 820 | 0.88 mA | 0.70 mA | 0.54 mA |
| 1000 | 0.74 mA | 0.60 mA | 0.47 mA |
| 1200 | 0.63 mA | 0.52 mA | 0.41 mA |
| 1500 | 0.52 mA | 0.43 mA | 0.35 mA |

## 6 I2C (i2c.png)

| f | Cb | tr 30-70 % | tf 70-30 % | VOL | V at end of tHIGH | spec tr |
|---|---|---|---|---|---|---|
| 400 kHz | 20 pF | 80 ns | 0.8 ns | 0.035 V | 3.30 V | 300 ns |
| 400 kHz | 40 pF | 160 ns | 2.2 ns | 0.035 V | 3.26 V | 300 ns |
| 400 kHz | 100 pF | 398 ns | 4.5 ns | 0.035 V | 2.74 V | 300 ns |
| 100 kHz | 20 pF | 80 ns | 0.8 ns | 0.035 V | 3.30 V | 1000 ns |
| 100 kHz | 40 pF | 160 ns | 2.2 ns | 0.035 V | 3.30 V | 1000 ns |
| 100 kHz | 100 pF | 398 ns | 5.3 ns | 0.035 V | 3.30 V | 1000 ns |

- Max pull-up for 300 ns at Cb: R <= 300 ns / (0.847 Cb) -> 100 pF: 3.54 k, 200 pF: 1.77 k; min pull-up (3 mA, VOL 0.4 V): 967 ohm

## 7 Crystal (analytic, xtal.py)

- gm_crit = 0.341 mA/V; gain margin 73 (ESR 150 ohm), 61 (180 ohm); AN2867 needs >= 5
- CL actual = 15p series + Cs(3..5 pF) = 10.5..12.5 pF vs 12 pF -> +19..-5 ppm (USB FS needs +-2500 ppm)
- Drive level at ESR 150 ohm: 55 uW at 2 Vpp, 149 uW at 3.3 Vpp (rail-to-rail) vs 100 uW max; 100 uW is reached at 2.70 Vpp on OSC_IN. Rext start value 1/(2 pi f C) = 1326 ohm

## 8 VDDA filter (vdda.png)

- As built: resonance 288 kHz, +17.1 dB; 0.1 MHz 1.1 dB, 1 MHz -21.0 dB, 10 MHz -66.8 dB, 100 MHz -63.8 dB
- +1 ohm in series with C7: peak +2.8 dB @ 257 kHz; 0.1 MHz 0.8 dB, 1 MHz -9.3 dB, 10 MHz -44.0 dB, 100 MHz -58.7 dB

## 9 Hot-plug fix candidates (hotplug_fixes.png)

- Inrush 'full-bias' adds the charge the linear 3V3 caps undercount (10.5 uC with C5 10 uF, 5.9 uC with 4.7 uF). Regulation check: LDO IN = 4.40 V - drop(500 mA) >= 3.3 V + 238 mV (TLV755 max dropout). VF from the fitted typ 1N5819WS model (25 C). VSYS is the LDO IN net.

| Variant | worst VSYS = LDO IN peak | worst VBUS peak | I pk | inrush sim / full-bias | drop 250 / 500 mA | LDO IN @500 mA, USB 4.40 V | verdict |
|---|---|---|---|---|---|---|---|
| 0: A (F1 on header side, R 0.3 ohm; F1/Q1 carry no current with J1.1 open) | 12.71 V | 13.03 V | 10.6 A | 42 / 53 uC | 0.34 / 0.37 V | 4.03 V (regulates) | FAIL |
| 1: B, F1 0.1 ohm between VBUS and D2 | 11.38 V | 11.74 V | 9.3 A | 41 / 52 uC | 0.36 / 0.42 V | 3.98 V (regulates) | FAIL |
| 2: B, F1 0.3 ohm between VBUS and D2 | 9.27 V | 9.74 V | 7.2 A | 40 / 51 uC | 0.41 / 0.52 V | 3.88 V (regulates) | FAIL |
| 3: B, F1 0.6 ohm between VBUS and D2 | 6.65 V | 7.38 V | 5.3 A | 39 / 50 uC | 0.49 / 0.67 V | 3.73 V (regulates) | FAIL |
| 4: C, A + 0.5 ohm series R between VBUS and D2 | 7.35 V | 8.00 V | 5.9 A | 39 / 50 uC | 0.46 / 0.62 V | 3.78 V (regulates) | FAIL |
| 5: C, A + 1.0 ohm series R between VBUS and D2 | 5.38 V | 6.17 V | 4.0 A | 38 / 48 uC | 0.59 / 0.87 V | 3.53 V (DROPOUT) | FAIL |
| 6: D, A with C12 = 2.2 uF 0402 | 11.76 V | 12.07 V | 8.2 A | 34 / 45 uC | 0.34 / 0.37 V | 4.03 V (regulates) | FAIL |
| 7: E, C12 4.7 uF 0603 + 0.75 ohm series R + C5 4.7 uF 0603 | 5.45 V | 6.30 V | 4.7 A | 31 / 37 uC | 0.52 / 0.75 V | 3.65 V (regulates) | PASS |
| 8: E', C12 4.7 uF 0402 + 0.75 ohm series R + C5 4.7 uF 0603 | 5.95 V | 6.75 V | 4.7 A | 29 / 35 uC | 0.52 / 0.75 V | 3.65 V (regulates) | FAIL |
| 9: E'', C12 10 uF 0603 (v1.3 original) + 0.5 ohm series R + C5 4.7 uF 0603 | 5.49 V | 6.26 V | 6.4 A | 48 / 54 uC | 0.46 / 0.62 V | 3.78 V (regulates) | FAIL |

- Smallest passing option (order A, D, B, C 0.5, C 1.0, then E candidates; B must pass at every PTC R): **E (C12 4.7u 0603 + 0.75 ohm + C5 4.7u)**
- Series-R power at 500 mA (minimum package rating): 0.5 ohm 125 mW -> 0805 (0.125 W, no margin; 1206 preferred), 0.75 ohm 188 mW -> 1206 (0.25 W), 1.0 ohm 250 mW -> 1206 at its rating (1210/2010 0.5 W preferred).

## 10 C12 as RC snubber (snubber.png)

- Hot-plug: worst over the 8 corners of 01. Inrush = sim + the charge the linear 3V3 caps undercount. Rs power: peak instantaneous, energy per plug-in, mean over the first 50 us (steady-state Rs power is ~0: no DC flows). Load step: 1 uH / 0.1 ohm cable, 5.0 V, 0->50->250->50->0 mA. CIN at 5 V bias: direct = Cd, snubbed = C12 behind Rs.

| Variant | VSYS = LDO IN peak | inrush | Rs P peak | Rs energy | Rs mean P (50 us) | 3V3 min / max on steps | VSYS p-p after 250 mA step | CIN direct / snubbed (eff. @5 V) | verdict |
|---|---|---|---|---|---|---|---|---|---|
| 0: Rs 0.5 ohm, no Cd | 7.59 V | 50 uC | 16.6 W | 36 uJ | 713 mW | 3.287 / 3.330 V | 119 mV | 0.00 / 1.31 uF | FAIL |
| 1: Rs 0.5 ohm, Cd 100n | 7.65 V | 51 uC | 17.1 W | 36 uJ | 721 mW | 3.287 / 3.330 V | 120 mV | 0.06 / 1.31 uF | FAIL |
| 2: Rs 0.5 ohm, Cd 1u | 8.15 V | 54 uC | 21.5 W | 39 uJ | 778 mW | 3.287 / 3.330 V | 121 mV | 0.39 / 1.31 uF | FAIL |
| 3: Rs 1 ohm, no Cd | 5.74 V | 48 uC | 15.2 W | 41 uJ | 824 mW | 3.287 / 3.330 V | 109 mV | 0.00 / 1.31 uF | PASS |
| 4: Rs 1 ohm, Cd 100n | 5.75 V | 49 uC | 17.0 W | 42 uJ | 838 mW | 3.287 / 3.330 V | 110 mV | 0.06 / 1.31 uF | PASS |
| 5: Rs 1 ohm, Cd 1u | 6.21 V | 53 uC | 26.9 W | 47 uJ | 940 mW | 3.287 / 3.330 V | 114 mV | 0.39 / 1.31 uF | FAIL |
| 6: Rs 2.2 ohm, no Cd | 5.67 V | 48 uC | 13.6 W | 45 uJ | 898 mW | 3.287 / 3.330 V | 103 mV | 0.00 / 1.31 uF | PASS |
| 7: Rs 2.2 ohm, Cd 100n | 6.39 V | 49 uC | 16.9 W | 46 uJ | 916 mW | 3.287 / 3.330 V | 106 mV | 0.06 / 1.31 uF | FAIL |
| 8: Rs 2.2 ohm, Cd 1u | 8.36 V | 53 uC | 27.8 W | 52 uJ | 1038 mW | 3.287 / 3.330 V | 117 mV | 0.39 / 1.31 uF | FAIL |
| 9: Rs 1 ohm, Cd 100n, C5 4.7u | 5.75 V | 35 uC | 17.0 W | 42 uJ | 838 mW | 3.286 / 3.331 V | 117 mV | 0.06 / 1.31 uF | PASS |
| 10: reference: C12 4.7u 0402 direct on VSYS, no Rs (load step only) | - | - | - | - | - | 3.287 / 3.330 V | 143 mV | 1.31 / - uF | - |

- Passing: Rs 1 ohm, no Cd; Rs 1 ohm, Cd 100n; Rs 2.2 ohm, no Cd; Rs 1 ohm, Cd 100n, C5 4.7u. Best: **Rs 1 ohm, Cd 100n, C5 4.7u**
- Rs sizing for the best option: 17.0 W peak, 42 uJ per plug-in, equivalent rectangular pulse 2.5 us (E / Ppk). The 0402's 62.5 mW continuous rating is irrelevant (no DC); check the vendor's single-pulse curve at that duration, or use an anti-surge/pulse-rated 0603/0805 thick-film part.

## 11 Hot-plug, current spec.py power path (R12 + C12 4.7u 0402, no C5)

- Current spec.py path: VBUS -> R12 -> D2 -> VSYS (C12 4.7u 0402) ; 3V3 bank C4 4.7u + C8 + 100 nF (no C5). Inrush = sim + 6.5 uC the linear 3V3 caps undercount. LDO IN = Vsrc - I*R12 - VF(I) (typ VF, 25 C); regulates if >= 3.3 V + 0.476 ohm * I (TLV755 max dropout).

| R12 | LDO IN peak | VBUS peak | I pk | inrush | drop 250 / 500 mA | LDO IN @4.40 V: 250 / 500 mA | LDO IN @4.75 V: 250 / 500 mA | R12 P @300 / 500 mA | verdict |
|---|---|---|---|---|---|---|---|---|---|
| 1 ohm (as built) | 5.38 V | 6.17 V | 4.0 A | 33 uC | 0.59 / 0.87 V | 3.81 / 3.53 (DROPOUT) V | 4.16 / 3.88 V | 90 / 250 mW | PASS (hot-plug) / FAIL (500 mA @4.40 V) |
| 1.5 ohm | 5.26 V | 5.74 V | 3.1 A | 33 uC | 0.71 / 1.12 V | 3.69 / 3.28 (DROPOUT) V | 4.04 / 3.63 V | 135 / 375 mW | PASS (hot-plug) / FAIL (500 mA @4.40 V) |
| 2.2 ohm | 5.25 V | 6.21 V | 2.8 A | 33 uC | 0.89 / 1.47 V | 3.51 / 2.93 (DROPOUT) V | 3.86 / 3.28 (DROPOUT) V | 198 / 550 mW | PASS (hot-plug) / FAIL (500 mA @4.40 V) |

## 12 Hot-plug into J1.1 and long USB cables (U2 passive)

- J1.1 hot-plug, USB unplugged: stiff supply stepped onto J1.1 through leads L/R, then Q1 -> F1 -> VSYS (C12 4.7u 0402 + U2 IN/EN). Peak = max(VSYS, 5V_F). Bias = sim/ C12 fit (V0 3.1, extrapolated above 10 V); linear = 1.3 uF fixed. Limits: TLV755 VIN/EN 6.0 V (old part, not fitted); fitted TLV76733DRVR: Q1 VGS +-12 V (= -V(5V_F)), C12/F1 16 V. The 6.0 V column is not the current board.

| Supply | Leads L / R | F1 | Peak, bias C12 | Peak, linear 1.3 uF | TLV755 6.0 V (not fitted) | Fitted TLV76733 (12 V gate) |
|---|---|---|---|---|---|---|
| 5 V | 0.1 uH / 0.03 ohm | 0.1 ohm | 7.06 V | 6.37 V | FAIL | PASS |
| 5 V | 0.1 uH / 0.03 ohm | 0.3 ohm | 5.18 V | 5.42 V | PASS | PASS |
| 5 V | 0.25 uH / 0.05 ohm | 0.1 ohm | 8.94 V | 7.00 V | FAIL | PASS |
| 5 V | 0.25 uH / 0.05 ohm | 0.3 ohm | 6.00 V | 6.05 V | FAIL | PASS |
| 5 V | 0.5 uH / 0.1 ohm | 0.1 ohm | 9.79 V | 7.26 V | FAIL | PASS |
| 5 V | 0.5 uH / 0.1 ohm | 0.3 ohm | 6.86 V | 6.43 V | FAIL | PASS |
| 5 V | 1 uH / 0.1 ohm | 0.1 ohm | 12.40 V | 7.83 V | FAIL | FAIL |
| 5 V | 1 uH / 0.1 ohm | 0.3 ohm | 8.73 V | 7.06 V | FAIL | PASS |
| 5 V | 2 uH / 0.1 ohm | 0.1 ohm | 15.32 V | 8.32 V | FAIL | FAIL |
| 5 V | 2 uH / 0.1 ohm | 0.3 ohm | 11.21 V | 7.65 V | FAIL | PASS |
| 5.5 V | 0.1 uH / 0.03 ohm | 0.1 ohm | 8.35 V | 7.05 V | FAIL | PASS |
| 5.5 V | 0.1 uH / 0.03 ohm | 0.3 ohm | 5.78 V | 5.97 V | PASS | PASS |
| 5.5 V | 0.25 uH / 0.05 ohm | 0.1 ohm | 10.84 V | 7.72 V | FAIL | PASS |
| 5.5 V | 0.25 uH / 0.05 ohm | 0.3 ohm | 6.87 V | 6.66 V | FAIL | PASS |
| 5.5 V | 0.5 uH / 0.1 ohm | 0.1 ohm | 11.94 V | 8.00 V | FAIL | PASS |
| 5.5 V | 0.5 uH / 0.1 ohm | 0.3 ohm | 7.97 V | 7.08 V | FAIL | PASS |
| 5.5 V | 1 uH / 0.1 ohm | 0.1 ohm | 15.37 V | 8.64 V | FAIL | FAIL |
| 5.5 V | 1 uH / 0.1 ohm | 0.3 ohm | 10.42 V | 7.78 V | FAIL | PASS |
| 5.5 V | 2 uH / 0.1 ohm | 0.1 ohm | 19.32 V | 9.17 V | FAIL | FAIL |
| 5.5 V | 2 uH / 0.1 ohm | 0.3 ohm | 13.72 V | 8.42 V | FAIL | FAIL |

- 
- USB hot-plug with long cables (U3 BV 6 / 9 V, worst of the two), bias-dependent C12, J1.1 open:

| VBUS source | Cable L / R | LDO IN peak | TLV755 6.0 V (not fitted) | Fitted TLV76733 (12 V gate) |
|---|---|---|---|---|
| 5.25 V | 1.5 uH / 0.1 ohm | 5.47 V | PASS | PASS |
| 5.25 V | 1.5 uH / 0.25 ohm | 5.21 V | PASS | PASS |
| 5.25 V | 2 uH / 0.1 ohm | 5.92 V | PASS | PASS |
| 5.25 V | 2 uH / 0.25 ohm | 5.53 V | PASS | PASS |
| 5.25 V | 3 uH / 0.1 ohm | 6.78 V | FAIL | PASS |
| 5.25 V | 3 uH / 0.25 ohm | 6.23 V | FAIL | PASS |
| 5.5 V | 1.5 uH / 0.1 ohm | 5.85 V | PASS | PASS |
| 5.5 V | 1.5 uH / 0.25 ohm | 5.54 V | PASS | PASS |
| 5.5 V | 2 uH / 0.1 ohm | 6.37 V | FAIL | PASS |
| 5.5 V | 2 uH / 0.25 ohm | 5.92 V | PASS | PASS |
| 5.5 V | 3 uH / 0.1 ohm | 7.34 V | FAIL | PASS |
| 5.5 V | 3 uH / 0.25 ohm | 6.72 V | FAIL | PASS |
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

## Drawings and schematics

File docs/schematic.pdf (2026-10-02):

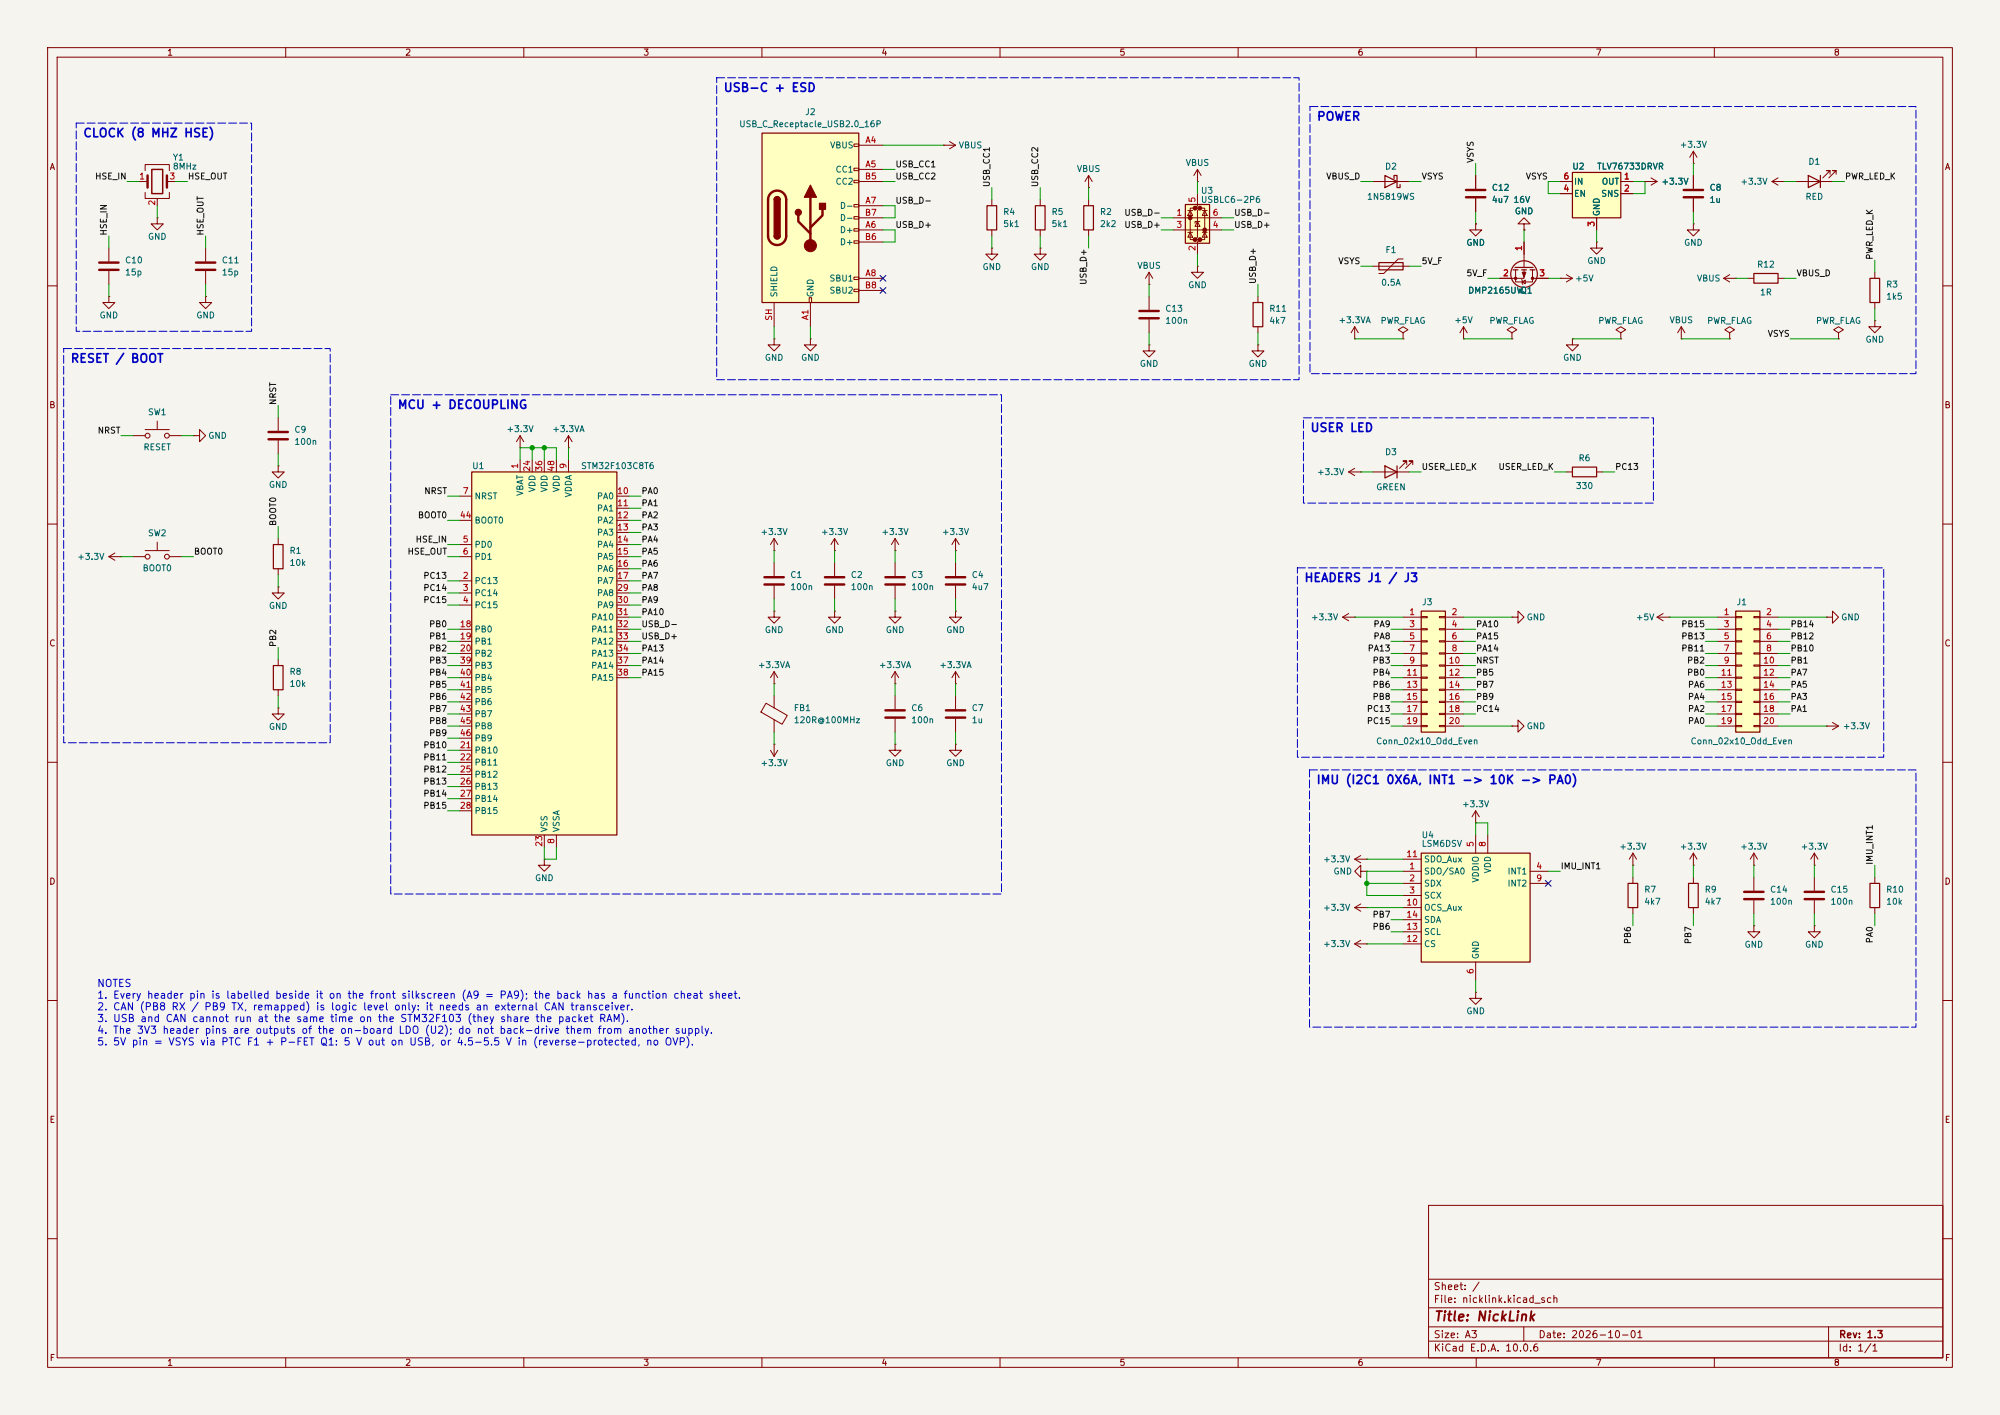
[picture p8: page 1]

NOTES
1. Every header pin is labelled beside it on the front silkscreen (A9 = PA9); the back has a function cheat sheet.
2. CAN (PB8 RX / PB9 TX, remapped) is logic level only: it needs an external CAN transceiver.
3. USB and CAN cannot run at the same time on the STM32F103 (they share the packet RAM).
4. The 3V3 header pins are outputs of the on-board LDO (U2); do not back-drive them from another supply.
5. 5V pin = VSYS via PTC F1 + P-FET Q1: 5 V out on USB, or 4.5-5.5 V in (reverse-protected, no OVP).

Size: A3 | Rev: 1.3 | F Date: 2026-10-01
KiCad E.D.A. 10.0.6 | Id: 1/1

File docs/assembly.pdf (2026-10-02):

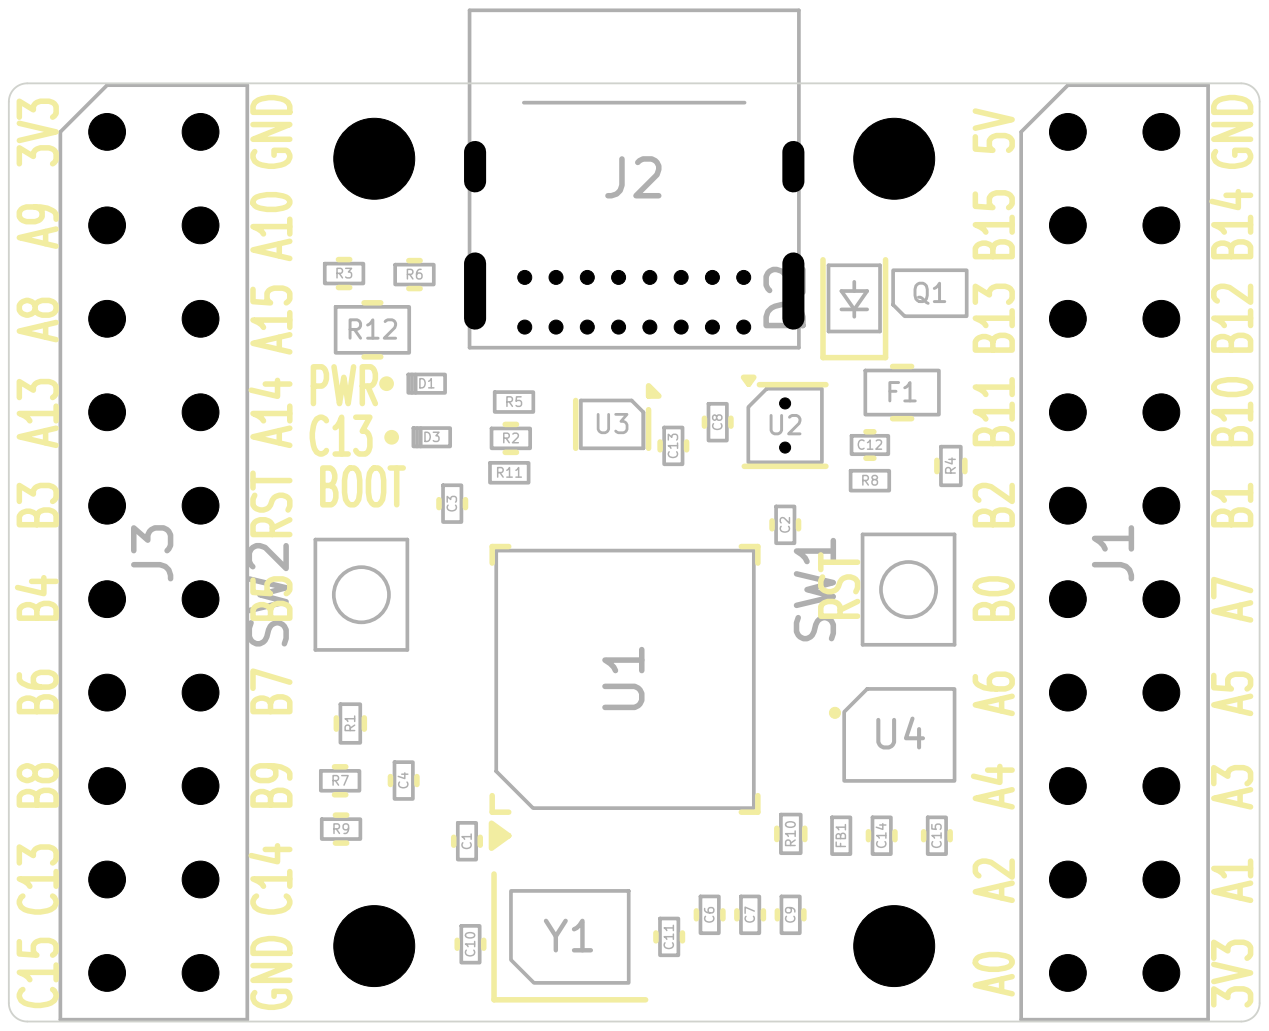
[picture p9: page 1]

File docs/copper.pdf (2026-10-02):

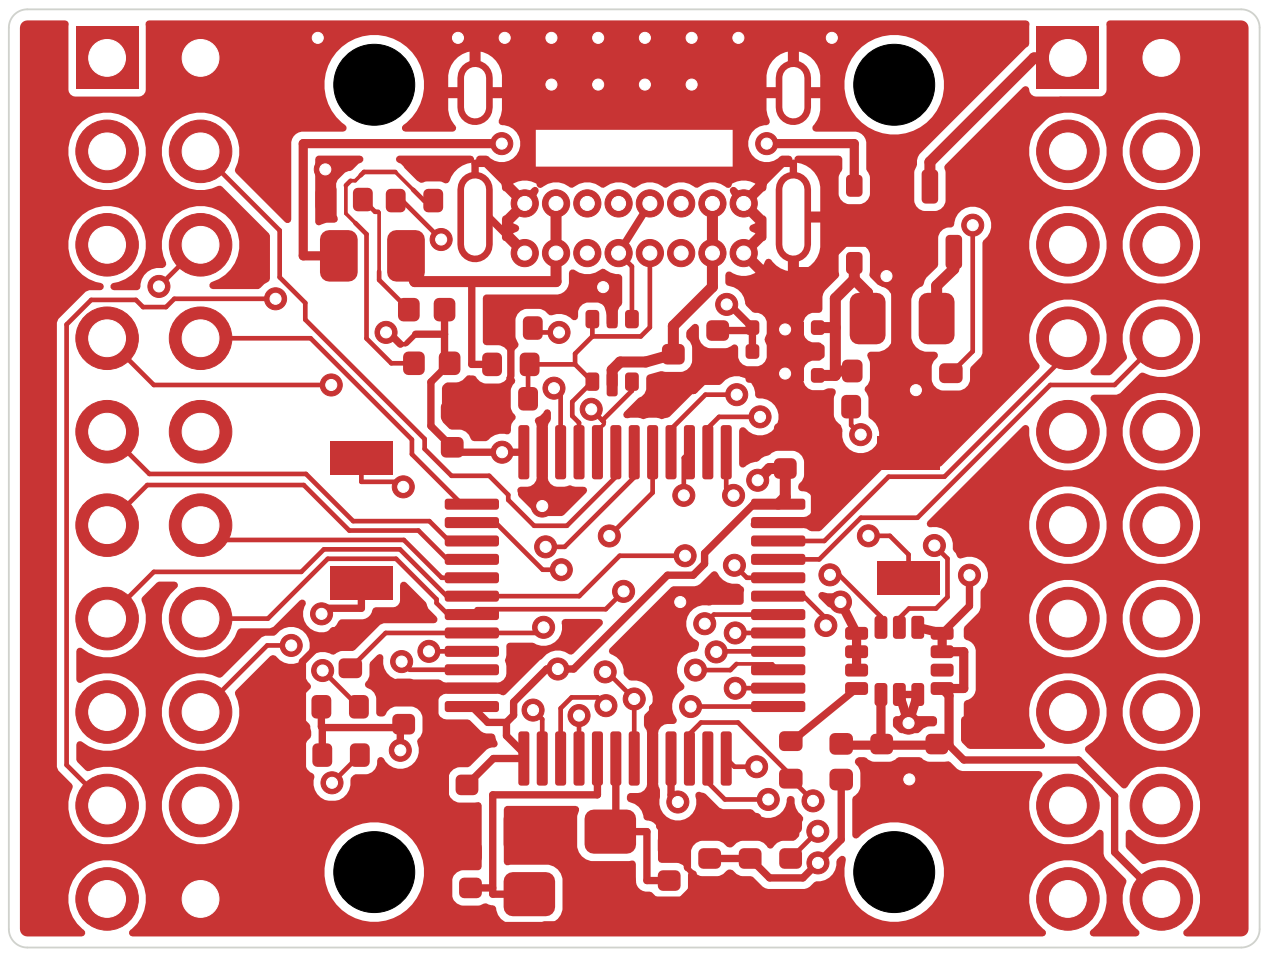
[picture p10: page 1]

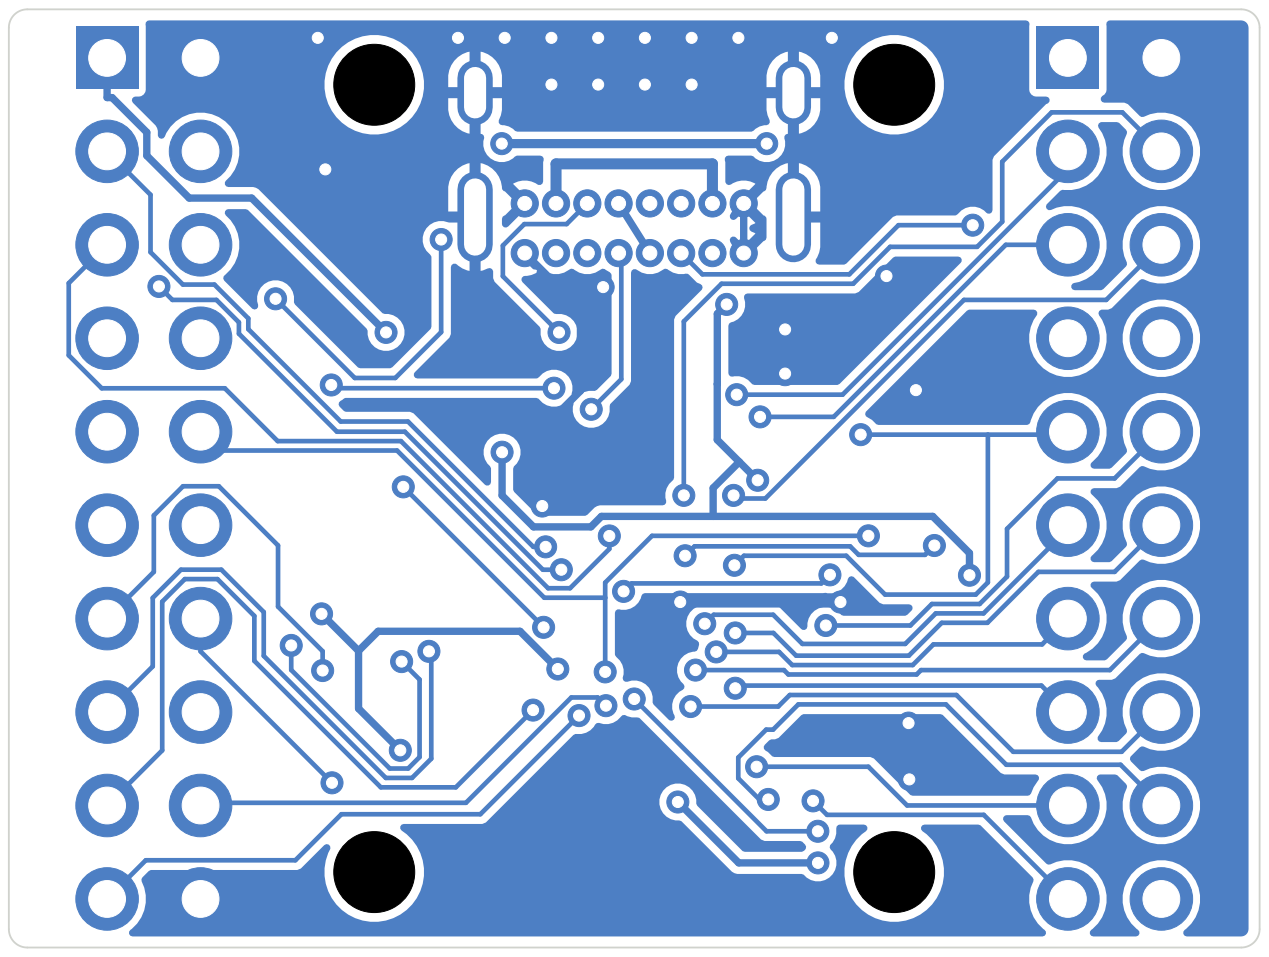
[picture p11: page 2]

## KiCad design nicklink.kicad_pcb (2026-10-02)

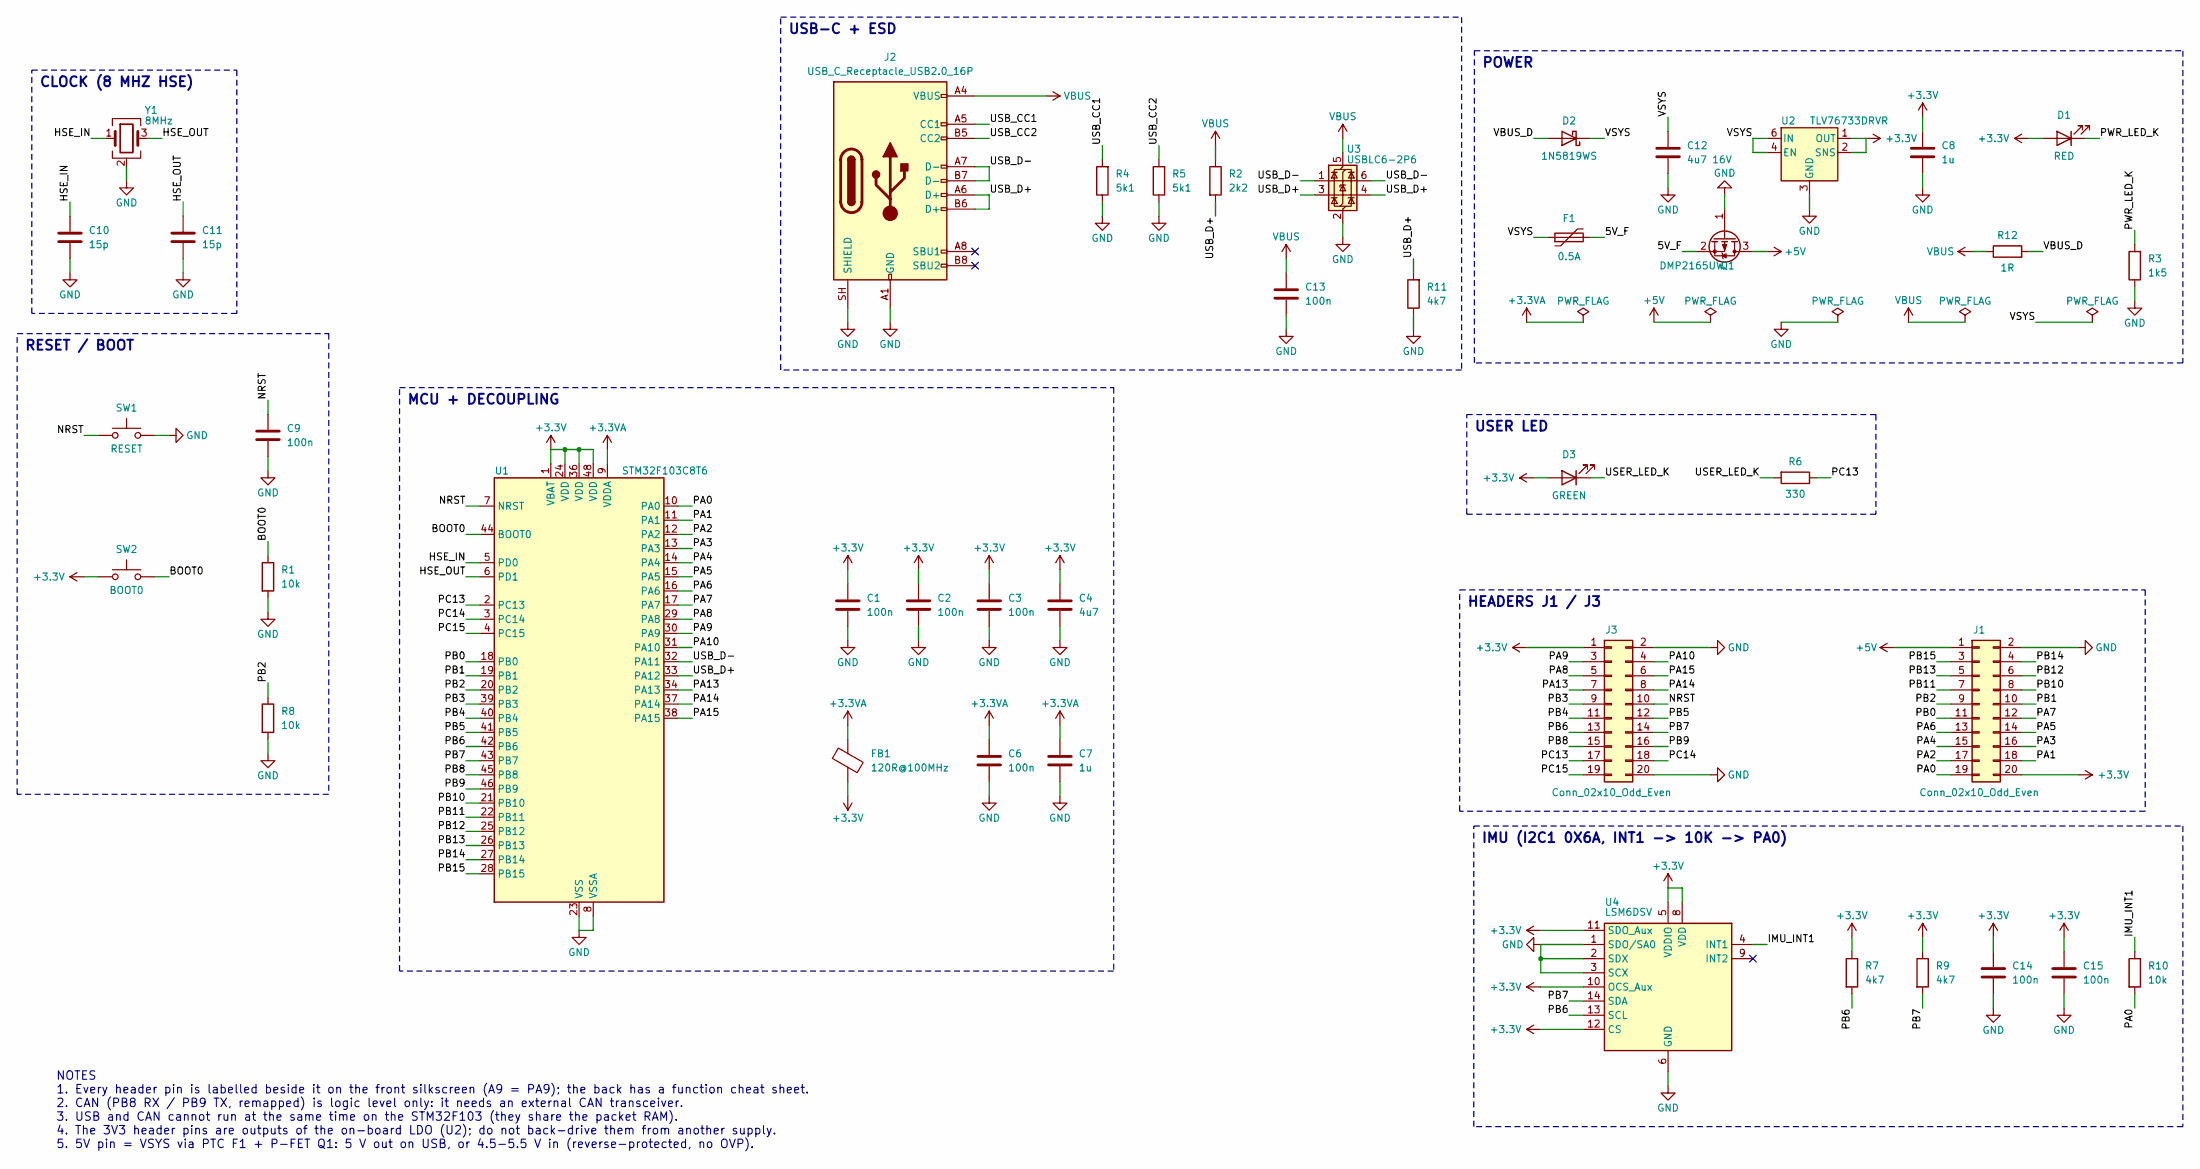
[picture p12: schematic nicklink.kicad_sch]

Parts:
C1, C2, C3, C6, C9, C13, C14, C15: 100n; C_0402_1005Metric; LCSC C1525
C4: 4u7; C_0402_1005Metric; LCSC C23733
C7, C8: 1u; C_0402_1005Metric; LCSC C52923
C10, C11: 15p; C_0402_1005Metric; LCSC C1548
C12: 4u7 16V; C_0402_1005Metric; MPN Samsung CL05A475MO5NUNC; LCSC C318563
D1: RED; LED_0402_1005Metric; MPN Everlight 16-213/R6C-AQ2R2B/3T; LCSC C264407
D2: 1N5819WS; D_SOD-323; LCSC C191023
D3: GREEN; LED_0402_1005Metric; MPN Everlight 16-213/GHC-YR1S1/3T; LCSC C74338
F1: 0.5A; Fuse_0805_2012Metric; MPN LUTE 0805L050/16XR; LCSC C22435898
FB1: 120R@100MHz; L_0402_1005Metric; LCSC C85812
J1, J3: Conn_02x10_Odd_Even; PinHeader_2x10_P2.54mm_Vertical_NoSilk; MPN HanElectricity 2541WV-2x10P (male, 6 mm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; LCSC C5383109
J2: USB_C_Receptacle_USB2.0_16P; USB_C_Receptacle_GCT_USB4085_EdgeSilk; MPN GCT USB4085-GF-A; LCSC C7095263
Q1: DMP2165UW; SOT-323_SC-70_NoSilk; MPN Diodes DMP2165UW-7; LCSC C388477
R1, R10: 10k; R_0402_1005Metric; LCSC C25744
R2: 2k2; R_0402_1005Metric; LCSC C25879
R3: 1k5; R_0402_1005Metric; LCSC C25867
R4: 5k1; R_0402_1005Metric; LCSC C25905
R5: 5k1; R_0402_1005Metric_NoSilk; LCSC C25905
R6: 330; R_0402_1005Metric; LCSC C25104
R7, R9: 4k7; R_0402_1005Metric; LCSC C25900
R8: 10k; R_0402_1005Metric_NoSilk; LCSC C25744
R11: 4k7; R_0402_1005Metric_NoSilk; LCSC C25900
R12: 1R; R_0805_2012Metric; MPN YAGEO SR0805FR-471RL; LCSC C873764
SW1: RESET; SW_SPST_B3U-1000P_NoSilk; LCSC C231329
SW2: BOOT0; SW_SPST_B3U-1000P_NoSilk; LCSC C231329
U1: STM32F103C8T6; LQFP-48_7x7mm_P0.5mm; LCSC C8734
U2: TLV76733DRVR; WSON-6-1EP_2x2mm_P0.65mm_EP1x1.6mm_ThermalVias03; MPN TI TLV76733DRVR; LCSC C2848334
U3: USBLC6-2P6; SOT-666; LCSC C15999
U4: LSM6DSV; LGA-14_3x2.5mm_P0.5mm_LayoutBorder3x4y_NoSilk; MPN ST LSM6DSV (JLC: LSM6DSVETR); LCSC C41785564
Y1: 8MHz; Crystal_SMD_3225-4Pin_3.2x2.5mm; MPN YXC X32258MOB4SI (CL 12 pF); LCSC C2682775

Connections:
+3.3V: C1.1, C2.1, C3.1, C4.1, C8.1, C14.1, C15.1, D1.2 (A), D3.2 (A), FB1.2, J1.20, J3.1, R7.1, R9.1, SW2.1, U1.1 (VBAT), U1.24 (VDD), U1.36 (VDD), U1.48 (VDD), U2.1 (OUT), U2.2 (SNS), U4.5 (VDDIO), U4.8 (VDD), U4.10 (OCS_Aux), U4.11 (SDO_Aux), U4.12 (CS)
+3.3VA: C6.1, C7.1, FB1.1, U1.9 (VDDA)
+5V: J1.1, Q1.3 (D)
/5V_F: F1.2, Q1.2 (S)
/BOOT0: R1.1, SW2.2, U1.44 (BOOT0)
/HSE_IN: C10.1, U1.5 (PD0), Y1.1
/HSE_OUT: C11.1, U1.6 (PD1), Y1.3
/IMU_INT1: R10.1, U4.4 (INT1)
/NRST: C9.1, J3.10, SW1.1, U1.7 (NRST)
/PA0: J1.19, R10.2, U1.10 (PA0)
/PA1: J1.18, U1.11 (PA1)
/PA2: J1.17, U1.12 (PA2)
/PA3: J1.16, U1.13 (PA3)
/PA4: J1.15, U1.14 (PA4)
/PA5: J1.14, U1.15 (PA5)
/PA6: J1.13, U1.16 (PA6)
/PA7: J1.12, U1.17 (PA7)
/PA8: J3.5, U1.29 (PA8)
/PA9: J3.3, U1.30 (PA9)
/PA10: J3.4, U1.31 (PA10)
/PA13: J3.7, U1.34 (PA13)
/PA14: J3.8, U1.37 (PA14)
/PA15: J3.6, U1.38 (PA15)
/PB0: J1.11, U1.18 (PB0)
/PB1: J1.10, U1.19 (PB1)
/PB2: J1.9, R8.1, U1.20 (PB2)
/PB3: J3.9, U1.39 (PB3)
/PB4: J3.11, U1.40 (PB4)
/PB5: J3.12, U1.41 (PB5)
/PB6: J3.13, R7.2, U1.42 (PB6), U4.13 (SCL)
/PB7: J3.14, R9.2, U1.43 (PB7), U4.14 (SDA)
/PB8: J3.15, U1.45 (PB8)
/PB9: J3.16, U1.46 (PB9)
/PB10: J1.8, U1.21 (PB10)
/PB11: J1.7, U1.22 (PB11)
/PB12: J1.6, U1.25 (PB12)
/PB13: J1.5, U1.26 (PB13)
/PB14: J1.4, U1.27 (PB14)
/PB15: J1.3, U1.28 (PB15)
/PC13: J3.17, R6.1, U1.2 (PC13)
/PC14: J3.18, U1.3 (PC14)
/PC15: J3.19, U1.4 (PC15)
/PWR_LED_K: D1.1 (K), R3.2
/USB_CC1: J2.A5 (CC1), R4.2
/USB_CC2: J2.B5 (CC2), R5.2
/USB_D+: J2.A6 (D+), J2.B6 (D+), R2.2, R11.2, U1.33 (PA12), U3.3 (I/O2), U3.4 (I/O2)
/USB_D-: J2.A7 (D-), J2.B7 (D-), U1.32 (PA11), U3.1 (I/O1), U3.6 (I/O1)
/USER_LED_K: D3.1 (K), R6.2
/VBUS_D: D2.2 (A), R12.2
/VSYS: C12.1, D2.1 (K), F1.1, U2.4 (EN), U2.6 (IN)
GND: C1.2, C2.2, C3.2, C4.2, C6.2, C7.2, C8.2, C9.2, C10.2, C11.2, C12.2, C13.2, C14.2, C15.2, J1.2, J2.A1 (GND), J2.A12 (GND), J2.B1 (GND), J2.B12 (GND), J2.SH (SHIELD), J3.2, J3.20, Q1.1 (G), R1.2, R3.1, R4.1, R5.1, R8.2, R11.1, SW1.2, U1.8 (VSSA), U1.23 (VSS), U1.35 (VSS), U1.47 (VSS), U2.3 (GND), U2.5 (GND), U2.7 (GND), U3.2 (GND), U4.1 (SDO/SA0), U4.2 (SDX), U4.3 (SCX), U4.6 (GND), U4.7 (GND), Y1.2 (G), Y1.4 (G)
VBUS: C13.1, J2.A4 (VBUS), J2.A9 (VBUS), J2.B4 (VBUS), J2.B9 (VBUS), R2.1, R12.1, U3.5 (VBUS)

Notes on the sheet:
CLOCK (8 MHZ HSE)
RESET / BOOT
MCU + DECOUPLING
USB-C + ESD
POWER
USER LED
HEADERS J1 / J3
IMU (I2C1 0X6A, INT1 -> 10K -> PA0)
NOTES 1. Every header pin is labelled beside it on the front silkscreen (A9 = PA9); the back has a function cheat sheet. 2. CAN (PB8 RX / PB9 TX, remapped) is logic level only: it needs an external CAN transceiver. 3. USB and CAN cannot run at the same time on the STM32F103 (they share the packet R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

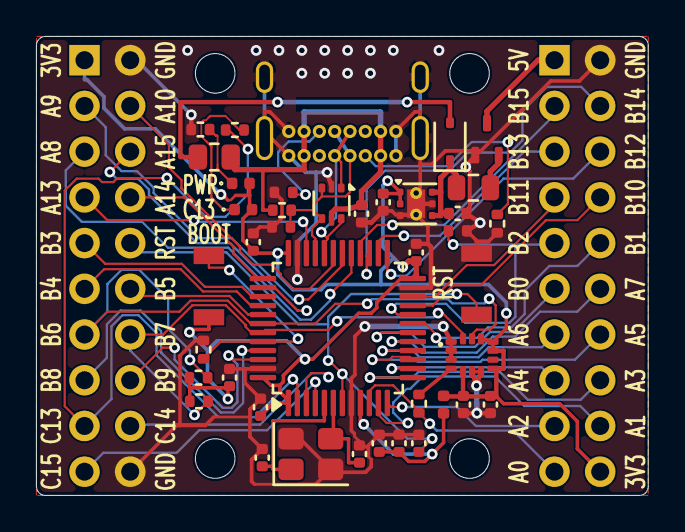
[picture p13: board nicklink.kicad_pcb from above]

Board: 2 copper layers, 34.0 x 25.5 mm, 46 parts (0 on the bottom side), 52 nets.

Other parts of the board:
H1: H1; MountingHole_2.2mm_M2_ISO7380
H2: H2; MountingHole_2.2mm_M2_ISO7380
H3: H3; MountingHole_2.2mm_M2_ISO7380
H4: H4; MountingHole_2.2mm_M2_ISO7380

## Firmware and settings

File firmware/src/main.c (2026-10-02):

/* NickLink v1.3 board-test firmware (STM32F103C8, bare metal).
 * USART1 console on PA9/PA10 at 115200 8N1. Type `help`. */
#include <stdio.h>
#include <string.h>
#include <stdlib.h>
#include "regs.h"
#include "pins.h"

/* Tap/wake tuning knobs (LSM6DSV units, same as LSM6DSV16X: tap 1 LSB = FS/32 = 62.5 mg at +-2 g, wake 1 LSB = 7.8 mg) */
#define TAP_THS  8      /* 0.5 g */
#define WAKE_THS 32     /* 0.25 g */
#define TAP_DUR  0x7A   /* DUR=7 (double-tap window), QUIET=2, SHOCK=2 */

#define IMU_ADDR 0x6A
enum { IN_ANALOG = 0x0, IN_FLOAT = 0x4, IN_PULL = 0x8, OUT_PP = 0x2, OUT_OD = 0x6, AF_PP = 0xB, AF_OD = 0xF };

static volatile uint32_t ticks;          /* ms since boot */
static volatile int led_auto = 1;
static volatile uint8_t rxbuf[64];
static volatile uint8_t rx_head, rx_tail;
static volatile int int1_pending;
static volatile uint32_t sysclk = 8000000;
static const char *volatile clock_msg = "HSI 8 MHz";
static uint32_t reset_csr;
static int imu_ok;
static int standby_wake;

/* ---- basics ----------------------------------------------------------- */
void SysTick_Handler(void) {
    ticks++;
    if (led_auto && ticks % 500 == 0) GPIO_ODR(PC) ^= 1u << 13;
}

static void delay_ms(uint32_t ms) { uint32_t t0 = ticks; while (ticks - t0 < ms) {} }

static void pin_mode(int port, int pin, int mode) {
    volatile uint32_t *cr = pin < 8 ? &GPIO_CRL(port) : &GPIO_CRH(port);
    int sh = (pin & 7) * 4;
    *cr = (*cr & ~(0xFu << sh)) | ((uint32_t)mode << sh);
}
static void pin_set(int port, int pin, int v) { if (v) GPIO_BSRR(port) = 1u << pin; else GPIO_BRR(port) = 1u << pin; }
static int pin_get(int port, int pin) { return (GPIO_IDR(port) >> pin) & 1; }

/* bounded wait: true if cond came true within ~100 ms of HSI-speed loops */
#define WAIT(cond) ({ uint32_t n_ = 200000; while (!(cond) && --n_) {} n_ != 0; })
#define CR_HSION (1u << 0)
#define CR_HSIRDY (1u << 1)
#define CR_HSEON (1u << 16)
#define CR_HSERDY (1u << 17)
#define CR_CSSON (1u << 19)
#define CR_PLLON (1u << 24)
#define CR_PLLRDY (1u << 25)
#define SWS() ((RCC_CFGR >> 2) & 3)

/* Clock security system: if the crystal dies, hardware switches SYSCLK to HSI and raises NMI.
 * Keep running on HSI 8 MHz and record it; `info` reports it. */
void NMI_Handler(void) {
    if (!(RCC_CIR & (1u << 7))) return;                         /* CSSF */
    RCC_CIR |= 1u << 23;                                        /* CSSC: clear it, or NMI fires forever */
    sysclk = 8000000;
    SYST_RVR = sysclk / 1000 - 1; SYST_CVR = 0;
    USART1_BRR = (sysclk + 57600) / 115200;
    clock_msg = "HSE FAILED at runtime (CSS) -> running on HSI 8 MHz";
}

static void clock_init(void) {
    /* don't assume a fresh reset (bootloader GO, soft reset): HSI as SYSCLK, PLL/CSS/HSE off */
    RCC_CR |= CR_HSION;
    WAIT(RCC_CR & CR_HSIRDY);
    RCC_CFGR &= ~3u;
    WAIT(SWS() == 0);
    RCC_CR &= ~(CR_CSSON | CR_PLLON);
    RCC_CIR |= 1u << 23;
    WAIT(!(RCC_CR & CR_PLLRDY));
    RCC_CR &= ~CR_HSEON;
    RCC_CR |= CR_HSEON;
    int hse = WAIT(RCC_CR & CR_HSERDY);                         /* ~100 ms on HSI */
    FLASH_ACR = 0x12;                                           /* prefetch, 2 wait states */
    /* APB1 /2, ADC /6 (12 MHz, max 14), USBPRE=0 (/1.5) */
    if (hse) { RCC_CR |= CR_CSSON; RCC_CFGR = (7u << 18) | (1u << 16) | (4u << 8) | (2u << 14); }  /* PLL = HSE x9 = 72 MHz */
    else { RCC_CR &= ~CR_HSEON; RCC_CFGR = (14u << 18) | (4u << 8) | (2u << 14); }  /* PLL = HSI/2 x16 = 64 MHz */
    RCC_CR |= CR_PLLON;
    if (!WAIT(RCC_CR & CR_PLLRDY)) { clock_msg = "PLL did not lock, staying on HSI 8 MHz"; return; }
    RCC_CFGR |= 2;                                              /* SW = PLL */
    if (!WAIT(SWS() == 2)) { clock_msg = "switch to PLL failed (SWS), staying on HSI 8 MHz"; return; }
    sysclk = hse ? 72000000 : 64000000;
    clock_msg = hse ? "HSE 8 MHz -> PLL x9 = 72 MHz (APB1 36 MHz, ADC 12 MHz, USB 48 MHz), CSS on"
                    : "HSE FAILED to start -> HSI/2 x16 = 64 MHz (USB unusable)";
}

/* ---- console ---------------------------------------------------------- */
void USART1_IRQHandler(void) {
    if (USART1_SR & (1u << 5)) {                                /* RXNE */
        uint8_t c = USART1_DR, n = (rx_head + 1) % sizeof rxbuf;
        if (n != rx_tail) { rxbuf[rx_head] = c; rx_head = n; }
    }
}
static int getch(void) {
    if (rx_head == rx_tail) return -1;
    int c = rxbuf[rx_tail]; rx_tail = (rx_tail + 1) % sizeof rxbuf; return c;
}
static void putch(char c) { while (!(USART1_SR & (1u << 7))) {} USART1_DR = c; }
int _write(int fd, const char *p, int n) {
    (void)fd;
    for (int i = 0; i < n; i++) { if (p[i] == '\n') putch('\r'); putch(p[i]); }
    return n;
}
static void uart_init(void) {
    pin_mode(PA, 9, AF_PP);
    pin_mode(PA, 10, IN_PULL); pin_set(PA, 10, 1);             /* pull-up: idle-high if nothing is connected */
    USART1_BRR = (sysclk + 57600) / 115200;
    USART1_CR1 = (1u << 13) | (1u << 5) | (1u << 3) | (1u << 2); /* UE RXNEIE TE RE */
    NVIC_ISER1 = 1u << (37 - 32);
}

/* ---- I2C1 (polled) ---------------------------------------------------- */
#define SR1_SB 0x1
#define SR1_ADDR 0x2
#define SR1_BTF 0x4
#define SR1_RXNE 0x40
#define SR1_TXE 0x80
#define SR1_AF 0x400
#define CR1_START 0x100
#define CR1_STOP 0x200
#define CR1_ACK 0x400

static int i2c_wait(uint32_t flag) {
    uint32_t t0 = ticks;
    while (!(I2C1_SR1 & flag)) {
        if (I2C1_SR1 & SR1_AF) { I2C1_SR1 = ~SR1_AF; return -1; }  /* NACK */
        if (ticks - t0 > 10) return -2;
    }
    return 0;
}
static int i2c_start(uint8_t addr8) {
    I2C1_CR1 |= CR1_START;
    if (i2c_wait(SR1_SB)) return -2;
    I2C1_DR = addr8;
    return i2c_wait(SR1_ADDR);
}
static int i2c_fail(int e) { I2C1_CR1 |= CR1_STOP; return e; }

static int i2c_write(uint8_t addr, uint8_t reg, const uint8_t *buf, int n) {
    int e;
    if ((e = i2c_start(addr << 1))) return i2c_fail(e);
    (void)I2C1_SR2;
    I2C1_DR = reg;
    for (int i = 0; i < n; i++) { if ((e = i2c_wait(SR1_TXE))) return i2c_fail(e); I2C1_DR = buf[i]; }
    if ((e = i2c_wait(SR1_BTF))) return i2c_fail(e);
    I2C1_CR1 |= CR1_STOP;
    return 0;
}
/* ponytail: NACK/STOP is set after the second-to-last byte (not RM0008's exact N=2/N=3 dance); fine while
 * no ISR stalls > ~80 us at 100 kHz. Move to DMA or the RM sequence if longer ISRs appear. */
static int i2c_read(uint8_t addr, uint8_t reg, uint8_t *buf, int n) {
    int e;
    if ((e = i2c_start(addr << 1))) return i2c_fail(e);
    (void)I2C1_SR2;
    I2C1_DR = reg;
    if ((e = i2c_wait(SR1_BTF))) return i2c_fail(e);
    if ((e = i2c_start((addr << 1) | 1))) return i2c_fail(e);
    if (n == 1) I2C1_CR1 &= ~CR1_ACK; else I2C1_CR1 |= CR1_ACK;
    (void)I2C1_SR2;
    if (n == 1) I2C1_CR1 |= CR1_STOP;
    for (int i = 0; i < n; i++) {
        if ((e = i2c_wait(SR1_RXNE))) return i2c_fail(e);
        buf[i] = I2C1_DR;
        if (i == n - 2) { I2C1_CR1 &= ~CR1_ACK; I2C1_CR1 |= CR1_STOP; }
    }
    return 0;
}
static int i2c_probe(uint8_t addr) {
    int e = i2c_start(addr << 1);
    (void)I2C1_SR2;
    I2C1_CR1 |= CR1_STOP;
    return e == 0;
}
static void i2c_init(void) {
    RCC_APB1ENR |= 1u << 21;
    /* bus recovery (F103 BUSY lock-up after a reset mid-transfer): clock SCL until the slave lets SDA go */
    pin_set(PB, 6, 1); pin_set(PB, 7, 1);
    pin_mode(PB, 6, OUT_OD); pin_mode(PB, 7, OUT_OD);
    for (int i = 0; i < 9 && !pin_get(PB, 7); i++) {
        pin_set(PB, 6, 0); delay_ms(1); pin_set(PB, 6, 1); delay_ms(1);
    }
    pin_set(PB, 7, 0); delay_ms(1); pin_set(PB, 7, 1);         /* STOP */
    pin_mode(PB, 6, AF_OD); pin_mode(PB, 7, AF_OD);
    I2C1_CR1 = 0x8000; I2C1_CR1 = 0;                            /* SWRST */
    uint32_t pclk1 = sysclk / 2, mhz = pclk1 / 1000000;
    I2C1_CR2 = mhz;
    I2C1_CCR = pclk1 / (2 * 100000);                            /* 100 kHz standard mode */
    I2C1_TRISE = mhz + 1;
    I2C1_CR1 = 1;                                               /* PE */
}

/* ---- IMU -------------------------------------------------------------- */
static int imu_wr(uint8_t reg, uint8_t v) { return i2c_write(IMU_ADDR, reg, &v, 1); }
static int imu_rd(uint8_t reg) { uint8_t v; return i2c_read(IMU_ADDR, reg, &v, 1) ? -1 : v; }

void EXTI0_IRQHandler(void) { EXTI_PR = 1; int1_pending++; }

static int imu_init(void) {
    int who = imu_rd(0x0F);
    if (who < 0) { printf("IMU: no ACK at 0x%02X on I2C1 (PB6/PB7)\n", IMU_ADDR); return 0; }
    printf("IMU: WHO_AM_I = 0x%02X %s\n", who, who == 0x70 ? "OK (LSM6DSV family)" : "UNEXPECTED (want 0x70)");
    if (who != 0x70) return 0;
    imu_wr(0x12, 0x01);                                         /* CTRL3 SW_RESET */
    for (uint32_t t0 = ticks; (imu_rd(0x12) & 1) && ticks - t0 < 20;) {}
    int ifcfg = imu_rd(0x03);                                   /* IF_CFG isn't reset by SW_RESET */
    static const uint8_t cfg[][2] = {
        {0x12, 0x44},              /* CTRL3: BDU, IF_INC */
        {0x10, 0x08},              /* CTRL1: accel 480 Hz high-performance (tap wants >= 400 Hz) */
        {0x11, 0x06},              /* CTRL2: gyro 120 Hz */
        {0x15, 0x04},              /* CTRL6: +-2000 dps */
        {0x17, 0x00},              /* CTRL8: +-2 g */
        {0x56, 0x0F},              /* TAP_CFG0: tap X/Y/Z, latched (LIR) */
        {0x57, TAP_THS}, {0x58, TAP_THS}, {0x59, TAP_THS},  /* TAP_CFG1/2, TAP_THS_6D: thresholds */
        {0x5A, TAP_DUR},
        {0x5B, 0x80 | WAKE_THS},   /* WAKE_UP_THS: single+double tap, wake threshold */
        {0x5C, 0x00},              /* WAKE_UP_DUR */
        {0x50, 0x80},              /* FUNCTIONS_ENABLE: INTERRUPTS_ENABLE */
        {0x5E, 0x68},              /* MD1_CFG: INT1 <- single tap | wake-up | double tap */
    };
    int err = ifcfg < 0 || imu_wr(0x03, ifcfg & ~0x18);         /* INT1 push-pull (PP_OD=0), active high */
    for (unsigned i = 0; i < sizeof cfg / sizeof cfg[0]; i++) err |= imu_wr(cfg[i][0], cfg[i][1]);
    if (err || imu_rd(0x5E) != 0x68) { printf("IMU: config write/readback FAILED\n"); return 0; }
    (void)imu_rd(0x1D);                                         /* ALL_INT_SRC: clear any latched event */
    pin_mode(PA, 0, IN_PULL); pin_set(PA, 0, 0);                /* PA0 pull-down: defined even without the IMU */
    AFIO_EXTICR1 &= ~0xFu;                                      /* EXTI0 <- PA0 */
    EXTI_RTSR |= 1; EXTI_PR = 1; EXTI_IMR |= 1;
    NVIC_ISER0 = 1u << 6;
    printf("IMU: 480 Hz, +-2 g, +-2000 dps; tap/double-tap/wake-up -> INT1 -> PA0 (EXTI0 rising)\n");
    return 1;
}

static void imu_sample(void) {
    uint8_t b[14];
    if (!imu_ok || i2c_read(IMU_ADDR, 0x20, b, 14)) { printf("IMU: not available\n"); return; }
    int16_t v[7];
    for (int i = 0; i < 7; i++) v[i] = (int16_t)(b[2 * i] | b[2 * i + 1] << 8);
    int t10 = 250 + v[0] * 10 / 256;                            /* 256 LSB/C, 0 = 25 C */
    printf("IMU: acc mg %d %d %d  gyro dps %d %d %d  temp %s%d.%d C  (raw acc %d %d %d)\n",
           v[4] * 61 / 1000, v[5] * 61 / 1000, v[6] * 61 / 1000,
           v[1] * 70 / 1000, v[2] * 70 / 1000, v[3] * 70 / 1000,
           t10 < 0 ? "-" : "", abs(t10) / 10, abs(t10) % 10, v[4], v[5], v[6]);
}

static void imu_event(void) {
    uint8_t src[2];                                             /* WAKE_UP_SRC, TAP_SRC */
    int ok = !i2c_read(IMU_ADDR, 0x45, src, 2);
    (void)imu_rd(0x1D);                                         /* ALL_INT_SRC read releases the latch */
    if (!ok) { printf("int1 (I2C read failed)\n"); return; }
    if (src[1] & 0x20) printf("tap\n");
    if (src[1] & 0x10) printf("double-tap\n");
    if (src[0] & 0x08) printf("wake\n");
    if (!(src[1] & 0x30) && !(src[0] & 0x08)) printf("int1 (no source: WU 0x%02X TAP 0x%02X)\n", src[0], src[1]);
}

/* ---- board info ------------------------------------------------------- */
static void print_info(void) {
    printf("\nNickLink v" BOARD_REV " board test, SYSCLK %lu Hz\n", (unsigned long)sysclk);
    printf("clock: %s\n", clock_msg);
    printf("RCC_CFGR 0x%08lX, PVD 2.9 V: VDD %s, %s\n", (unsigned long)RCC_CFGR,
           PWR_CSR & (1u << 2) ? "BELOW threshold" : "ok", standby_wake ? "woke from Standby" : "not from Standby");
    uint32_t c = reset_csr;
    printf("reset cause:%s%s%s%s%s%s (RCC_CSR 0x%08lX)\n",
           c & (1u << 27) ? " power-on" : "", c & (1u << 28) ? " software" : "",
           c & (1u << 29) ? " IWDG" : "", c & (1u << 30) ? " WWDG" : "", c & (1u << 31) ? " low-power" : "",
           (c & (0x3Fu << 26)) == (1u << 26) ? " NRST pin (RESET button)" : "", (unsigned long)c);
    /* BOOT0 isn't a GPIO; infer it from what is aliased at 0x0 (flash only when BOOT0 was low at reset) */
    int flash_alias = R32(0x00000004) == R32(0x08000004);
    printf("boot: %s; BOOT1/PB2 reads %d (10k pull-down, want 0)\n",
           flash_alias ? "flash aliased at 0x0 (BOOT0 was low)" : "0x0 is NOT flash (BOOT0 high / started by bootloader)",
           pin_get(PB, 2));
    printf("flash size reg %u KB, UID %08lX%08lX%08lX\n", FLASH_SIZE_KB,
           (unsigned long)UID(2), (unsigned long)UID(1), (unsigned long)UID(0));
}

static void print_pins(void) {
    printf("LQFP  func   net      header  function / on-board load\n");
    for (unsigned i = 0; i < N_MCU_PINS; i++) {
        const mcu_pin_t *p = &MCU_PINS[i];
        printf("%4u  %-5s  %-7s  %-6s  %s%s%s\n", p->lqfp, p->fn, p->net, p->hdr, p->alias,
               *p->alias && *p->loads ? "; " : "", p->loads);
    }
}

/* ---- GPIO walk / monitor ---------------------------------------------- */
static int skip_pin(const hdr_pin_t *h, int all) {
    if (h->port == PA && (h->pin == 9 || h->pin == 10)) return 1;           /* console */
    return !all && h->port == PA && (h->pin == 13 || h->pin == 14);         /* SWD */
}
static void pins_release(void) {  /* back to normal use after walk/mon */
    for (unsigned i = 0; i < N_HDR_PINS; i++)
        if (!skip_pin(&HDR_PINS[i], 1)) pin_mode(HDR_PINS[i].port, HDR_PINS[i].pin, IN_FLOAT);
    AFIO_MAPR = (AFIO_MAPR & ~(7u << 24)) | (2u << 24);       /* SWD on, JTAG off (frees PA15/PB3/PB4) */
    pin_mode(PC, 13, OUT_PP); led_auto = 1;
    i2c_init(); imu_ok = imu_init();
}
static void pins_pulldown(int all) {
    led_auto = 0; EXTI_IMR &= ~1u;
    if (all) AFIO_MAPR = (AFIO_MAPR & ~(7u << 24)) | (4u << 24);  /* SWD off too: SWD is lost until reset */
    for (unsigned i = 0; i < N_HDR_PINS; i++) {
        const hdr_pin_t *h = &HDR_PINS[i];
        if (!skip_pin(h, all)) { pin_set(h->port, h->pin, 0); pin_mode(h->port, h->pin, IN_PULL); }
    }
}

/* Drive each header GPIO high then low (one at a time, others pulled down) and check that it reads back,
 * and that no other header pin follows it (solder bridge). Probe each pin with a meter/LED as it walks. */
static void cmd_walk(uint32_t ms, int all) {
    int faults = 0, n = 0;
    pins_pulldown(all);
    printf("walk: %lu ms per level%s; any key aborts\n", (unsigned long)ms, all ? ", SWD pins included" : "");
    for (unsigned i = 0; i < N_HDR_PINS && getch() < 0; i++) {
        const hdr_pin_t *h = &HDR_PINS[i];
        if (skip_pin(h, all)) continue;
        uint32_t idr[2][3];
        pin_mode(h->port, h->pin, OUT_PP);
        for (int lvl = 1; lvl >= 0; lvl--) {
            pin_set(h->port, h->pin, lvl);
            printf("WALK %s %s %s\n", h->hdr, h->name, lvl ? "high" : "low");
            delay_ms(ms);
            for (int p = 0; p < 3; p++) idr[lvl][p] = GPIO_IDR(p);
        }
        pin_mode(h->port, h->pin, IN_PULL);
        n++;
        int hi = idr[1][h->port] >> h->pin & 1, lo = idr[0][h->port] >> h->pin & 1;
        if (!hi) { printf("  FAIL %s reads 0 while driven high (short to GND?)\n", h->name); faults++; }
        if (lo) { printf("  FAIL %s reads 1 while driven low (short to 3V3?)\n", h->name); faults++; }
        for (unsigned j = 0; j < N_HDR_PINS; j++) {
            const hdr_pin_t *o = &HDR_PINS[j];
            if (j == i || skip_pin(o, all)) continue;
            if ((idr[1][o->port] >> o->pin & 1) && !(idr[0][o->port] >> o->pin & 1)) {
                printf("  FAIL %s follows %s (short?)\n", o->name, h->name); faults++;
            }
        }
    }
    printf("walk done: %d pins, %d faults\n", n, faults);
    pins_release();
}

/* Loopback/monitor: all header GPIOs as pulled-down inputs; print every level change. */
static void cmd_mon(void) {
    pins_pulldown(0);
    printf("mon: inputs with pull-down, printing changes; any key exits\n");
    uint32_t last[3] = {0}, cur[3];
    for (int first = 1; getch() < 0; first = 0) {
        for (int p = 0; p < 3; p++) cur[p] = GPIO_IDR(p);
        for (unsigned i = 0; i < N_HDR_PINS; i++) {
            const hdr_pin_t *h = &HDR_PINS[i];
            int v = cur[h->port] >> h->pin & 1;
            if (!skip_pin(h, 0) && (first ? v : v != (int)(last[h->port] >> h->pin & 1)))
                printf("mon: %s %s=%d\n", h->hdr, h->name, v);
        }
        memcpy(last, cur, sizeof last);
        delay_ms(5);
    }
    printf("mon done\n");
    pins_release();
}

/* ---- Standby / ADC ---------------------------------------------------- */
/* Standby, wake on a rising edge at PA0/WKUP (A0). The IMU INT1 (push-pull, idles low) drives A0
 * through 10k, so a tap/wake event wakes the MCU. Wake = reset; the banner reports it. */
static void cmd_standby(void) {
    (void)imu_rd(0x1D);                                         /* ALL_INT_SRC: release latched INT1 so it is low */
    pin_mode(PA, 0, IN_FLOAT);                                  /* A0 already has 10k to INT1; no internal pull */
    if (pin_get(PA, 0)) printf("warning: PA0 is high, a rising edge is needed to wake\n");
    printf("entering Standby; rising edge on PA0 (or RESET) wakes\n");
    while (!(USART1_SR & (1u << 6))) {}                         /* TC: let the text out */
    SYST_CSR = 0; USART1_CR1 &= ~(1u << 5); EXTI_IMR &= ~1u;    /* no pending interrupt may cancel WFI */
    PWR_CR |= (1u << 2) | (1u << 1);                            /* CWUF, PDDS */
    PWR_CSR |= 1u << 8;                                         /* EWUP */
    SCB_SCR |= 1u << 2;                                         /* SLEEPDEEP */
    __asm volatile("wfi");
    SCB_AIRCR = 0x05FA0004;                                     /* WFI fell through (debugger?): reset */
}

/* ADC1 single conversions: PA0-PA7 = ch0-7, PB0/PB1 = ch8/9, VREFINT = ch17. ADC clock 12 MHz,
 * 239.5-cycle sample (~21 us, covers VREFINT's 17.1 us minimum). Pins are analog only while it runs. */
static int adc_read(int ch) {
    ADC1_SQR3 = (uint32_t)ch;
    ADC1_CR2 |= 1u << 22;                                       /* SWSTART */
    uint32_t t0 = ticks;
    while (!(ADC1_SR & 2)) if (ticks - t0 > 5) return -1;       /* EOC */
    return ADC1_DR & 0xFFF;                                     /* DR read clears EOC */
}
static void cmd_adc(void) {
    uint32_t cra = GPIO_CRL(PA), crb = GPIO_CRL(PB);
    RCC_APB2ENR |= 1u << 9;                                     /* ADC1EN */
    ADC1_SMPR1 = 0x00FFFFFF; ADC1_SMPR2 = 0x3FFFFFFF; ADC1_SQR1 = 0;
    ADC1_CR2 = 1u;                                              /* ADON */
    delay_ms(1);
    ADC1_CR2 = 1u | (7u << 17) | (1u << 20) | (1u << 23);       /* EXTSEL=SWSTART, EXTTRIG, TSVREFE */
    ADC1_CR2 |= 1u << 3; for (uint32_t t0 = ticks; (ADC1_CR2 & (1u << 3)) && ticks - t0 < 5;) {}   /* RSTCAL */
    ADC1_CR2 |= 1u << 2; for (uint32_t t0 = ticks; (ADC1_CR2 & (1u << 2)) && ticks - t0 < 5;) {}   /* CAL */
    delay_ms(1);                                                /* VREFINT start-up */
    GPIO_CRL(PA) = 0;                                           /* PA0-7 analog */
    GPIO_CRL(PB) = (crb & ~0xFFu);                              /* PB0/PB1 analog */
    int vref = adc_read(17);
    uint32_t vdda = vref > 0 ? 1200u * 4095u / (uint32_t)vref : 0;  /* VREFINT 1.20 V typ (1.16-1.24) */
    printf("VREFINT raw %d -> VDDA ~%lu mV\n", vref, (unsigned long)vdda);
    for (int ch = 0; ch < 10; ch++) {
        int v = adc_read(ch);
        if (v < 0) printf("%s%d ch%d: timeout\n", ch < 8 ? "PA" : "PB", ch < 8 ? ch : ch - 8, ch);
        else printf("%s%d ch%d: raw %4d = %4lu mV\n", ch < 8 ? "PA" : "PB", ch < 8 ? ch : ch - 8, ch,
                    v, (unsigned long)v * vdda / 4095);
    }
    GPIO_CRL(PA) = cra; GPIO_CRL(PB) = crb;
    ADC1_CR2 = 0; RCC_APB2ENR &= ~(1u << 9);
}
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
int main(void) {
    reset_csr = RCC_CSR;
    RCC_APB1ENR |= 1u << 28;                                    /* PWR clock */
    standby_wake = PWR_CSR & (1u << 1);                         /* SBF */
    PWR_CR |= (1u << 3) | (7u << 5) | (1u << 4);                /* CSBF, PLS=111 (2.9 V), PVDE; polled, no EXTI16 */
    RCC_CSR |= 1u << 24;                                        /* RMVF: clear reset flags for next time */
    clock_init();
    RCC_APB2ENR |= (1u << 0) | (1u << 2) | (1u << 3) | (1u << 4) | (1u << 14);  /* AFIO, GPIOA/B/C, USART1 */
    AFIO_MAPR = (AFIO_MAPR & ~(7u << 24)) | (2u << 24);       /* SWD only: frees PA15/PB3/PB4 as GPIO */
    SYST_RVR = sysclk / 1000 - 1; SYST_CVR = 0; SYST_CSR = 7;
    pin_mode(PC, 13, OUT_PP); pin_set(PC, 13, 1);              /* user LED off (active low) */
    usb_detach();
    uart_init();
    setvbuf(stdout, NULL, _IONBF, 0);
    print_info();
    i2c_init();
    imu_ok = imu_init();
    printf("type 'help'\n> ");

    char line[48];
    unsigned len = 0;
    for (;;) {
        if (int1_pending) { int1_pending = 0; imu_event(); }
        int c = getch();
        if (c < 0) continue;
        if (c == '\r' || c == '\n') {
            printf("\n"); line[len] = 0; run(line); len = 0; printf("> ");
        } else if ((c == 8 || c == 127) && len) { len--; printf("\b \b"); }
        else if (c >= ' ' && len < sizeof line - 1) { line[len++] = c; putch(c); }
    }
}

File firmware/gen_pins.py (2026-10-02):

#!/usr/bin/env python3
"""Generate build/pins.h from tools/spec.py so the firmware's pin map can't drift from the hardware.

Also cross-checks spec.py against the STM32F103 LQFP-48 datasheet pinout: every
MCU pin whose net is named after a GPIO must sit on that GPIO's package pin.
"""
import os, re, sys

sys.path.insert(0, os.path.join(os.path.dirname(os.path.abspath(__file__)), "..", "tools"))
import spec  # noqa: E402

# DS5319 Table 5, LQFP48 column
LQFP48 = [None, "VBAT", "PC13", "PC14", "PC15", "PD0", "PD1", "NRST", "VSSA", "VDDA",
          "PA0", "PA1", "PA2", "PA3", "PA4", "PA5", "PA6", "PA7", "PB0", "PB1", "PB2",
          "PB10", "PB11", "VSS", "VDD", "PB12", "PB13", "PB14", "PB15", "PA8", "PA9", "PA10",
          "PA11", "PA12", "PA13", "VSS", "VDD", "PA14", "PA15", "PB3", "PB4", "PB5", "PB6",
          "PB7", "BOOT0", "PB8", "PB9", "VSS", "VDD"]
GPIO = re.compile(r"^P([A-D])(\d+)$")

parts = spec.PARTS
mcu = parts["U1"][3]
assert len(mcu) == 48, len(mcu)
for p, net in mcu.items():
    if GPIO.match(net):
        assert LQFP48[int(p)] == net, f"U1.{p} is {LQFP48[int(p)]} but spec net is {net}"

hdr = {}  # net -> "J1.19"
for ref in ("J1", "J3"):
    for p, net in parts[ref][3].items():
        hdr.setdefault(net, f"{ref}.{p}")


def loads(net):
    """On-board parts on this net other than the MCU and headers, e.g. 'R8 10k'."""
    out = []
    for ref, (_, val, _, pins, _) in sorted(parts.items()):
        if ref in ("U1", "J1", "J3"):
            continue
        nets = list(pins.values())
        if net in nets:
            other = sorted({n for n in nets if n != net})
            out.append(f"{ref} {val.split('_')[0]}" + (f" to {'/'.join(other)}" if len(other) == 1 else ""))
    return ", ".join(out)


def c(s):
    return '"' + s.replace('"', '\\"') + '"'


rows, walk = [], []
for p in range(1, 49):
    net = mcu[str(p)]
    fn = LQFP48[p]
    m = GPIO.match(fn)
    port, pin = ("ABCD".index(m.group(1)), int(m.group(2))) if m else (0xFF, 0)
    rows.append(f"  {{{p}, {c(fn)}, {c(net)}, {c(hdr.get(net, '') if net not in spec.POWER_NETS else '')}, {c(spec.ALIASES.get(net, ''))}, "
                f"{c(loads(net) if net not in spec.POWER_NETS else '')}, {port}, {pin}}},")

for ref in ("J1", "J3"):
    for p, net in sorted(parts[ref][3].items(), key=lambda kv: int(kv[0])):
        m = GPIO.match(net)
        if m:
            walk.append(f"  {{{c(net)}, {c(f'{ref}.{p}')}, {'ABCD'.index(m.group(1))}, {int(m.group(2))}}},")

print(f"""/* GENERATED by gen_pins.py from tools/spec.py (rev {spec.REV}) -- do not edit */
#pragma once
#include <stdint.h>
#define BOARD_REV "{spec.REV}"
typedef struct {{ uint8_t lqfp; const char *fn, *net, *hdr, *alias, *loads; uint8_t port, pin; }} mcu_pin_t;
typedef struct {{ const char *name, *hdr; uint8_t port, pin; }} hdr_pin_t;
static const mcu_pin_t MCU_PINS[] = {{
{chr(10).join(rows)}
}};
/* header GPIOs in header order (J1 then J3) */
static const hdr_pin_t HDR_PINS[] = {{
{chr(10).join(walk)}
}};
#define N_MCU_PINS (sizeof MCU_PINS / sizeof MCU_PINS[0])
#define N_HDR_PINS (sizeof HDR_PINS / sizeof HDR_PINS[0])""")
assert len(walk) == 33, len(walk)

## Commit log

2026-09-10 NickLink v1.1 — compact STM32F103C8 breakout board
    34 x 33 mm two-layer board with USB-C, AMS1117-3.3 regulator, 16 MHz
    crystal, BOOT0 switch and two 2x10 2.54 mm Dupont-compatible headers.
    48.7% smaller in area than the original layout with all four M2
    mounting holes retained.
    Verified with KiCad 10: 0 DRC violations, 0 unconnected items,
    0 schematic parity issues, 0 ERC violations.
    Includes schematic, PCB, gerbers, drills, BOM, placement data,
    renders and design review.
    [nicklink.kicad_pcb, nicklink.kicad_sch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]
2026-09-11 Polish public repo: MIT license, nicklink naming, docs sync
    Add MIT LICENSE, rename pcb_hello_world footprints/fab files to nicklink,
    align README area claim with REVIEW (49.7%), and fix REVIEW paths to match
    what this repository actually ships.
    [nicklink-B_Cu.gbl, nicklink-B_Mask.gbs, nicklink-B_Paste.gbp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]
2026-10-01 NickLink v1.2 — smaller board, front pin labels, QoL fixes
    Board shrinks from 34 x 33 mm to 33.19 x 25.5 mm (-25% area) while keeping
    both 2x10 headers and all four M2 holes, and every header pin is now labelled
    beside it on the front silkscreen.
    Hardware changes:
    - 5 V on J1.1 (USB VBUS via 1N5819WS Schottky; usable as a <=5.5 V input)
    - RESET and BOOT buttons (B3U); NRST moved to J3 next to SWDIO/SWCLK/SWO
    - 8 MHz HSE crystal (was 16 MHz), 15 pF load caps
    - TLV75533 WSON LDO + ceramics replaces AMS1117 + tantalum
    - USBLC6-2P6 ESD on D+/D-/VBUS
    - I2C pull-ups on PB6/PB7 removed; user LED on PC13
    - Header pinout reordered to follow the MCU package order
    The design is now generated: tools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
    [nicklink-B_Cu.gbl, nicklink-B_Mask.gbs, nicklink-B_Paste.gbp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]
2026-10-01 compare.py: any number of boards, outline-only entries
    Claude-Session: https://claude.ai/code/session_01KPMtzubqGeBFaq48UcVZaf
2026-10-01 NickLink v1.3 — on-board 6-axis IMU (LSM6DSV16X)
    Adds an ST LSM6DSV16X accel+gyro on I2C1 (PB6/PB7, address 0x6A) with
    INT1 on PA0 (WKUP), for motion tracking, robotics and tap-to-wake use.
    Placed on the top side (single-sided assembly): the board grows to
    33.19 x 28.8 mm (956 mm^2, still -15% vs v1.1). Pinout unchanged from v1.2.
    - 4.7k I2C1 pull-ups restored (on-board device on the bus)
    - Project symbol nicklink:LSM6DSV16X; top-copper keep-out under the package
    - Crystal nets pre-routed as locked top-layer tracks (no vias)
    - USBLC6 channels swapped so D+/D- don't cross at the MCU
    - Min track width 0.10 mm to accept Freerouting neck-downs
    - build_pcb.py --resilk for silkscreen-only edits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
    [nicklink-B_Cu.gbl, nicklink-B_Mask.gbs, nicklink-B_Paste.gbp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]
2026-10-02 v1.3: JLCPCB design rules, IMU moved into existing gaps (25.5 mm tall)
    JLCPCB 2-layer + Economic PCBA limits are now enforced by DRC
    (board setup + nicklink.kicad_dru): 0.18 mm component annular ring,
    0.15 mm SMD pad-to-pad, 0.45 mm pad hole-to-hole, 0.5 mm plated slots,
    0.3 mm copper-to-edge, 0.15 mm silk-to-pad, 0.10 mm mask web,
    1.0 mm / 0.15 mm silkscreen text and lines.
    Changes to comply:
    - USB4085 pads 0.36 mm hole / 0.72 mm pad (was 0.40/0.70 = 0.15 ring),
    shield pads +0.06 mm
    - pin labels 1.0 mm tall; label strips 1.2 -> 1.4 mm; all silk >= 0.15 mm
    - back legend reflowed to clear the mounting holes
    The IMU now sits in the right channel below RESET (caps beneath it), the
    ferrite i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
    [board_template.kicad_pcb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]
2026-10-02 v1.3: fix the five-reviewer audit findings
    Independent reviews (power, MCU, USB, IMU/headers, fab/DFM) found issues that
    would have made the board fail or be unreliable. Fixed:
    - CPL: per-footprint JLC rotation corrections (LQFP-48 -90, SOT-666 +180,
    LGA-14 +180), verified against JLC's EasyEDA footprints. As shipped, U1
    would have been rotated 90 deg and U3 would have shorted VBUS to GND.
    - LDO: output cap C8 now 0.95 mm from OUT; C12 -> 10 uF 0603; two 0.3 mm
    thermal vias in the exposed pad (project WSON footprint).
    - IMU INT1 (forced low at power-up) now reaches A0 through R10 10k.
    - USB4085: 0.38 mm holes / 0.74 mm pads (inside GCT's 0.40 +-0.05 spec,
    JLC 0.18 mm ring), thermal-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
    [nicklink-B_Cu.gbl, nicklink-B_Mask.gbs, nicklink-B_Paste.gbp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]
2026-10-02 docs: current seed and pre-route notes
    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
2026-10-02 v1.3 reliability pass: protected power path, STM32 best practices, SPICE + emulated test firmware
    Power: R12 1R anti-surge in series with VBUS (hot-plug ring 6.1-11.4 V -> 5.38 V
    at LDO IN, inrush 33 uC); C12 4.7 uF, 3V3 10 uF bulk removed; F1 0.5 A PTC + Q1
    DMP2165UW reverse-polarity FET on the J1.1 5V pin branch.
    STM32: 4.7 uF on VDD3 (DS5319 Fig. 14); D+ pull-up from VBUS (R2 2k2 + R11 4k7,
    AN4879 3.1.1) so J1.1 power no longer back-feeds the host; R6 330R user LED.
    Layout: locked USB-C orientation ties, VBUS path U3 -> C13 -> J2, IMU GND return
    via its caps, GND vias for R3/VSS_2; seed 12 baked, finished with the new
    tools/fixroute.sh grid router. stitch.py checks connectivity per pour i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
    [nicklink-B_Cu.gbl, nicklink-B_Mask.gbs, nicklink-B_Paste.gbp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]
2026-10-02 v1.3 second review wave: TLV76733 LDO, VBUS_D off the USB shell, IMU spacing, firmware fixes
    Five reviewers (power C+, MCU B, USB B, IMU/GPIO B+, fab B+); all must-fixes done:
    - U2 TLV75533 -> TLV76733DRVR (same DRV0006A pads, VIN/EN 18 V): J1.1 hot-plug
    rang VSYS past the TLV755's 6 V abs max. SNS->OUT, pin 5->GND stubs. C12 16 V.
    New SPICE bench 12 (J1.1 hot-plug, 1.5-3 uH USB cables).
    - VBUS_D hops to B.Cu under the USB4085 shell; F.Cu keep-out over its GND dimples.
    - IMU: pour keep-out off the GND pads, bottom GND via outside the body.
    - Net classes: signals 0.127/0.127 mm, GND and new Rail class (3V3) 0.2 mm; seed 3
    now routes 100% with Freerouting alone. DRC 0/0/0, ERC 0/0, one G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
    [nicklink-B_Cu.gbl, nicklink-B_Mask.gbs, nicklink-B_Paste.gbp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]
2026-10-02 docs: v1.1 / v1.2 / v1.3 comparison in the README
    Revision table split into v1.1 | v1.2 | v1.3 columns (adds the power-path,
    D+ pull-up and verification rows). Comparison image renamed to
    compare-v1.1-v1.2-v1.3.png (so no cached two-board copy is shown) and a
    true-size version for a 27-inch 1440p monitor added.
    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
2026-10-02 fab: JLC upload set (gerber zip, SMD-only BOM)
    fab.sh now also writes fabrication/<rev>/nicklink_gerbers.zip and
    nicklink_BOM_JLC.csv (Comment/Designator/Footprint/LCSC, THT parts left
    out since they are hand-soldered). README says which files to upload.
    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
    [nicklink-B_Cu.gbl, nicklink-B_Mask.gbs, nicklink-B_Paste.gbp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]
2026-10-02 JLC order fixes: LSM6DSV IMU, THT by JLC, one-line-per-part BOM, Gerber-frame CPL
    Placing the first real JLCPCB Economic PCBA order for v1.3 turned up
    problems that DRC and the review waves didn't catch. Copper is unchanged
    (Gerbers regenerate identical apart from timestamps).
    - U4: LSM6DSV16X (C5267406) -> LSM6DSV (C41785564). JLC lists the
    LSM6DSV16X as "Standard PCBA only" (X-ray); the LSM6DSV is allowed on
    Economic. Same LGA-14 pinout and I2C wiring, same registers for
    everything the firmware and SFLP use, WHO_AM_I 0x70. It lacks the MLC,
    Qvar and analog hub, none of which the board uses. Project symbol
    renamed; board/schematic fields updated (DRC parity 0).
    - J1/J3 get LCSC C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
    [nicklink.kicad_pcb, nicklink.kicad_sch, nicklink_BOM.csv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]
2026-10-03 docs: bring-up guide with STLINK-V3MINIE wiring and a prebuilt test firmware
    docs/BRINGUP.md: first power, STLINK-V3MINIE (STDC14) -> J3 wiring (SWD, NRST,
    T_VCC sense, VCP on USART1 per UM2910 Table 4), flashing with CubeProgrammer /
    OpenOCD / st-flash, the console banner, and a 14-step checklist covering power,
    crystal (MCO), LEDs, RESET/BOOT, IMU (scan, data, tap/wake), every header GPIO
    (walk/mon), ADC and Standby wake, plus troubleshooting. Pictures are drawn on a
    3D render from the board's real pad positions (tools/bringup_img.sh).
    firmware/prebuilt: the test firmware as .hex/.bin (Renode suite 10/10).
    README links the guide.
    Cla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
2026-10-04 docs: describe the fitted TLV76733 board, not the TLV755 study
    Bring-up, the parts notes, and the SPICE write-up still told a builder to fit the 6 V LDO, a 10 µF input cap, and a hand-soldered header. The JLC files already use the 18 V TLV76733, the 4.7 µF 16 V 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
2026-10-14 firmware: USB DFU bootloader and USB-C console for bring-up
    After a one-time ST-Link flash of prebuilt/nicklink-full.hex, boards take
    new firmware over USB-C with `make dfu`. The ST-Link is only needed to
    recover a board or to install a new bootloader.
    Bootloader (firmware/bootloader/): dapboot at a pinned commit, with a
    NickLink target in the first 8 KiB. It enters DFU (1209:db42) on the
    test firmware's `dfu` command, a double-tap of RESET, J1.9 held high at
    reset, or no valid app. A dead crystal falls back to HSI instead of
    hanging, and the USB serial matches the app's chip UID.
    Test firmware: now linked at 0x08002000. It adds a bare-metal CDC ACM
    console (1209:0001) alongside USART1 and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
2026-10-14 README: IMU axes relative to the board and USB-C
    The LSM6DSV is placed at 0 deg, so +X points toward J1, +Y toward the
    USB-C connector and +Z out of the component side (top view, USB-C up).
    Adds a diagram, the gyro sign convention, and which axis reads +1 g in
    each orientation. Flat and USB-C up were measured on a v1.3 board.
    Claude-Session: https://claude.ai/code/session_017LucoBJmh2YFvzHpYSamwe
2026-10-14 firmware: IMU stream command and a live 3D viewer
    `stream [hz]` sends raw accel + gyro samples at a fixed rate until any
    key: `S <ms> ax ay az gx gy gz`, 200 Hz by default. While a terminal has
    the USB port open the samples go to USB alone, so USART1's 115200 baud
    doesn't limit them. The gyro now runs at 480 Hz, so every sample is
    fresh. Measured on hardware: exactly 200.0 and 100.0 Hz, no bad lines.
    firmware/imu_viewer.py (PyQt6 + numpy) starts the stream and measures
    the gyro offset while the board is still. It fuses gyro and gravity
    (Madgwick) and draws the board in 3D, using its real dimensions and part
    positions from nicklink.kicad_pcb.
    - The drawing is a painter's algorithm in slabs p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
